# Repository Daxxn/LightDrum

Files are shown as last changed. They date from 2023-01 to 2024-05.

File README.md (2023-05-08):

# LightDrum

### Have you ever wanted the drum set to be the loudest thing on stage? Well... this won't do that, but it will be extremely visible!

---

This is my dads christmas present. (I dont even remember how long it's been...) The idea is to lay strings of LEDs on his drum set and control the strings with audio and MIDI signals. With the ability to control more lighting systems through the DMX interface. The other purpose of this project is to learn. To that end, all interface libraries are written by me and are not feature complete or fully tested.

> Current Revision: `REV12`
>
> All revisions before REV8 are early prototypes and are for archival. They are not fully functional or feature complete.

# Renders

## Main PCB

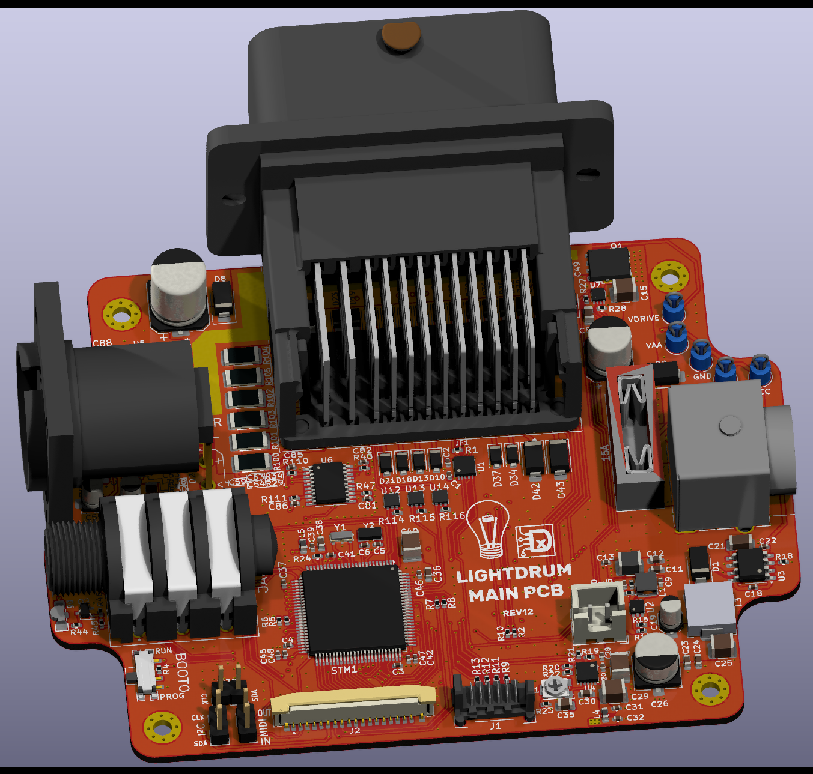
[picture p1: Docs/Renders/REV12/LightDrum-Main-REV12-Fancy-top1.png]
Render 1


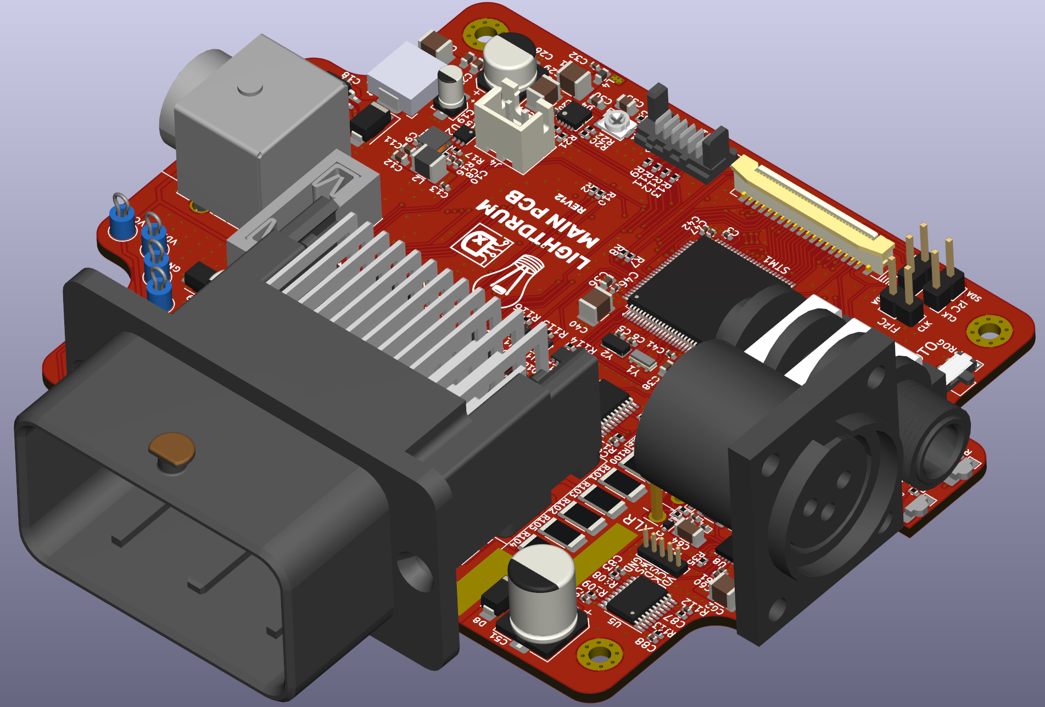
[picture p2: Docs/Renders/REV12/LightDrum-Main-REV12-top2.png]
Render 2


## Interface PCB

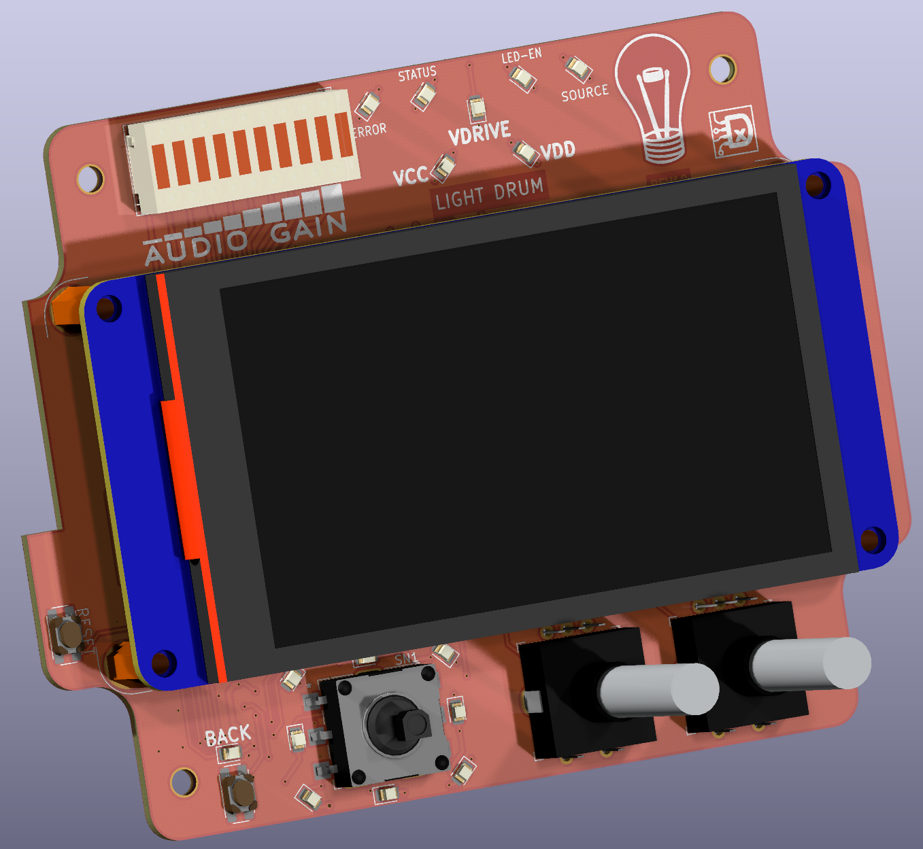
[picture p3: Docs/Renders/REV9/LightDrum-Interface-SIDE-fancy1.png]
Render 3


## Features

### Output
- 8 Individual LED String Channels
- 1 Amp Rating per Channel
- DMX (RS-485) Interface

## Input
- 1/8" jack Audio
- XLR Balanced Audio
- MIDI
- DMX (RS-485) Interface

## PWM channels

The 8 individual RGB channels are controlled with 3 [PCA9634.](https://www.nxp.com/docs/en/data-sheet/PCA9634.pdf) Providing 8-bit PWM steps per channel with overall brightness and multiplexing.

## Bulk Lighting

The new automitive ECU connector has allowed for more pins, hense, some extra features. This includes 3 linear LED drivers for white COB LEDs. These are very bright and can either be controlled through the user interface, MIDI, or audio.

## Power Management

Each channel includes current monitoring with a high-side power override. This is all to avoid shorts and over-current conditions on the high current 12V supply. Both barrel jacks will need to be used for the LEDs to be activated. Due the large amount of power required, one barrel jack would probably melt.

## Audio Processing

The PCM1821 dual channel 32bit audio ADC handles the audio conversion and is sent to the MCU via I2S. Theres some minor filtering and impedance matching in the analog front-end. However, most of the audio processing will be handled in software.

## User Interface

- 3.2" TFT LCD Display
- Navigation Hat Switch for menu navigation
- Bar Graphs for display of audio levels and current load (or anything else I can think of.)
- 2 Contextual Rotary Encoders
- AND; a reset switch. For when things go horribly wrong.
- MicroSD card slot for loading lighting profiles and other options by the user.

The display contains a full menu to select modes, configure options, and IO. I'm using a Nextion display and their GUI editor for all the menuing. Its not the most performant display but it does allow for easy integration of a reasonably high res, full color screen.

In the future, Im planning to upgrade to a faster STM32 MCU, something like an F7, H5, or H7. Taking advantage of the TouchGFX GUI design software and integrate the screen control into the main MCU. Even with the faster MCU, it will be cheaper and increase screen performance, due to the removal of the Nextion display.

---

## Documentation

- [Docs](./Docs/)

- [Interactive BOMs](./Docs/BOMs/REV10/)

- TODO: Link to a user manual and theory of operation doc.

---

## Firmware installation

### Hardware Requirements

The old firmware was built with the Arduino Framework. The new MCU will be using the ST IDE, toolchain, and HAL (Hardware Abstraction Layer) along with the other required libraries. Im using the STLink programmer due to the much better performance and debugging than the ATTiny USB programmer.

### OLD PIO Configuration

[env:megaUSB] : Uses the built-in programmer. This is only used for the older revisions. (REV1 & REV2)

[env:megaICSP] : Main programming method. Using the ATTiny USB programmer.

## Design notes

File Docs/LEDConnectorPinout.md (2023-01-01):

# LED Connector Pinout

Pinout for the main LED strip D-Sub connector.

> Pin Count : 37
> 
> Max Current: 1A

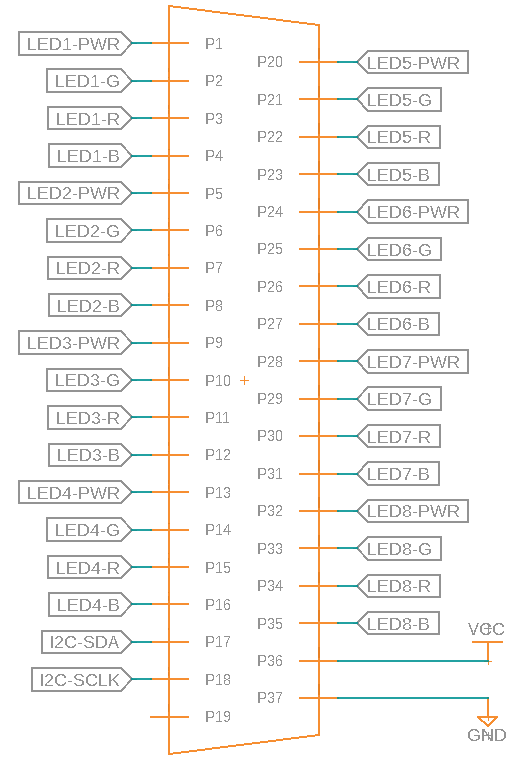
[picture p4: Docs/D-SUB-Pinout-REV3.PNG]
D-Sub Pinout Image


| # | Name | Description |
| --- | --- | --- |
| P1 | LED1-PWR | LED Strip Channel 1 +12V |
| P2 | LED1-G | Channel 1 Green |
| P3 | LED1-R | Channel 1 Red |
| P4 | LED1-B | Channel 1 Blue |
| P5 | LED2-PWR | LED Strip Channel 2 +12V |
| P6 | LED2-G | Channel 2 Green |
| P7 | LED2-R | Channel 2 Red |
| P8 | LED2-B | Channel 2 Blue |
| P9 | LED3-PWR | LED Strip Channel 3 +12V |
| P10 | LED3-G | Channel 3 Green |
| P11 | LED3-R | Channel 3 Red |
| P12 | LED3-B | Channel 3 Blue |
| P13 | LED4-PWR | LED Strip Channel 4 +12V |
| P14 | LED4-G | Channel 4 Green |
| P15 | LED4-R | Channel 4 Red |
| P16 | LED4-B | Channel 4 Blue |
| P17 | I2C-SDA | I2C Data |
| P18 | I2C-SCLK | I2C Clock |
| P19 | NC | Not Connected |
| P20 | LED5-PWR | LED Strip Channel 5 +12V |
| P21 | LED5-G | Channel 5 Green |
| P22 | LED5-R | Channel 5 Red |
| P23 | LED5-B | Channel 5 Blue |
| P24 | LED6-PWR | LED Strip Channel 6 +12V |
| P25 | LED6-G | Channel 6 Green |
| P26 | LED6-R | Channel 6 Red |
| P27 | LED6-B | Channel 6 Blue |
| P28 | LED7-PWR | LED Strip Channel 7 +12V |
| P29 | LED7-G | Channel 7 Green |
| P30 | LED7-R | Channel 7 Red |
| P31 | LED7-B | Channel 7 Blue |
| P32 | LED8-PWR | LED Strip Channel 8 +12V |
| P33 | LED8-G | Channel 8 Green |
| P34 | LED8-R | Channel 8 Red |
| P35 | LED8-B | Channel 8 Blue |
| P36 | VCC | VCC - +5V |
| P37 | GND | System Ground |

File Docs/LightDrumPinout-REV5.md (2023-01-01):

# LightDrumREV5

> > Micro: **MEGA 2560**
>
> > Digital Pins: **54**
> >
> > Analog Pins: **16**
>
> > Comms:
> > - SPI
> > - I2C
> > - UART0
> > - UART1
> > - UART2
> > - UART3

---

## Digital

### Menu
Pin Count: 6

| Pin | Name | Type
| --- | --- | --- |
| 1114 | BACK | IN |
| 8 | ACT | IN |
| 9 | UP | IN |
| 6 | LEFT | IN |
| 114 | RIGHT | IN |
| 7 | DOWN | IN |

### ROM
Pin Count: 1

| Pin | Name | Type
| --- | --- | --- |
| 1149 | WP | OUT |

### Power
Pin Count: 1

| Pin | Name | Type
| --- | --- | --- |
| 63 | STRIP_EN | OUT |

### ADC
Pin Count: 1

| Pin | Name | Type
| --- | --- | --- |
| 12 | STATUS | IN |

### Audio
Pin Count: 2

| Pin | Name | Type
| --- | --- | --- |
| 1148 | HP_SW | IN |
| 16 | AUDIO_SEL | OUT |

### Encoder
Pin Count: 6

| Pin | Name | Type
| --- | --- | --- |
| 2 | A1 | IN |
| 118 | B1 | IN |
| 10 | SW1 | IN |
| 3 | A2 | IN |
| 119 | B2 | IN |
| 11 | SW2 | IN |

### Screen
Pin Count: 11

| Pin | Name | Type
| --- | --- | --- |
| 37 | D0 | OUT |
| 36 | D1 | OUT |
| 35 | D2 | OUT |
| 34 | D3 | OUT |
| 33 | D4 | OUT |
| 32 | D5 | OUT |
| 31 | D6 | OUT |
| 30 | D7 | OUT |
| 39 | RS | OUT |
| 41 | RW | OUT |
| 40 | EN | OUT |

### Diag
Pin Count: 2

| Pin | Name | Type
| --- | --- | --- |
| 26 | STATUS | OUT |
| 27 | DEBUG | OUT |

### Graph
Pin Count: 4

| Pin | Name | Type
| --- | --- | --- |
| 17 | SDI | OUT |
| 1 | CLK | OUT |
| 4 | LE | OUT |
| 5 | OE | PWM |

### Midi
Pin Count: 1

| Pin | Name | Type
| --- | --- | --- |
| 0 | IN | IN |

### Strip
Pin Count: 1

| Pin | Name | Type
| --- | --- | --- |
| 46 | OE | OUT |

## Analog

### Audio
Pin Count: 1

| Pin | Name | Type
| --- | --- | --- |
| 10 | ARAW | IN |

### Current
Pin Count: 8

| Pin | Name | Type
| --- | --- | --- |
| 2 | ASTRIP_1 | IN |
| 5 | ASTRIP_2 | IN |
| 1 | ASTRIP_3 | IN |
| 6 | ASTRIP_4 | IN |
| 4 | ASTRIP_5 | IN |
| 3 | ASTRIP_6 | IN |
| 7 | ASTRIP_7 | IN |
| 0 | ASTRIP_8 | IN |

## Serial

### SPI

### Pins

| Name | Pin |
| --- | --- |
| SCLK | 52 |
| MISO | 50 |
| MOSI | 51 |
| SS | 53 |

### Addresses

| Name | Pin |
| --- | --- |
| ADC | 13 |

### I2C

### Pins

| Name | Pin |
| --- | --- |
| SCLK | 21 |
| SDA | 20 |

### Addresses

| Name | Pin |
| --- | --- |
| ROM | 160 |
| BackLight | 248 |
| StripA | 42 |
| StripB | 24 |
| StripC | 43 |

### UART0

### Pins

| Name | Pin |
| --- | --- |
| TX | 1 |
| RX | 0 |

### UART1

### Pins

| Name | Pin |
| --- | --- |
| TX | 18 |
| RX | 19 |

### UART2

### Pins

| Name | Pin |
| --- | --- |
| TX | 16 |
| RX | 17 |

### UART3

### Pins

| Name | Pin |
| --- | --- |
| TX | 14 |
| RX | 15 |

> Auto-generated by [PinGenerator app.](https://github.com/Daxxn/PinGenerator)
>
> Author: Daxxn

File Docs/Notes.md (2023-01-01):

# Notes and other things

* The Power Barrel Jacks need to be moved in from the edge. Theres only about 2mm from the edge of the board to the enclosure wall. OR try to find a higher current rated power connector.

* [Fixed] Add pullups to the barrel jack switches.

* [Fixed] The ICSP header needs to be moved away from the relays and any other obstructions.

* [Fixed] Still waiting on all the resistor/capacitor values for the filters.

* [Fixed] The rotary encoders need to be moved to the interface board.

* [Fixed] Look into a cable to connect the main and interface boards. The pinheader is realy hard to align and the flex during assembly is too high.

* Check the footprint and pin 1 indicator for the digital POT. Theres something wrong there.

* The brightness POT doesnt have an acceptable range. 10K is too high. The brightness goes from nothing to full only at the very end of travel.

* [Fixed] Move the XLR connector from the outside to the inside.

* [Fixed] add another MIDI connector for output communication.

* [Fixed] Move the RESET line resistor from the interface board to the main board.

* [Fixed] Move the electrolytic cap for the power supply to the top layer.

* [Fixed] Up the priority for the LED indicator power nets.

* [Fixed] Swap out the resonator for a crystal.

* [Good] TRIPLE check the symbol and footprint for the ATMEGA2560

* [Fixed] Waiting on the proper current sense resistors.

* [Fixed] Change the I2C address for Strip controller C. It was copied incorrectly from Fusion 360.

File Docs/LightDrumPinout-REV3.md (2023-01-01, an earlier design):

# LightDrum

> > Micro: **MEGA 2560**
>
> > Digital Pins: **54**
> >
> > Analog Pins: **16**
>
> > Comms:
> > - SPI
> > - I2C
> > - UART0
> > - UART1
> > - UART2
> > - UART3

---

## Digital

### LED
Pin Count: 4

| Pin | Name | Type
| --- | --- | --- |
| 36 | SDI | OUT |
| 37 | CLK | OUT |
| 40 | LE | OUT |
| 41 | OE | OUT |

### LCD
Pin Count: 11

| Pin | Name | Type
| --- | --- | --- |
| 42 | D0 | OUT |
| 43 | D1 | OUT |
| 44 | D2 | OUT |
| 45 | D3 | OUT |
| 46 | D4 | OUT |
| 49 | D5 | OUT |
| 48 | D6 | OUT |
| 47 | D7 | OUT |
| 38 | RS | OUT |
| 18 | RW | OUT |
| 19 | EN | OUT |

### POWER
Pin Count: 1

| Pin | Name | Type
| --- | --- | --- |
| 69 | RELAY | OUT |

### BUTTONS
Pin Count: 5

| Pin | Name | Type
| --- | --- | --- |
| 14 | ACT | IN |
| 27 | HOME | IN |
| 29 | M_UP | IN |
| 25 | M_DOWN | IN |
| 24 | MODE | IN |

### ENCODER
Pin Count: 6

| Pin | Name | Type
| --- | --- | --- |
| 4 | A1 | IN |
| 59 | B1 | IN |
| 0 | SW1 | IN |
| 61 | A2 | IN |
| 62 | B2 | IN |
| 60 | SW2 | IN |

### AUDIO
Pin Count: 3

| Pin | Name | Type
| --- | --- | --- |
| 34 | XLR_SW | IN |
| 31 | HP_SW | IN |
| 17 | MIDI | IN |

### INDICATOR
Pin Count: 5

| Pin | Name | Type
| --- | --- | --- |
| 22 | M_DOWN | IN |
| 28 | M_UP | IN |
| 26 | HOME | IN |
| 23 | MODE | IN |
| 39 | ACT | IN |

## Analog

### CURR_SENSE
Pin Count: 8

| Pin | Name | Type
| --- | --- | --- |
| 13 | AS0 | IN |
| 11 | AS1 | IN |
| 4 | AS2 | IN |
| 2 | AS3 | IN |
| 12 | AS4 | IN |
| 10 | AS5 | IN |
| 3 | AS6 | IN |
| 1 | AS7 | IN |

## Serial

### SPI

### Pins

| Name | Pin |
| --- | --- |
| SCLK | 52 |
| MISO | 50 |
| MOSI | 51 |
| SS | 53 |

### Select Pins

| Name | Pin |
| --- | --- |
| SPECT_CS | 68 |

### I2C

### Pins

| Name | Pin |
| --- | --- |
| SCLK | 21 |
| SDA | 20 |

### Select Pins

| Name | Pin |
| --- | --- |
| PWM_OE | 16 |

### Addresses

| Name | Pin |
| --- | --- |
| PWM0 | 1 |
| PWM1 | 2 |
| PWM2 | 3 |
| MEM | 0 |

### UART0

### Pins

| Name | Pin |
| --- | --- |
| TX | 1 |
| RX | 0 |

### UART1

### Pins

| Name | Pin |
| --- | --- |
| TX | 18 |
| RX | 19 |

### UART2

### Pins

| Name | Pin |
| --- | --- |
| TX | 16 |
| RX | 17 |

### UART3

### Pins

| Name | Pin |
| --- | --- |
| TX | 14 |
| RX | 15 |

> Auto-generated by [PinGenerator app.](https://github.com/Daxxn/PinGenerator)
>
> Author: Daxxn

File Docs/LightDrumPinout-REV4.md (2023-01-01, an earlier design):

# LightDrumREV4

> > Micro: **MEGA 2560**
>
> > Digital Pins: **54**
> >
> > Analog Pins: **16**
>
> > Comms:
> > - SPI
> > - I2C
> > - UART0
> > - UART1
> > - UART2
> > - UART3

---

## Digital

### LCD
Pin Count: 11

| Pin | Name | Type
| --- | --- | --- |
| 42 | D0 | IO |
| 43 | D1 | IO |
| 44 | D2 | IO |
| 45 | D3 | IO |
| 46 | D4 | IO |
| 49 | D5 | IO |
| 48 | D6 | IO |
| 47 | D7 | IO |
| 38 | RS | OUT |
| 18 | RW | OUT |
| 19 | EN | OUT |

### IND
Pin Count: 5

| Pin | Name | Type
| --- | --- | --- |
| 26 | HOME | OUT |
| 28 | M_UP | OUT |
| 22 | M_DN | OUT |
| 39 | ACT | OUT |
| 23 | MODE | OUT |

### ENC
Pin Count: 4

| Pin | Name | Type
| --- | --- | --- |
| 4 | ENC1_A | IN |
| 59 | ENC1_B | IN |
| 61 | ENC2_A | IN |
| 62 | ENC2_B | IN |

### SWITCH
Pin Count: 7

| Pin | Name | Type
| --- | --- | --- |
| 27 | HOME | IN |
| 14 | ACT | IN |
| 29 | M_UP | IN |
| 25 | M_DN | IN |
| 24 | MODE | IN |
| 0 | ENC1 | IN |
| 60 | ENC2 | IN |

### PWR
Pin Count: 3

| Pin | Name | Type
| --- | --- | --- |
| 111 | INV_EN | OUT |
| 69 | PWR_EN | OUT |

### AUDIO
Pin Count: 2

| Pin | Name | Type
| --- | --- | --- |
| 31 | HP_SW | IN |
| 34 | HP_XLR | OUT |

### LED
Pin Count: 5

| Pin | Name | Type
| --- | --- | --- |
| 36 | SDI | OUT |
| 37 | CLK | OUT |
| 40 | LE | OUT |
| 41 | OE | OUT |
| 16 | PWM_OE | OUT |

## Analog

### CURR
Pin Count: 8

| Pin | Name | Type
| --- | --- | --- |
| 13 | ASNS_1 | IN |
| 11 | ASNS_2 | IN |
| 4 | ASNS_3 | IN |
| 2 | ASNS_4 | IN |
| 12 | ASNS_5 | IN |
| 10 | ASNS_6 | IN |
| 3 | ASNS_7 | IN |
| 1 | ASNS_8 | IN |

## Serial

### SPI

### Pins

| Name | Pin |
| --- | --- |
| SCLK | 52 |
| MISO | 50 |
| MOSI | 51 |
| SS | 53 |

### Select Pins

| Name | Pin |
| --- | --- |
| SPECT_CS | 5 |

### I2C

### Pins

| Name | Pin |
| --- | --- |
| SCLK | 21 |
| SDA | 20 |

### Addresses

| Name | Pin |
| --- | --- |
| LED1 | 42 |
| LED2 | 24 |
| LED3 | 30 |
| ROM | 160 |

### UART0

### Pins

| Name | Pin |
| --- | --- |
| TX | 1 |
| RX | 0 |

### UART1

### Pins

| Name | Pin |
| --- | --- |
| TX | 18 |
| RX | 19 |

### UART2

### Pins

| Name | Pin |
| --- | --- |
| TX | 16 |
| RX | 17 |

### UART3

### Pins

| Name | Pin |
| --- | --- |
| TX | 14 |
| RX | 15 |

> Auto-generated by [PinGenerator app.](https://github.com/Daxxn/PinGenerator)
>
> Author: Daxxn

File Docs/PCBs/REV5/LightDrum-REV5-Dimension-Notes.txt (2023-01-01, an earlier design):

height from top: 33.16
len from side: 15.65

possible cosin error: 0.4

lip height: 1.48

inner wall height: 39.26

main PCB level: 30.18

dsub center to edge: 49
dsub outer shield width: 56.3 | 28.15
dsub outer shield height: 9.4 | 4.7

top-jack y len: 34.96
bot-jack y len: 49.96
jack spacing: 15

jack width: 8.95
jack: height: 10.85

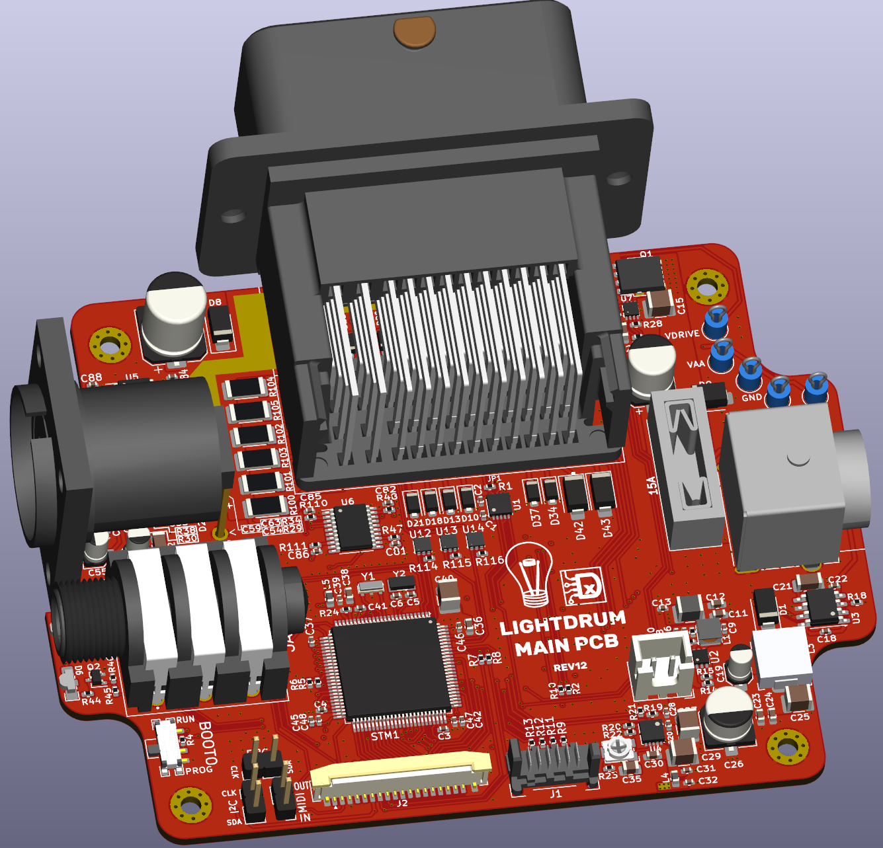
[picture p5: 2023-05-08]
Docs/Renders/REV12/LightDrum-Main-REV12-top1.png

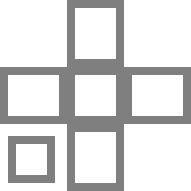
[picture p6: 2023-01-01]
Docs/D-Pad.png

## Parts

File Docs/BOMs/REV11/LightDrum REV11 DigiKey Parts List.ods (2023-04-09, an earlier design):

I | Digi-Key Part # | Manufacturer Part # | Description | Req QTY | Pack QTY | Pack Type | Unit Price | Extended Price | Min QTY | Availability | Stock Status | Customer Reference | Manufacturer Name | Datasheet
1 | 296-PCM1821IRTERCT-ND | PCM1821IRTER | STEREO-CHANNEL, 32-BIT, 192-KHZ, | 1 | 1 | Cut Tape (CT) | 4.05000 | $4.05 | 1 | 5,576 | In Stock |  | Texas Instruments | https://www.ti.com/general/docs/suppproductinfo.tsp?distId=10&gotoUrl=https://www.ti.com/lit/gpn/pcm1821
2 | 497-18547-ND | STM32F412VET3 | IC MCU 32BIT 512KB FLASH 100LQFP | 1 | 1 | Tray | 12.40000 | $12.40 | 1 | 472 | In Stock |  | STMicroelectronics | https://www.st.com/content/ccc/resource/technical/document/datasheet/15/90/07/b3/8c/10/4e/95/DM00213872.pdf/files/DM00213872.pdf/jcr:content/translations/en.D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
3 | 401-2016-1-ND | PCM12SMTR | SWITCH SLIDE SPDT 300MA 6V | 1 | 1 | Cut Tape (CT) | 0.93000 | $0.93 | 1 | 28,298 | In Stock |  | C&K | https://www.ckswitches.com/media/1424/pcm.pdf
4 | 568-4066-1-ND | PCA9634PW,118 | IC LED DRVR PS I2C 25MA 20TSSOP | 3 | 3 | Cut Tape (CT) | 2.15000 | $6.45 | 1 | 1,482 | In Stock |  | NXP USA Inc. | https://www.nxp.com/docs/en/data-sheet/PCA9634.pdf
5 | 1827-1047-1-ND | SLG55021-200010V | IC GATE DRVR HIGH-SIDE 8TDFN | 1 | 1 | Cut Tape (CT) | 0.63000 | $0.63 | 1 | 337,781 | In Stock |  | Renesas Design Germany GmbH | https://www.renesas.com/us/en/document/dst/slg55021-200010v-datasheet?language=en
6 | 497-18335-1-ND | STR485LVQT | IC TRANSCEIVER HALF 1/1 10DFN | 1 | 1 | Cut Tape (CT) | 4.50000 | $4.50 | 1 | 18,992 | In Stock |  | STMicroelectronics | https://www.st.com/resource/en/datasheet/str485.pdf
7 | 296-49082-1-ND | INA4181A2IPWR | IC CURR SENSE 4 CIRCUIT 20TSSOP | 2 | 2 | Cut Tape (CT) | 1.25000 | $2.50 | 1 | 5,568 | In Stock |  | Texas Instruments | https://www.ti.com/general/docs/suppproductinfo.tsp?distId=10
8 | AP3401DNTR-G1DICT-ND | AP3401DNTR-G1 | IC REG BUCK ADJ 1A UDFN2020-6 | 1 | 1 | Cut Tape (CT) | 0.45000 | $0.45 | 1 | 261,637 | In Stock |  | Diodes Incorporated | https://www.diodes.com/assets/Datasheets/AP3401.pdf
9 | LM22673MRE-5.0/NOPBCT-ND | LM22673MRE-5.0/NOPB | IC REG BUCK 5V 3A 8SOPWR | 1 | 1 | Cut Tape (CT) | 6.04000 | $6.04 | 1 | 3,893 | In Stock |  | Texas Instruments | https://www.ti.com/general/docs/suppproductinfo.tsp?distId=10
10 | 296-TPS7A9401DSCRCT-ND | TPS7A9401DSCR | 1-A, ULTRA-LOW NOISE, ULTRA-HIGH | 1 | 1 | Cut Tape (CT) | 7.32000 | $7.32 | 1 | 5,948 | In Stock |  | Texas Instruments | https://www.ti.com/lit/ds/symlink/tps7a94.pdf
11 | XC1617CT-ND | ECS-.327-12.5-34B-TR | CRYSTAL 32.7680KHZ 12.5PF SMD | 1 | 1 | Cut Tape (CT) | 0.68000 | $0.68 | 1 | 618,648 | In Stock |  | ECS Inc. | https://ecsxtal.com/store/pdf/ecx-31b.pdf
12 | 490-17948-1-ND | CSTNE16M0V530000R0 | CERAMIC RES 16.0000MHZ 15PF SMD | 1 | 1 | Cut Tape (CT) | 0.25000 | $0.25 | 1 | 150,216 | In Stock |  | Murata Electronics | https://www.murata.com/en/products/productdata/8801162231838/SPEC-CSTNE16M0V530000R0.pdf
13 | 118-TC33X-1-472ECT-ND | TC33X-1-472E | TRIMMER 4.7K OHM 0.1W J LEAD TOP | 1 | 1 | Cut Tape (CT) | 0.28000 | $0.28 | 1 | 4,990 | In Stock |  | Bourns Inc. | https://www.bourns.com/docs/Product-Datasheets/TC33.pdf
14 | 264-CEZ5V6L3FCT-ND | CEZ5V6,L3F | TVS DIODE 5.6VWM 9VC ESC | 4 | 4 | Cut Tape (CT) | 0.31000 | $1.24 | 1 | 7,011 | In Stock |  | Toshiba Semiconductor and Storage | https://toshiba.semicon-storage.com/info/CEZ5V6_datasheet_en_20201026.pdf?did=69323&prodName=CEZ5V6
15 | SMAJ14CA-FDICT-ND | SMAJ14CA-13-F | TVS DIODE 14VWM 23.2VC SMA | 36 | 36 | Cut Tape (CT) | 0.33000 | $11.88 | 1 | 170,451 | In Stock |  | Diodes Incorporated | https://www.diodes.com/assets/Datasheets/SMAJ5.0CA-SMAJ200CA.pdf
16 | 160-2217-1-ND | LTST-S321TBKT | LED BLUE CLEAR 1208 SMD R/A | 2 | 2 | Cut Tape (CT) | 0.36000 | $0.72 | 1 | 36,099 | In Stock |  | Lite-On Inc. | https://optoelectronics.liteon.com/upload/download/DS22-2010-0048/LTST-S321TBKT.pdf
17 | 353-SK36AHE3-LTPCT-ND | SK36AHE3-LTP | DIODE SCHOTTKY 60V 3A DO214AC | 1 | 1 | Cut Tape (CT) | 0.36000 | $0.36 | 1 | 4,900 | In Stock |  | Micro Commercial Co | https://www.mccsemi.com/pdf/Products/SK34AHE3-L-SK310AHE3-L(DO-214AC).pdf
18 | 36-3557-10-ND | 3557-10 | FUSE HOLDER BLADE 30A PCB | 1 | 1 | Bulk | 1.33000 | $1.33 | 1 | 3,903 | In Stock |  | Keystone Electronics | https://www.keyelco.com/userAssets/file/M65p41.pdf
19 | 952-3602-ND | M50-3530642 | CONN HEADER VERT 6POS 1.27MM | 1 | 1 | Box | 0.29000 | $0.29 | 1 | 27,033 | In Stock |  | Harwin Inc. | https://cdn.harwin.com/pdfs/C029XX_M50_and_M52_Series_Connectors.pdf
20 | 2223-SJ-63073E-ND | SJ-63073E | AUDIO JACK, 6.35 MM, HORIZONTAL, | 1 | 1 | Bag | 1.87000 | $1.87 | 1 | 643 | In Stock |  | CUI Devices | https://www.cuidevices.com/product/resource/sj-6307.pdf
21 | 4654-CP30082-ND | CP30082 | FEMALE AIRTIGHT XLR CONNECTOR 90 | 1 | 1 | Box | 8.32000 | $8.32 | 1 | 17 | In Stock |  | CLIFF Electronic Components Ltd | https://www.cliffusa.com/products/xlr/AirtightXLR.pdf
22 | 182-37ME-ND | 182-037-113R531 | CONN D-SUB PLUG 37POS R/A SLDR | 1 | 1 | Tray | 4.22000 | $4.22 | 1 | 6,577 | In Stock |  | NorComp Inc. | https://content.norcomp.net/rohspdfs/Connectors/18Y/182/182-yyy-113Ryy1.pdf
23 | 2092-KPJXHT-4S-S-ND | KPJXHT-4S-S | CONN JACK FMALE 4POS TIN SOLDER | 1 | 1 | Tray | 2.89000 | $2.89 | 1 | 4,408 | In Stock |  | Kycon, Inc. | https://www.kycon.com/Pub_Eng_Draw/KPJXHT-4S-S.pdf
24 | WM7988CT-ND | 0525593652 | CONN FFC VERT 36POS 0.5MM SMD | 1 | 1 | Cut Tape (CT) | 4.91000 | $4.91 | 1 | 13,038 | In Stock |  | Molex | https://www.molex.com/pdm_docs/sd/525593652_sd.pdf
25 | WM6784CT-ND | 0541323662 | CONN FFC BOTTOM 36POS 0.5MM R/A | 1 | 1 | Cut Tape (CT) | 2.30000 | $2.30 | 1 | 3,837 | In Stock |  | Molex | https://www.molex.com/pdm_docs/sd/541323662_sd.pdf
26 | 455-2247-ND | B2B-XH-A(LF)(SN) | CONN HEADER VERT 2POS 2.5MM | 2 | 2 | Bulk | 0.15000 | $0.30 | 1 | 1,157,609 | In Stock |  | JST Sales America Inc. | https://www.jst-mfg.com/product/pdf/eng/eXH.pdf
27 | 732-6275-1-ND | 744786210A | FIXED IND 100NH 300MA 1.2OHM SMD | 3 | 3 | Cut Tape (CT) | 0.21000 | $0.63 | 1 | 14,176 | In Stock |  | Würth Elektronik | https://www.we-online.com/katalog/datasheet/744786210A.pdf
28 | 490-15950-1-ND | LQH3NPN2R2MMEL | FIXED IND 2.2UH 1.22A 78MOHM SMD | 1 | 1 | Cut Tape (CT) | 0.42000 | $0.42 | 1 | 55,677 | In Stock |  | Murata Electronics | https://search.murata.co.jp/Ceramy/image/img/P02/JELF243A-0153.pdf
29 | 553-4011-1-ND | PA4341.223ANLT | FIXED IND 22UH 2.5A 190 MOHM SMD | 1 | 1 | Cut Tape (CT) | 1.11000 | $1.11 | 1 | 4,826 | In Stock |  | Pulse Electronics | https://productfinder.pulseelectronics.com/api/open/part-attachments/datasheet/PA4341.223ANLT
30 | NTMFS5C430NLT1GOSCT-ND | NTMFS5C430NLT1G | MOSFET N-CH 40V 200A 5DFN | 1 | 1 | Cut Tape (CT) | 2.24000 | $2.24 | 1 | 41,366 | In Stock |  | onsemi | https://www.onsemi.com/pdf/datasheet/ntmfs5c430nl-d.pdf
31 | 1727-NX6008NBKWXCT-ND | NX6008NBKWX | NX6008NBKW/SOT323/SC-70 | 6 | 6 | Cut Tape (CT) | 0.23000 | $1.38 | 1 | 63,146 | In Stock |  | Nexperia USA Inc. | https://assets.nexperia.com/documents/data-sheet/NX6008NBKW.pdf
32 | 1727-PMXB43UNEZCT-ND | PMXB43UNEZ | MOSFET N-CH 20V 3.2A DFN1010D-3 | 24 | 24 | Cut Tape (CT) | 0.37000 | $8.88 | 1 | 94,617 | In Stock |  | Nexperia USA Inc. | https://assets.nexperia.com/documents/data-sheet/PMXB43UNE.pdf
33 | 311-10KJRCT-ND | RC0402JR-0710KL | RES 10K OHM 5% 1/16W 0402 | 44 | 100 | Cut Tape (CT) | 0.00820 | $0.82 | 1 | 39,784,616 | In Stock |  | YAGEO | https://www.yageo.com/upload/media/product/productsearch/datasheet/rchip/PYu-RC_Group_51_RoHS_L_12.pdf
34 | 1276-6849-1-ND | CL05C220JB51PNC | CAP CER 22PF 50V C0G/NP0 0402 | 1 | 1 | Cut Tape (CT) | 0.10000 | $0.10 | 1 | 1,749,789 | In Stock |  | Samsung Electro-Mechanics | https://media.digikey.com/pdf/Data%20Sheets/Samsung%20PDFs/CL05C220JB51PNC_Spec.pdf
35 | 1276-6610-1-ND | CL05C470JB51PNC | CAP CER 47PF 50V C0G/NP0 0402 | 2 | 2 | Cut Tape (CT) | 0.10000 | $0.20 | 1 | 659,743 | In Stock |  | Samsung Electro-Mechanics | https://media.digikey.com/pdf/Data%20Sheets/Samsung%20PDFs/CL05C470JB51PNC_Spec.pdf
36 | 1276-1117-1-ND | CL05C471JB5NNNC | CAP CER 470PF 50V C0G/NP0 0402 | 10 | 10 | Cut Tape (CT) | 0.03100 | $0.31 | 1 | 755,442 | In Stock |  | Samsung Electro-Mechanics | https://media.digikey.com/pdf/Data%20Sheets/Samsung%20PDFs/CL05C471JB5NNNC_Spec.pdf
37 | 1276-1028-1-ND | CL05B103KB5NNNC | CAP CER 10000PF 50V X7R 0402 | 1 | 1 | Cut Tape (CT) | 0.10000 | $0.10 | 1 | 11,684,930 | In Stock |  | Samsung Electro-Mechanics | https://media.digikey.com/pdf/Data%20Sheets/Samsung%20PDFs/CL05B103KB5NNN_Spec.pdf
38 | 1276-1043-1-ND | CL05A104KA5NNNC | CAP CER 0.1UF 25V X5R 0402 | 36 | 50 | Cut Tape (CT) | 0.00540 | $0.27 | 1 | 25,861,495 | In Stock |  | Samsung Electro-Mechanics | https://media.digikey.com/pdf/Data%20Sheets/Samsung%20PDFs/CL05A104KA5NNNC.pdf
39 | 1276-1102-1-ND | CL10A105KA8NNNC | CAP CER 1UF 25V X5R 0603 | 11 | 11 | Cut Tape (CT) | 0.03100 | $0.34 | 1 | 1,051,944 | In Stock |  | Samsung Electro-Mechanics | https://media.digikey.com/pdf/Data%20Sheets/Samsung%20PDFs/CL10A105KA8NNNC_Spec.pdf
40 | 399-C0402C150G5HACAUTOCT-ND | C0402C150G5HACAUTO | CAP CER 0402 15PF 50V ULTRA STAB | 2 | 2 | Cut Tape (CT) | 0.13000 | $0.26 | 1 | 42,525 | In Stock |  | KEMET | https://connect.kemet.com:7667/gateway/IntelliData-ComponentDocumentation/1.0/download/datasheet/C0402C150G5HACAUTO
41 | 478-11437-1-ND | 0402ZD225MAT2A | CAP CER 2.2UF 10V X5R 0402 | 2 | 2 | Cut Tape (CT) | 0.10000 | $0.20 | 1 | 70,224 | In Stock |  | KYOCERA AVX | https://datasheets.kyocera-avx.com/cx5r.pdf
42 | 1276-6722-1-ND | CL21A475KLCLQNC | CAP CER 4.7UF 35V X5R 0805 | 3 | 3 | Cut Tape (CT) | 0.18000 | $0.54 | 1 | 850,283 | In Stock |  | Samsung Electro-Mechanics | https://media.digikey.com/pdf/Data%20Sheets/Samsung%20PDFs/CL21A475KLCLQNC_Spec.pdf
43 | 1276-1854-1-ND | CL32A106KAULNNE | CAP CER 10UF 25V X5R 1210 | 6 | 6 | Cut Tape (CT) | 0.33000 | $1.98 | 1 | 5,774,137 | In Stock |  | Samsung Electro-Mechanics | https://media.digikey.com/pdf/Data%20Sheets/Samsung%20PDFs/CL32A106KAULNNE_Spec.pdf
44 | 732-13322-1-ND | 865090368008 | CAP ALUM 10UF 20% 16V SMD | 5 | 5 | Cut Tape (CT) | 0.31000 | $1.55 | 1 | 44,647 | In Stock |  | Würth Elektronik | https://www.we-online.com/katalog/datasheet/865090368008.pdf
45 | 490-10531-1-ND | GRM32EC81C476KE15L | CAP CER 47UF 16V X6S 1210 | 1 | 1 | Cut Tape (CT) | 0.51000 | $0.51 | 1 | 290,906 | In Stock |  | Murata Electronics | https://search.murata.co.jp/Ceramy/image/img/A01X/G101/ENG/GRM32EC81C476KE15-01.pdf
46 | 1276-3376-1-ND | CL32A476KOJNNNE | CAP CER 47UF 16V X5R 1210 | 1 | 1 | Cut Tape (CT) | 0.72000 | $0.72 | 1 | 1,349,322 | In Stock |  | Samsung Electro-Mechanics | http://weblib.samsungsem.com/mlcc/mlcc-ec-data-sheet.do?partNumber=CL32A476KOJNNN
47 | 565-EMVY500ARA470MF80GCT-ND | EMVY500ARA470MF80G | CAP ALUM 47UF 20% 50V SMD | 2 | 2 | Cut Tape (CT) | 0.48000 | $0.96 | 1 | 107,792 | In Stock |  | United Chemi-Con | https://www.chemi-con.co.jp/products/relatedfiles/capacitor/catalog/MVYRA-e.PDF
48 | 565-EMVE160ARA101MF55GCT-ND | EMVE160ARA101MF55G | CAP ALUM 100UF 20% 16V SMD | 1 | 1 | Cut Tape (CT) | 0.36000 | $0.36 | 1 | 108,518 | In Stock |  | United Chemi-Con | https://media.digikey.com/pdf/Data%20Sheets/United%20Chemi-Con%20PDFs/MVE%20Series.pdf
49 | 493-2205-1-ND | UWT1V221MNL1GS | CAP ALUM 220UF 20% 35V SMD | 1 | 1 | Cut Tape (CT) | 0.61000 | $0.61 | 1 | 3,942 | In Stock |  | Nichicon | https://products.nichicon.co.jp/en/pdf/XJA043/e-uwt.pdf
50 | 0150200387-ND | 0150200387 | CABLE FFC 36POS 0.50MM 4" | 1 | 1 | Bag | 3.80000 | $3.80 | 1 | 931 | In Stock |  | Molex | https://www.molex.com/webdocs/datasheets/pdf/en-us/0150200387_CABLE.pdf
51 | 541-10110-1-ND | WSLT2010R0500FEA18 | RES 0.05 OHM 1% 1W 2010 | 10 | 10 | Cut Tape (CT) | 0.86400 | $8.64 | 1 | 4,213 | In Stock |  | Vishay Dale | https://www.vishay.com/docs/30138/wslt2010.pdf
52 | RMCF0402FT100RCT-ND | RMCF0402FT100R | RES 100 OHM 1% 1/16W 0402 | 28 | 28 | Cut Tape (CT) | 0.01400 | $0.39 | 1 | 2,476,586 | In Stock |  | Stackpole Electronics Inc | https://www.seielect.com/Catalog/SEI-RMCF_RMCP.pdf
53 | 2037-PFR05S-220-FNHCT-ND | PFR05S-220-FNH | RES SMD 22 OHM 1% 1/16W 0402 | 10 | 10 | Cut Tape (CT) | 0.01400 | $0.14 | 1 | 754,489 | In Stock |  | Delta Electronics/Cyntec | https://download.datasheets.com/pdfs/2018/12/14/19/32/22/975901/cyn_/manual/cynts00024-1.pdf
54 | 311-47JRCT-ND | RC0402JR-0747RL | RES 47 OHM 5% 1/16W 0402 | 1 | 1 | Cut Tape (CT) | 0.10000 | $0.10 | 1 | 1,536,756 | In Stock |  | YAGEO | https://www.yageo.com/upload/media/product/productsearch/datasheet/rchip/PYu-RC_Group_51_RoHS_L_12.pdf
55 | 311-120LRCT-ND | RC0402FR-07120RL | RES 120 OHM 1% 1/16W 0402 | 1 | 1 | Cut Tape (CT) | 0.10000 | $0.10 | 1 | 856,179 | In Stock |  | YAGEO | https://www.yageo.com/upload/media/product/productsearch/datasheet/rchip/PYu-RC_Group_51_RoHS_L_12.pdf
56 | 311-1.0KJRCT-ND | RC0402JR-071KL | RES 1K OHM 5% 1/16W 0402 | 10 | 10 | Cut Tape (CT) | 0.01800 | $0.18 | 1 | 17,485,509 | In Stock |  | YAGEO | https://www.yageo.com/upload/media/product/productsearch/datasheet/rchip/PYu-RC_Group_51_RoHS_L_12.pdf
57 | 311-2.2KJRCT-ND | RC0402JR-072K2L | RES 2.2K OHM 5% 1/16W 0402 | 10 | 10 | Cut Tape (CT) | 0.01800 | $0.18 | 1 | 918,985 | In Stock |  | YAGEO | https://www.yageo.com/upload/media/product/productsearch/datasheet/rchip/PYu-RC_Group_51_RoHS_L_12.pdf
58 | 2037-PFR05S-153-FNHCT-ND | PFR05S-153-FNH | RES SMD 15 KOHM 1% 1/16W 0402 | 1 | 1 | Cut Tape (CT) | 0.10000 | $0.10 | 1 | 1,024,415 | In Stock |  | Delta Electronics/Cyntec | https://download.datasheets.com/pdfs/2018/12/14/19/32/22/975901/cyn_/manual/cynts00024-1.pdf
59 | 311-20.0KLRCT-ND | RC0402FR-0720KL | RES 20K OHM 1% 1/16W 0402 | 1 | 1 | Cut Tape (CT) | 0.10000 | $0.10 | 1 | 5,108,955 | In Stock |  | YAGEO | https://www.yageo.com/upload/media/product/productsearch/datasheet/rchip/PYu-RC_Group_51_RoHS_L_12.pdf
60 | 311-33.0KLRCT-ND | RC0402FR-0733KL | RES 33K OHM 1% 1/16W 0402 | 1 | 1 | Cut Tape (CT) | 0.10000 | $0.10 | 1 | 2,166,297 | In Stock |  | YAGEO | https://www.yageo.com/upload/media/product/productsearch/datasheet/rchip/PYu-RC_Group_51_RoHS_L_12.pdf
61 | RMCF0402FT100KCT-ND | RMCF0402FT100K | RES 100K OHM 1% 1/16W 0402 | 10 | 10 | Cut Tape (CT) | 0.01400 | $0.14 | 1 | 8,471,317 | In Stock |  | Stackpole Electronics Inc | https://www.seielect.com/Catalog/SEI-RMCF_RMCP.pdf
62 | RMCF0402FT1M54CT-ND | RMCF0402FT1M54 | RES 1.54M OHM 1% 1/16W 0402 | 1 | 1 | Cut Tape (CT) | 0.10000 | $0.10 | 1 | 12,277 | In Stock |  | Stackpole Electronics Inc | https://www.seielect.com/Catalog/SEI-RMCF_RMCP.pdf
63 | YAG3151CT-ND | RC0402FR-07402KL | RES 402K OHM 1% 1/16W 0402 | 1 | 1 | Cut Tape (CT) | 0.10000 | $0.10 | 1 | 1,108,526 | In Stock |  | YAGEO | https://www.yageo.com/upload/media/product/productsearch/datasheet/rchip/PYu-RC_Group_51_RoHS_L_12.pdf
64 | RMCF0402FT430KCT-ND | RMCF0402FT430K | RES 430K OHM 1% 1/16W 0402 | 1 | 1 | Cut Tape (CT) | 0.10000 | $0.10 | 1 | 73,300 | In Stock |  | Stackpole Electronics Inc | https://www.seielect.com/Catalog/SEI-RMCF_RMCP.pdf
65 | 445-7694-1-ND | C3216C0G1H104J160AA | CAP CER 0.1UF 50V C0G 1206 | 3 | 3 | Cut Tape (CT) | 0.59000 | $1.77 | 1 | 169,883 | In Stock |  | TDK Corporation | https://product.tdk.com/system/files/dam/doc/product/capacitor/ceramic/mlcc/catalog/mlcc_commercial_general_en.pdf
66 | YAG2306CT-ND | RT0402BRE071KL | RES SMD 1K OHM 0.1% 1/16W 0402 | 2 | 2 | Cut Tape (CT) | 0.40000 | $0.80 | 1 | 125,414 | In Stock |  | YAGEO | https://www.yageo.com/upload/media/product/productsearch/datasheet/rchip/PYu-RT_1-to-0.01_RoHS_L_13.pdf
67 | 1276-1935-1-ND | CL10B104KB8NNWC | CAP CER 0.1UF 50V X7R 0603 | 10 | 10 | Cut Tape (CT) | 0.01900 | $0.19 | 1 | 5,073,587 | In Stock |  | Samsung Electro-Mechanics | https://media.digikey.com/pdf/Data%20Sheets/Samsung%20PDFs/CL10B104KB8NNWC_Spec.pdf
68 | 1276-1102-1-ND | CL10A105KA8NNNC | CAP CER 1UF 25V X5R 0603 | 1 | 1 | Cut Tape (CT) | 0.10000 | $0.10 | 1 | 1,051,944 | In Stock |  | Samsung Electro-Mechanics | https://media.digikey.com/pdf/Data%20Sheets/Samsung%20PDFs/CL10A105KA8NNNC_Spec.pdf
69 | 160-1423-1-ND | LTST-C171GKT | LED GREEN CLEAR CHIP SMD | 2 | 2 | Cut Tape (CT) | 0.26000 | $0.52 | 1 | 164,622 | In Stock |  | Lite-On Inc. | https://media.digikey.com/pdf/Data%20Sheets/Lite-On%20PDFs/LTST-C171GKT.pdf
70 | 1830-1081-1-ND | IN-S85ATA | LED AMBER CLEAR 0805 SMD | 1 | 1 | Cut Tape (CT) | 0.33000 | $0.33 | 1 | 6,757 | In Stock |  | Inolux | https://www.inolux-corp.com/datasheet/SMDLED/Mono%20Color%20Top%20View/IN-S85AT%20Series_V1.1.pdf
71 | 1497-1208-1-ND | XZUR54W-1 | LED RED CLEAR CHIP SMD | 10 | 10 | Cut Tape (CT) | 0.24200 | $2.42 | 1 | 9,247 | In Stock |  | SunLED | https://www.sunledusa.com/products/spec/XZUR54W-1.pdf
72 | 1497-1118-1-ND | XZCBD54W-1 | LED BLUE CLEAR CHIP SMD | 3 | 3 | Cut Tape (CT) | 0.44000 | $1.32 | 1 | 46,781 | In Stock |  | SunLED | https://www.sunledusa.com/products/spec/XZCBD54W-1.pdf
73 | 1N4148WS-FDICT-ND | 1N4148WS-7-F | DIODE GEN PURP 75V 150MA SOD323 | 1 | 1 | Cut Tape (CT) | 0.18000 | $0.18 | 1 | 243,643 | In Stock |  | Diodes Incorporated | https://www.diodes.com/assets/Datasheets/1N4148WS_BAV16WS.pdf
74 | 160-1066-ND | LTA-1000HR | LED BAR GRAPH 10-SEGMENT RED | 1 | 1 | Tube | 1.38000 | $1.38 | 1 | 8,808 | In Stock |  | Lite-On Inc. | https://optoelectronics.liteon.com/upload/download/DS-30-92-0810/LTA-1000HR.pdf
75 | PEC11R-4215F-S0024-ND | PEC11R-4215F-S0024 | ROTARY ENCODER MECHANICAL 24PPR | 2 | 2 | Tray | 2.08000 | $4.16 | 1 | 22,472 | In Stock |  | Bourns Inc. | https://www.bourns.com/docs/Product-Datasheets/PEC11R.pdf
76 | EG5384CT-ND | TL3365AF180QG | SWITCH TACTILE SPST-NO 0.05A 12V | 2 | 2 | Cut Tape (CT) | 0.34000 | $0.68 | 1 | 56,255 | In Stock |  | E-Switch | https://sten-eswitch-13110800-production.s3.amazonaws.com/system/asset/product_line/data_sheet/218/TL3365.pdf
77 | EG4561-ND | JS5208 | SWITCH NAVIGATION 20MA 15V | 1 | 1 | Bulk | 3.27000 | $3.27 | 1 | 6,424 | In Stock |  | E-Switch | https://media.digikey.com/PDF/Data%20Sheets/E-Switch%20PDFs/JS5208%20Series.pdf
78 | 497-5743-1-ND | STP16CP05MTR | IC LED DRIVER LINEAR 100MA 24SO | 1 | 1 | Cut Tape (CT) | 2.24000 | $2.24 | 1 | 13,279 | In Stock |  | STMicroelectronics | https://www.st.com/content/ccc/resource/technical/document/datasheet/f2/92/00/f9/dd/4a/43/22/CD00126634.pdf/files/CD00126634.pdf/jcr:content/translations/en.C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
79 | 296-29677-1-ND | TPL0401B-10DCKR | IC DGTL POT 10KOHM 128TAP SC70-6 | 1 | 1 | Cut Tape (CT) | 1.28000 | $1.28 | 1 | 5,555 | In Stock |  | Texas Instruments | https://www.ti.com/general/docs/suppproductinfo.tsp?distId=10
80 | 296-27353-1-ND | SN74AUP2G04DCKR | IC INVERTER 2CH 2-INP SC70-6 | 1 | 1 | Cut Tape (CT) | 0.61000 | $0.61 | 1 | 70,210 | In Stock |  | Texas Instruments | https://www.ti.com/general/docs/suppproductinfo.tsp?distId=10
81 | 2073-MEM2061-01-188-00-ACT-ND | MEM2061-01-188-00-A | MICRO SD PUSH PUSH, CLOSED, SMT, | 1 | 1 | Cut Tape (CT) | 1.20000 | $1.20 | 1 | 10,727 | In Stock |  | GCT | https://gct.co/files/specs/mem2061-spec.pdf
82 | 2007-APC-817A1-SLCT-ND | APC-817A1-SL | OPTOISOLATOR 5KV 1CH TRANS 4SMD | 1 | 1 | Cut Tape (CT) | 0.42000 | $0.42 | 1 | 47,399 | In Stock |  | American Bright Optoelectronics Corporation | https://www.americanbrightled.com/pdffiles/ir-uv/ir/APC-817.pdf
83 | 311-300LRCT-ND | RC0402FR-07300RL | RES 300 OHM 1% 1/16W 0402 | 4 | 10 | Cut Tape (CT) | 0.01500 | $0.15 | 1 | 2,210,508 | In Stock |  | YAGEO | https://www.yageo.com/upload/media/product/productsearch/datasheet/rchip/PYu-RC_Group_51_RoHS_L_12.pdf
84 | RMCF0402FT4K70CT-ND | RMCF0402FT4K70 | RES 4.7K OHM 1% 1/16W 0402 | 1 | 1 | Cut Tape (CT) | 0.10000 | $0.10 | 1 | 7,929,713 | In Stock |  | Stackpole Electronics Inc | https://www.seielect.com/Catalog/SEI-RMCF_RMCP.pdf
85 | 1292-WR04X221JTLCT-ND | WR04X221 JTL | RES 220 OHM 5% 1/16W 0402 | 3 | 10 | Cut Tape (CT) | 0.01000 | $0.10 | 1 | 40,346 | In Stock |  | Walsin Technology Corporation | http://www.passivecomponent.com/wp-content/uploads/chipR/ASC_WR.pdf
86 | 13-RC0402FR-13560RLCT-ND | RC0402FR-13560RL | RES 560 OHM 1% 1/16W 0402 | 3 | 10 | Cut Tape (CT) | 0.01500 | $0.15 | 1 | 165,972 | In Stock |  | YAGEO | https://www.yageo.com/upload/media/product/productsearch/datasheet/rchip/PYu-RC_Group_51_RoHS_L_12.pdf
87 | 311-620LRCT-ND | RC0402FR-07620RL | RES 620 OHM 1% 1/16W 0402 | 1 | 1 | Cut Tape (CT) | 0.10000 | $0.10 | 1 | 319,185 | In Stock |  | YAGEO | https://www.yageo.com/upload/media/product/productsearch/datasheet/rchip/PYu-RC_Group_51_RoHS_L_12.pdf
88 | YAG3036CT-ND | RC0402FR-071K3L | RES 1.3K OHM 1% 1/16W 0402 | 1 | 1 | Cut Tape (CT) | 0.10000 | $0.10 | 1 | 531,639 | In Stock |  | YAGEO | https://www.yageo.com/upload/media/product/productsearch/datasheet/rchip/PYu-RC_Group_51_RoHS_L_12.pdf
89 | 311-47.0KLRCT-ND | RC0402FR-0747KL | RES 47K OHM 1% 1/16W 0402 | 5 | 10 | Cut Tape (CT) | 0.01500 | $0.15 | 1 | 3,936,361 | In Stock |  | YAGEO | https://www.yageo.com/upload/media/product/productsearch/datasheet/rchip/PYu-RC_Group_51_RoHS_L_12.pdf
90 | 490-GRM31C5C1E224JE02LCT-ND | GRM31C5C1E224JE02L | CAP CER 0.22UF 25V C0G/NP0 1206 | 2 | 2 | Cut Tape (CT) | 0.45000 | $0.90 | 1 | 3,955 | In Stock |  | Murata Electronics | https://search.murata.co.jp/Ceramy/image/img/A01X/G101/ENG/GRM31C5C1E224JE02-01A.pdf
91 | 13-RE1206FRE0710KLCT-ND | RE1206FRE0710KL | RES SMD 10K OHM 1% 1/4W 1206 | 1 | 1 | Cut Tape (CT) | 0.10000 | $0.10 | 1 | 103,766 | In Stock |  | YAGEO | https://www.yageo.com/upload/media/product/productsearch/datasheet/rchip/PYu-RE_105_RoHS_L_6.pdf
92 | 36-5000-ND | 5000 | PC TEST POINT MINIATURE RED | 4 | 4 | Bulk | 0.42000 | $1.68 | 1 | 764,542 | In Stock |  | Keystone Electronics | https://www.keyelco.com/userAssets/file/M65p56.pdf
93 | 36-5001-ND | 5001 | PC TEST POINT MINIATURE BLACK | 1 | 1 | Bulk | 0.42000 | $0.42 | 1 | 757,999 | In Stock |  | Keystone Electronics | https://www.keyelco.com/userAssets/file/M65p56.pdf
94 | 36-5002-ND | 5002 | PC TEST POINT MINIATURE WHITE | 4 | 4 | Bulk | 0.42000 | $1.68 | 1 | 1,539,861 | In Stock |  | Keystone Electronics | https://www.keyelco.com/userAssets/file/M65p56.pdf

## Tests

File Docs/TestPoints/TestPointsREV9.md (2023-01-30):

# REV4 Test Points

## Power Rails
| Name | Description |
|---|---|
| 12V | Main 12V Input |
| VDrive | LED 12V Rail |
| VCC | 5V Rail |
| VDD | 3.3V Rail |
| VDDA | 3.3V Rail |
| GND | Ground |

## Signals
| Name | Description |
|---|---|
| XLR REF | Reference Voltage for XLR Input |
| HP REF | Reference Voltage for HP Input |
| MIDI | MIDI TX / RX Communications |
| I2C | I2C Bus Communications |

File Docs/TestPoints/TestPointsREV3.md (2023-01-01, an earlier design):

# REV3 Test Points

- TP1 - SDA - I2C Data Line
- TP2 - SCLK - I2C Clock Line
- TP3 - VCC - Switching Power Supply Output
- TP4 - 12V - Switching Power Supply Input
- TP5 - 3V3 - Mega 3.3V Rail
- TP6 - HOME-SW - Home Switch
- TP7 - M-DOWN-SW - Menu Down Switch
- TP8 - M-UP-SW - Menu Up Switch
- TP9 - ACT-SW - Activate Switch
- TP10 - MODE-SW - Mode Switch
- TP11 - LED1-G - LED Ch 1 Green PWM
- TP12 - LED1-R - LED Ch 1 Red PWM
- TP13 - LED1-B - LED Ch 1 Blue PWM
- TP14 - LED2-G - LED Ch 2 Green PWM
- TP15 - LED2-R - LED Ch 2 Red PWM
- TP16 - LED2-B - LED Ch 2 Blue PWM
- TP17 - LED3-G - LED Ch 3 Green PWM
- TP18 - LED3-R - LED Ch 3 Red PWM
- TP19 - LED3-B - LED Ch 3 Blue PWM
- TP20 - LED4-G - LED Ch 4 Green PWM
- TP21 - LED4-R - LED Ch 4 Red PWM
- TP22 - LED4-B - LED Ch 4 Blue PWM
- TP23 - LED5-G - LED Ch 5 Green PWM
- TP24 - LED5-R - LED Ch 5 Red PWM
- TP25 - LED5-B - LED Ch 5 Blue PWM
- TP26 - LED6-G - LED Ch 6 Green PWM
- TP27 - LED6-R - LED Ch 6 Red PWM
- TP28 - LED6-B - LED Ch 6 Blue PWM
- TP29 - LED7-G - LED Ch 7 Green PWM
- TP30 - LED7-R - LED Ch 7 Red PWM
- TP31 - LED7-B - LED Ch 7 Blue PWM
- TP32 - LED8-G - LED Ch 8 Green PWM
- TP33 - LED8-R - LED Ch 8 Red PWM
- TP34 - LED8-B - LED Ch 8 Blue PWM
- TP35 - LED1-G-SIG - LED Ch 1 Green Signal
- TP36 - LED1-R-SIG - LED Ch 1 Red Signal
- TP37 - LED1-B-SIG - LED Ch 1 Blue Signal
- TP38 - LED2-G-SIG - LED Ch 2 Green Signal
- TP39 - LED2-R-SIG - LED Ch 2 Red Signal
- TP40 - LED2-B-SIG - LED Ch 2 Blue Signal
- TP41 - LED3-G-SIG - LED Ch 3 Green Signal
- TP42 - LED3-R-SIG - LED Ch 3 Red Signal
- TP43 - LED3-B-SIG - LED Ch 3 Blue Signal
- TP44 - LED4-G-SIG - LED Ch 4 Green Signal
- TP45 - LED4-R-SIG - LED Ch 4 Red Signal
- TP46 - LED4-B-SIG - LED Ch 4 Blue Signal
- TP47 - LED5-G-SIG - LED Ch 5 Green Signal
- TP48 - LED5-R-SIG - LED Ch 5 Red Signal
- TP49 - LED5-B-SIG - LED Ch 5 Blue Signal
- TP50 - LED6-G-SIG - LED Ch 6 Green Signal
- TP51 - LED6-R-SIG - LED Ch 6 Red Signal
- TP52 - LED6-B-SIG - LED Ch 6 Blue Signal
- TP53 - LED7-G-SIG - LED Ch 7 Green Signal
- TP54 - LED7-R-SIG - LED Ch 7 Red Signal
- TP55 - LED7-B-SIG - LED Ch 7 Blue Signal
- TP56 - LED8-G-SIG - LED Ch 8 Green Signal
- TP57 - LED8-R-SIG - LED Ch 8 Red Signal
- TP58 - LED8-B-SIG - LED Ch 8 Blue Signal
- TP59 - LED1-CURR-NEG - LED Ch 1 CS Resistor Output
- TP60 - LED2-CURR-NEG - LED Ch 2 CS Resistor Output
- TP61 - LED3-CURR-NEG - LED Ch 3 CS Resistor Output
- TP62 - LED4-CURR-NEG - LED Ch 4 CS Resistor Output
- TP63 - LED5-CURR-NEG - LED Ch 5 CS Resistor Output
- TP64 - LED6-CURR-NEG - LED Ch 6 CS Resistor Output
- TP65 - LED7-CURR-NEG - LED Ch 7 CS Resistor Output
- TP66 - LED8-CURR-NEG - LED Ch 8 CS Resistor Output
- TP67 - LED1-CURR_OUT - LED Ch 1 Current
- TP68 - LED2-CURR_OUT - LED Ch 2 Current
- TP69 - LED3-CURR_OUT - LED Ch 3 Current
- TP70 - LED4-CURR_OUT - LED Ch 4 Current
- TP71 - LED5-CURR_OUT - LED Ch 5 Current
- TP72 - LED6-CURR_OUT - LED Ch 6 Current
- TP73 - LED7-CURR_OUT - LED Ch 7 Current
- TP74 - LED8-CURR_OUT - LED Ch 8 Current
- TP75 - N$9 - MIDI Pre-OptoIsolator
- TP76 - MIDI - MIDI Input
- TP77 - XLR-IN - XLR Demodulated Input
- TP78 - N$10 - XLR Negative Input
- TP79 - N$14 - XLR Positive Input
- TP80 - GND - XLR Ground
- TP81 - RAW-L - Raw Audio Left Input
- TP82 - RAW-R - Raw Audio Right Input
- TP83 - HP-SW - Headphone Jack Switch
- TP84 - N$22 - Raw Audio Pan Summer
- TP85 - RAW-FILTER - Raw Audio Filter Output
- TP86 - RAW-OUT - Raw Audio PreAmp Output
- TP87 - N$54 - Raw Audio PreAmp Input
- TP88 - LED-OE - STP16 Output Enable Line
- TP89 - LED-LE - STP16 Latch Enable Line
- TP90 - LED-CLK - STP16 Clock Line
- TP91 - LED-SDI - STP16 Data Line
- TP92 - N$50 - STP16 Current Limit Resistors
- TP93 - LCD-RS - LCD Screen Register Select
- TP94 - LCD-RW - LCD Screen Read/Write
- TP95 - LCD-EN - LCD Screen Enable
- TP96 - LCD-D0 - LCD Parallel Data 0
- TP97 - LCD-D1 - LCD Parallel Data 1
- TP98 - LCD-D2 - LCD Parallel Data 2
- TP99 - LCD-D3 - LCD Parallel Data 3
- TP100 - LCD-D4 - LCD Parallel Data 4
- TP101 - LCD-D5 - LCD Parallel Data 5
- TP102 - LCD-D6 - LCD Parallel Data 6
- TP103 - LCD-D7 - LCD Parallel Data 7
- TP104 - LCD-CONT - LCD Contrast POT
- TP105 - BK-K - LCD Backlight POT
- TP106 - ARD-VCC - BackPower Mega Side
- TP107 - VCC - BackPower VCC Side
- TP108 - N$56 - BackPower MOSFET Gate
- TP109 - VDD - LED Strings Post-Relay Power Rail
- TP110 - MAIN-RELAY - Relay MOSFET Control Signal
- TP111 - N$19 - Relay Coil
- TP112 - ENC1-B - Rotary Encoder 1 B Signal
- TP113 - ENC1-B - Rotary Encoder 1 A Signal
- TP114 - ENC1-SW - Rotary Encoder 1 Switch
- TP115 - ENC2-B - Rotary Encoder 2 B Signal
- TP116 - ENC2-B - Rotary Encoder 2 A Signal
- TP117 - ENC2-SW - Rotary Encoder 2 Switch
- TP118 - GND - Encoder Ground
- TP119 - RESET - Reset Line
- TP120 - MIDI-GND - MIDI Ground plane

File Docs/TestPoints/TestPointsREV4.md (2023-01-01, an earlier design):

# REV4 Test Points

## Power Rails
|# | Name | Description |
|---|---|---|
| 1 | VDD | LED 12V Rail |
| 2 | 12V | Main 12V Input |
| 3 | VCC | 5V Rail |
| 4 | -V | -5V Rail |
| 5 | GND | System Ground |

## Power Control
|# | Name | Description |
|---|---|---|
| 107 | PWR2_SW | Power Jack 2 Switch |
| 108 | PWR1_SW | Power Jack 1 Switch |
| 109 | MAIN_PWR | LED Power Enable Signal |
| 110 | MAIN_RLY | LED Power Relay Enable |

## -5V Inverter
|# | Name | Description |
|---|---|---|
| 6 | -5V_PRE | -5V Pre-Filter Output |
| 7 | -5V_SW | -5V Switch Output |
| 8 | -5V_SN | -5V Sense Input |
| 111 | INV_EN | -5V Enable Signal |

## I2C Bus
|# | Name | Description |
|---|---|---|
| 9 | SDA | I2C Data Line |
| 10 | SCLK | I2C Clock Line |

## Rotary Encoders
|# | Name | Description |
|---|---|---|
| 11 | ENC1_B | Encoder 1 Data B |
| 12 | ENC1_A | Encoder 1 Data A |
| 13 | ENC1_SW | Encoder 1 Switch |
| 14 | ENC2_B | Encoder 2 Data B |
| 15 | ENC2_A | Encoder 2 Data A |
| 16 | ENC2_SW | Encoder 2 Switch |

## Switches
|# | Name | Description |
|---|---|---|
| 17 | MODE_SW | Mode Switch |
| 18 | ACT_SW | Act Switch |
| 19 | M_UP_SW | Menu Up Switch |
| 20 | M_DN_SW | Menu Down Switch |
| 21 | M_HM_SW | Menu Home Switch |
| 22 | RESET | System Reset Bus |

## LED Current Monitors
|# | Name | Description |
|---|---|---|
| 24 | LED1_CURR | LED 1 Current Output |
| 25 | LED3_CURR | LED 3 Current Output |
| 26 | LED5_CURR | LED 5 Current Output |
| 27 | LED2_CURR | LED 2 Current Output |
| 28 | LED8_CURR | LED 8 Current Output |
| 29 | LED6_CURR | LED 6 Current Output |
| 30 | LED7_CURR | LED 7 Current Output |
| 31 | LED4_CURR | LED 4 Current Output |

## LED RGB Channels
|# | Name | Description |
|---|---|---|
| 23 | PWM_OE | PWM Output Enable Line (Active LOW) |
| 48 | LED1_G | LED Channel 1 Green |
| 49 | LED1_R | LED Channel 1 Red |
| 50 | LED1_B | LED Channel 1 Blue |
| 51 | LED2_G | LED Channel 2 Green |
| 52 | LED2_R | LED Channel 2 Red |
| 53 | LED2_B | LED Channel 2 Blue |
| 54 | LED3_G | LED Channel 3 Green |
| 55 | LED3_R | LED Channel 3 Red |
| 56 | LED3_B | LED Channel 3 Blue |
| 57 | LED4_G | LED Channel 4 Green |
| 58 | LED4_R | LED Channel 4 Red |
| 59 | LED4_B | LED Channel 4 Blue |
| 60 | LED5_G | LED Channel 5 Green |
| 61 | LED5_R | LED Channel 5 Red |
| 62 | LED5_B | LED Channel 5 Blue |
| 63 | LED6_G | LED Channel 6 Green |
| 64 | LED6_R | LED Channel 6 Red |
| 65 | LED6_B | LED Channel 6 Blue |
| 66 | LED7_G | LED Channel 7 Green |
| 67 | LED7_R | LED Channel 7 Red |
| 68 | LED7_B | LED Channel 7 Blue |
| 69 | LED8_G | LED Channel 8 Green |
| 70 | LED8_R | LED Channel 8 Red |
| 71 | LED8_B | LED Channel 8 Blue |

## Audio
|# | Name | Description |
|---|---|---|
| 80 | AUDIO_HP | Audio Headphones Input |
| 81 | HP_SW | Headphones Switch |
| 82 | MIDI_PRE | MIDI Pre-Input |
| 83 | MIDI | MIDI Input |
| 84 | +XLR | XLR Input High |
| 85 | -XLR | XLR Input Low |
| 86 | XLR | XLR Input |
| 87 | AUDIO_SEL | Audio Relay Select Line |
| 88 | AUDIO_PRE | Audio Raw |
| 89 | AUDIO_AMP | Audio Amplified |

## LED Indicators
|# | Name | Description |
|---|---|---|
| 90 | LED_SDI | LED Driver Data |
| 91 | LED_CLK | LED Driver Clock |
| 92 | LED_LE | LED Driver Latch |
| 93 | LED_OE | LED Driver Output Enable |

## LCD Screen
|# | Name | Description |
|---|---|---|
| 94 | LCD_RS | Screen Register Select |
| 95 | LCD_RW | Screen Read/Write |
| 96 | LCD_EN | Screen Enable |
| 97 | LCD_D0 | Screen Data 0 |
| 98 | LCD_D1 | Screen Data 1 |
| 99 | LCD_D2 | Screen Data 2 |
| 100 | LCD_D3 | Screen Data 3 |
| 101 | LCD_D4 | Screen Data 4 |
| 102 | LCD_D5 | Screen Data 5 |
| 103 | LCD_D6 | Screen Data 6 |
| 104 | LCD_D7 | Screen Data 7 |
| 105 | LCD_CONT | Screen Contrast |
| 106 | LCD_BRGT | Screen Backlight Brightness |

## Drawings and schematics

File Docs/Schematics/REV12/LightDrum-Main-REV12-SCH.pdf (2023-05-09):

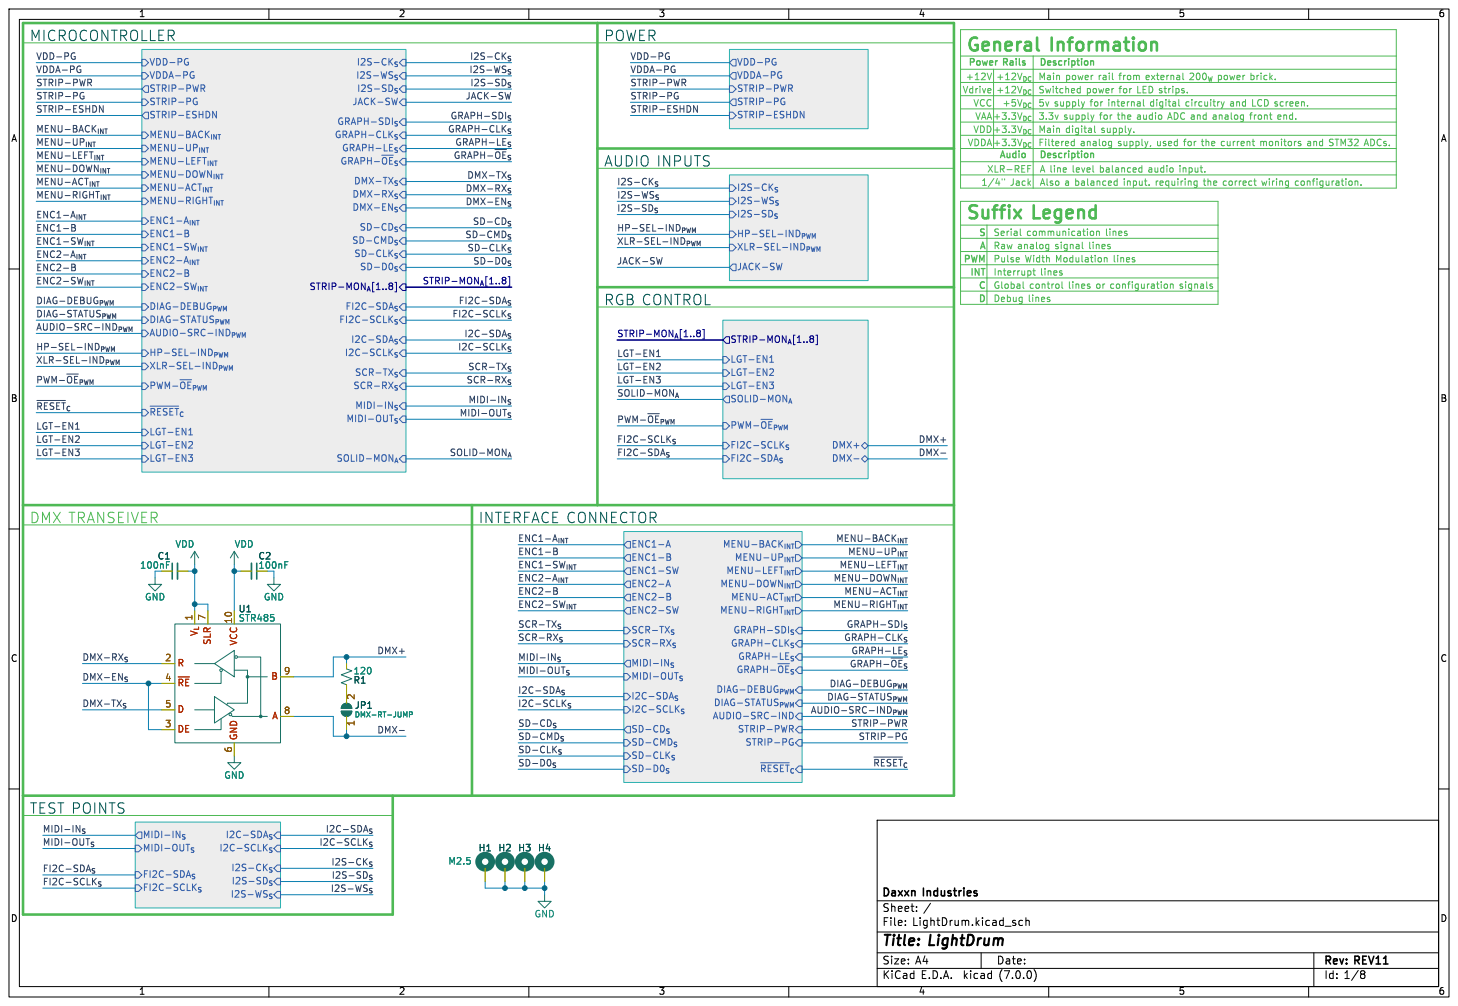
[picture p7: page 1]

LGT-EN1 MICROCONTROLLER
MENU-UP_{INT} VDD-PG MIDI-OUT_{S}
VDDA-PG
LGT-EN2 STRIP-PWR
STRIP-ESHDN

+3.3V_{DC} Vdrive VDDA DMX TRANSEIVER
STRIP-PG

VDD-PG
MENU-LEFT_{INT} STRIP-PWR
MENU-BACK_{INT}
MENU-UP_{INT}

+12V +12V_{DC}Main power rail from external 200_{W}power brick. Main digital supply. VAA

VDD+3.3V_{DC} XLR-REF
S Description Also a balanced input. requiring the correct wiring configuration. A line level balanced audio input. C

I2S-WS_{S} JACK-SW AUDIO INPUTS

HP-SEL-IND_{PWM}
XLR-SEL-IND_{PWM} JACK-SW

STRIP-MON_{A}[1..8] DMX- DMX+ RGB CONTROL

LGT-EN1 SOLID-MON_{A} LGT-EN2 PWM-~{OE}_{PWM}

AUDIO-SRC-IND MENU-UP_{INT}
MENU-LEFT_{INT}
MENU-DOWN_{INT}
MENU-ACT_{INT}
MENU-RIGHT_{INT}
GRAPH-SDI_{S}
GRAPH-CLK_{S}
GRAPH-LE_{S}
GRAPH-~{OE}_{S}
DIAG-DEBUG_{PWM}
DIAG-STATUS_{PWM} STRIP-PWR

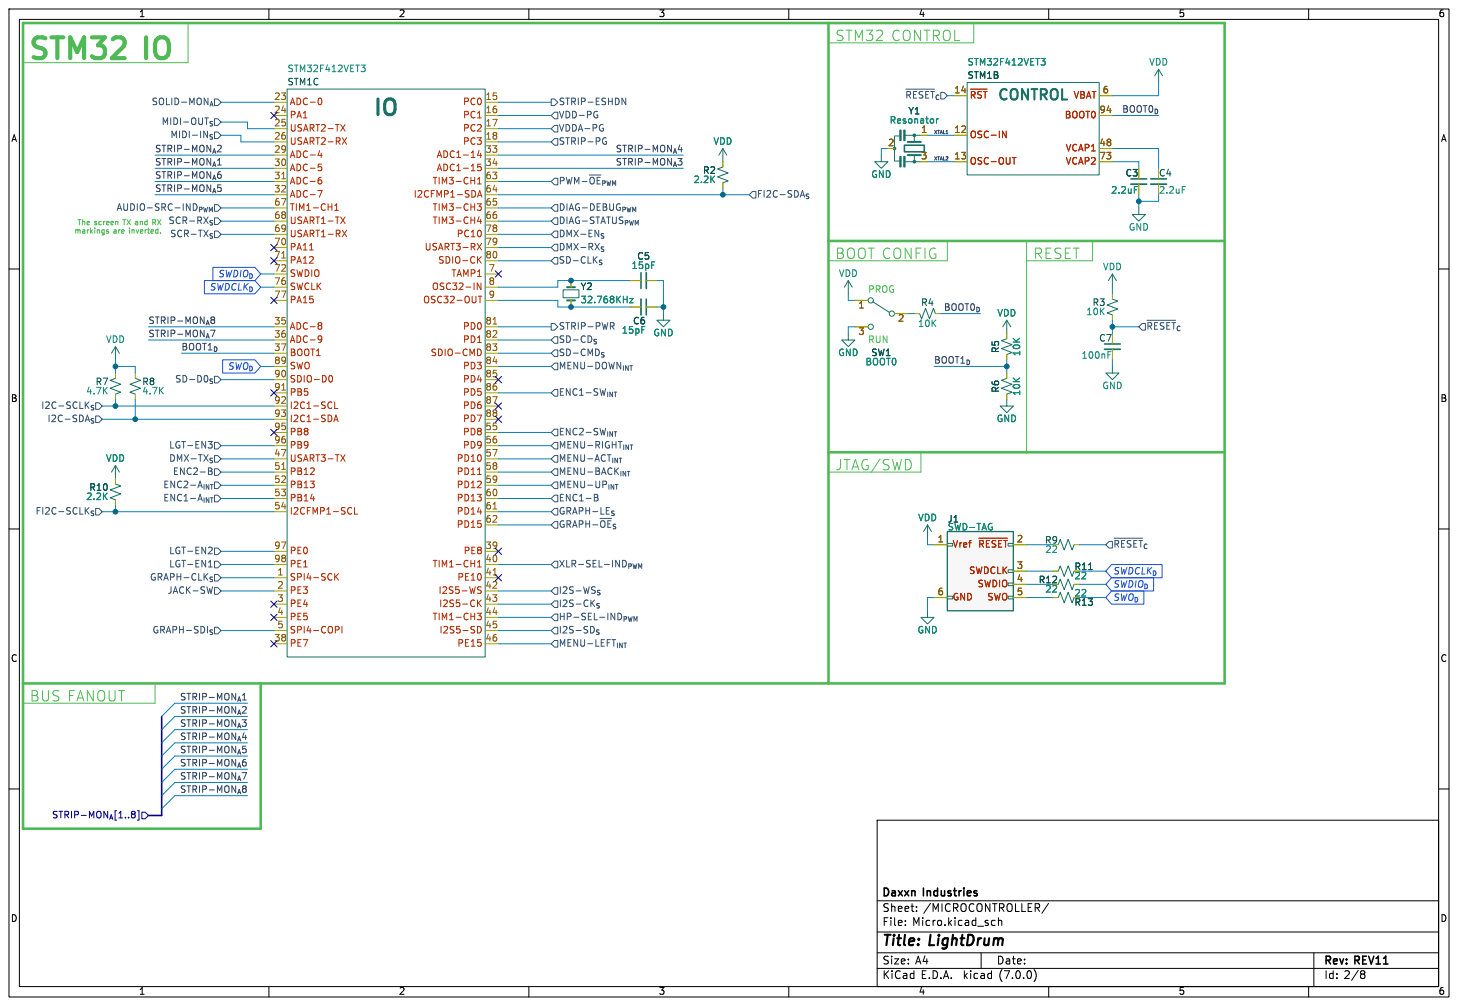
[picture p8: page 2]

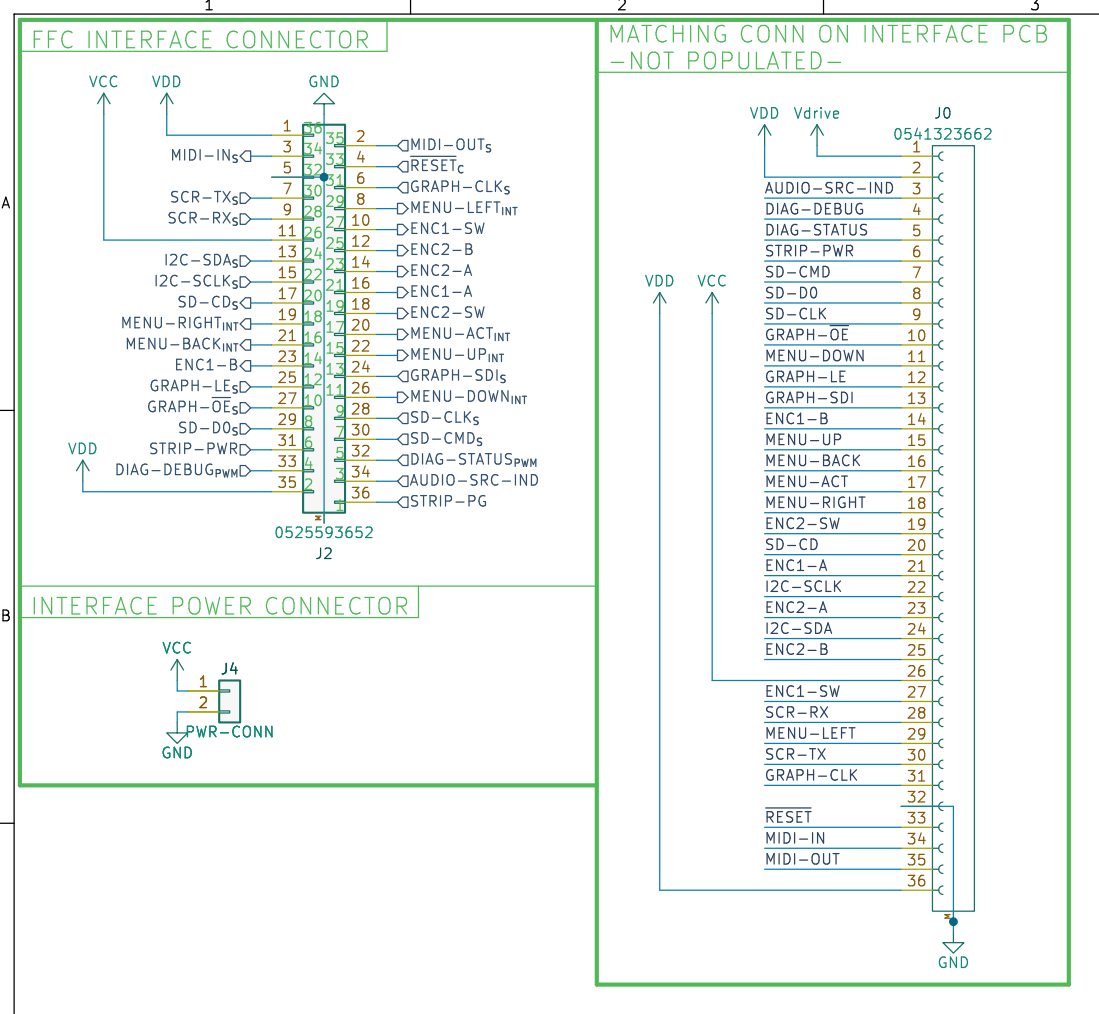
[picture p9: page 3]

DIAG-STATUS DIAG-DEBUG MENU-DOWN MENU-ACT MENU-RIGHT MENU-BACK
SD-D0 MIDI-OUT MIDI-IN
SCR-RX MENU-LEFT GRAPH-SDI GRAPH-~{OE} SD-CLK

MENU-DOWN_{INT} AUDIO-SRC-IND
SD-CLK_{S}
SD-CMD_{S} STRIP-PG
DIAG-STATUS_{PWM}

ENC1-B MENU-UP GRAPH-LE

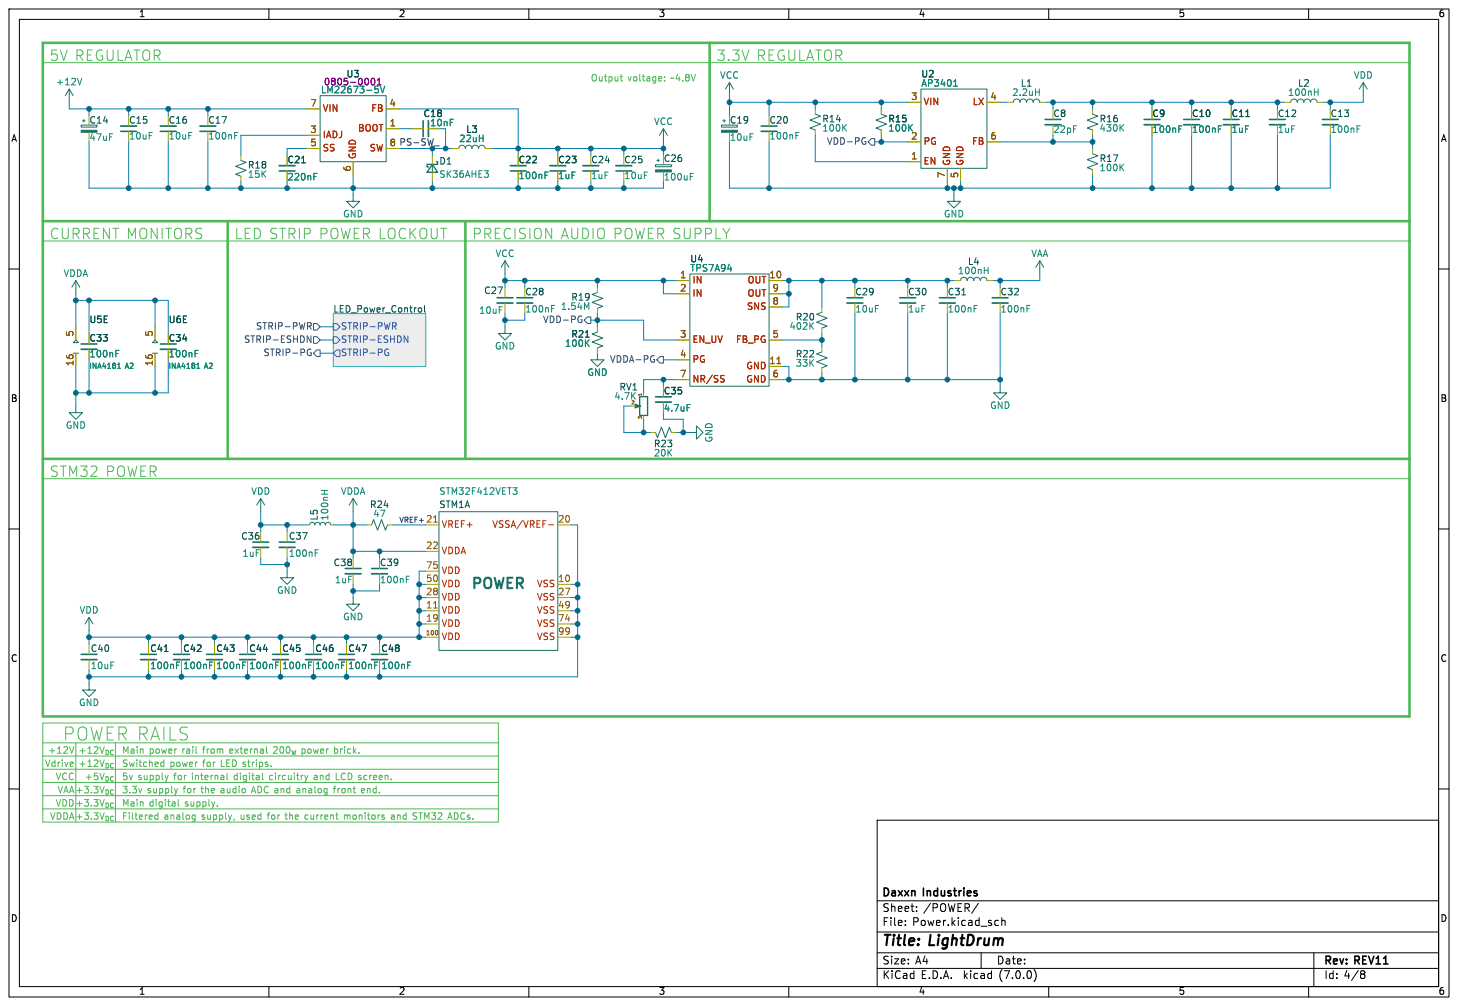
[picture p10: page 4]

LED STRIP POWER LOCKOUT

PRECISION AUDIO POWER SUPPLY

Main power rail from external 200_{W}power brick. Switched power for LED strips. Main digital supply.

3.3v supply for the audio ADC and analog front end.

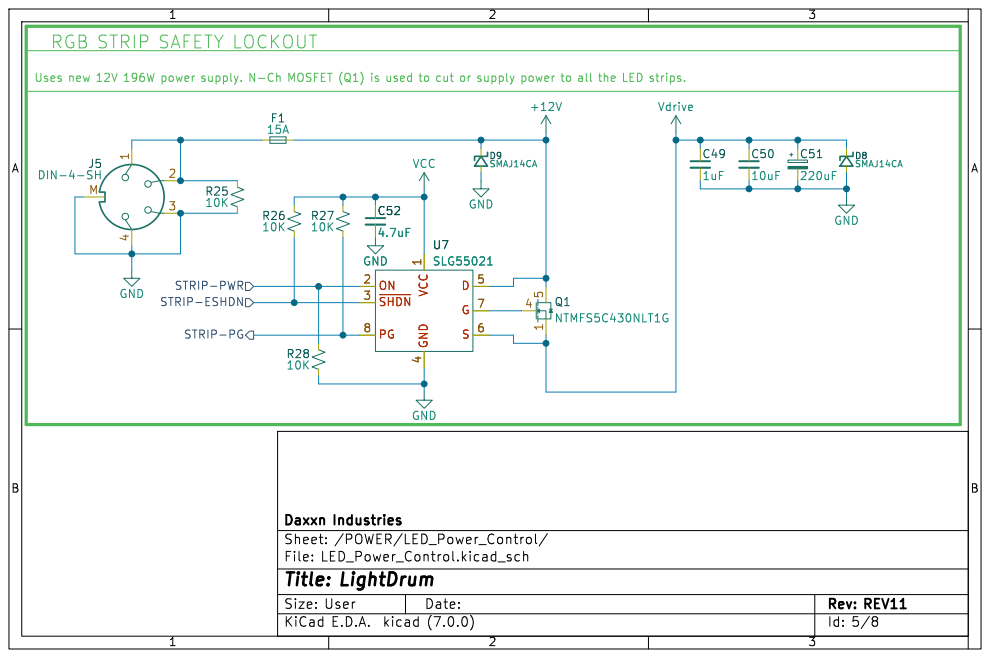
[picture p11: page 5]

STRIP-PG RGB STRIP SAFETY LOCKOUT

Uses new 12V 196W power supply. N-Ch MOSFET (Q1) is used to cut or supply power to all the LED strips. C52

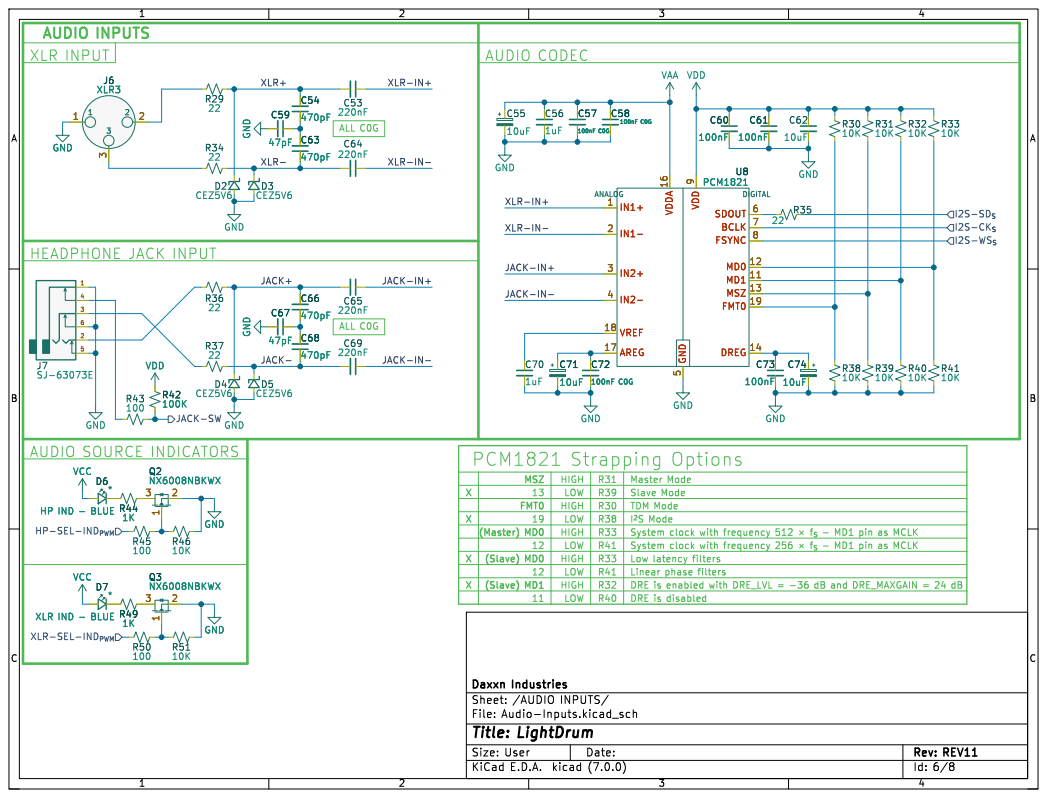
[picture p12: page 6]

System clock with frequency 512 þÿ×f_{S}- MD1 pin as MCLK R40 R32 AUDIO INPUTS
XLR INPUT
47pF GND

5 SDOUT 6 BCLK 7 FSYNC 8 VDD

Low latency filters System clock with frequency 256 þÿ×f_{S}- MD1 pin as MCLK

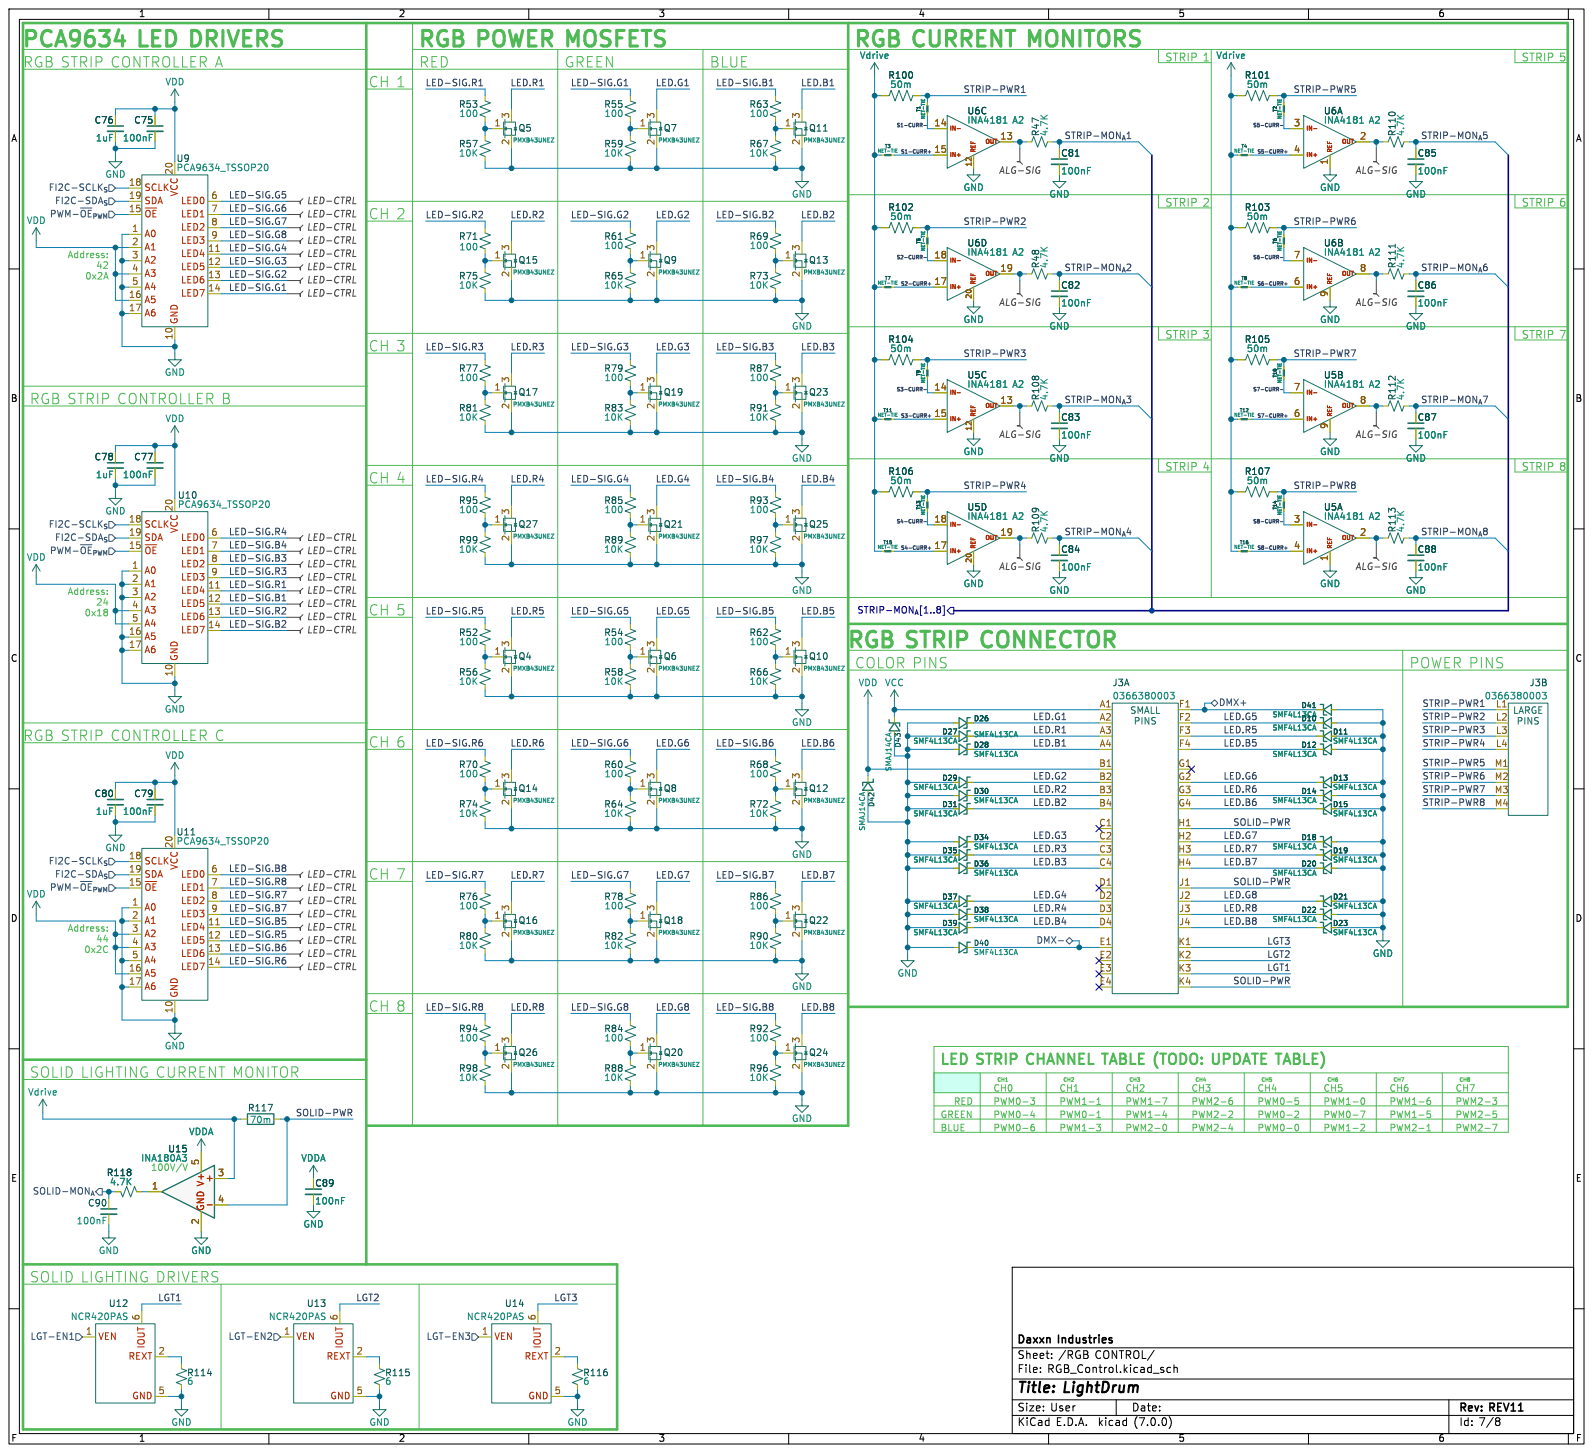
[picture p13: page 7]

STRIP 4 RGB POWER MOSFETS
RED

STRIP 7 RGB CURRENT MONITORS
Vdrive R102
50m T1 NET-TIE T5 NET-TIE R100

OUT 8 REF 9 GND T10 NET-TIE T6 NET-TIE R103

100nF GND
OUT 8 REF 9 GND GND GND

S7-CURR+ S8-CURR- S7-CURR- STRIP-MON_{A}4

Address: 24
LED-SIG.R6 SOLID-PWR

SOLID LIGHTING CURRENT MONITOR

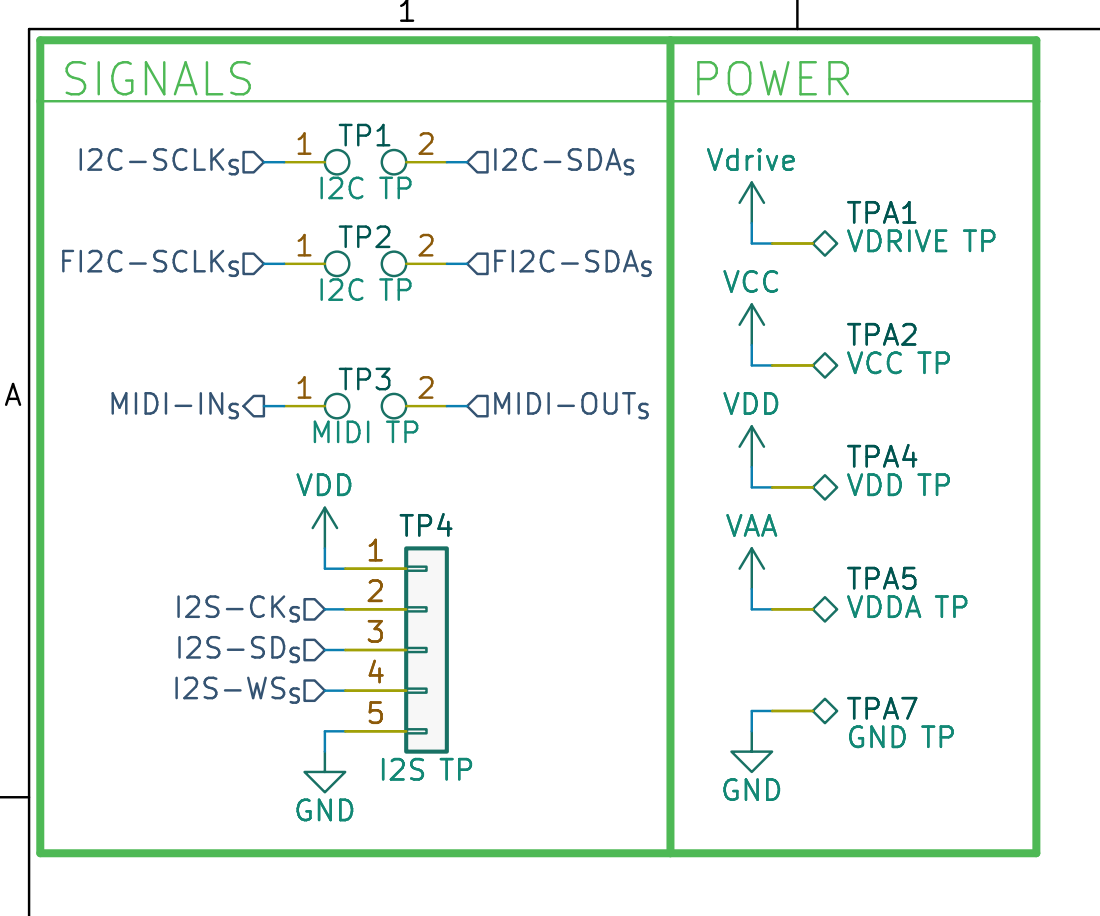
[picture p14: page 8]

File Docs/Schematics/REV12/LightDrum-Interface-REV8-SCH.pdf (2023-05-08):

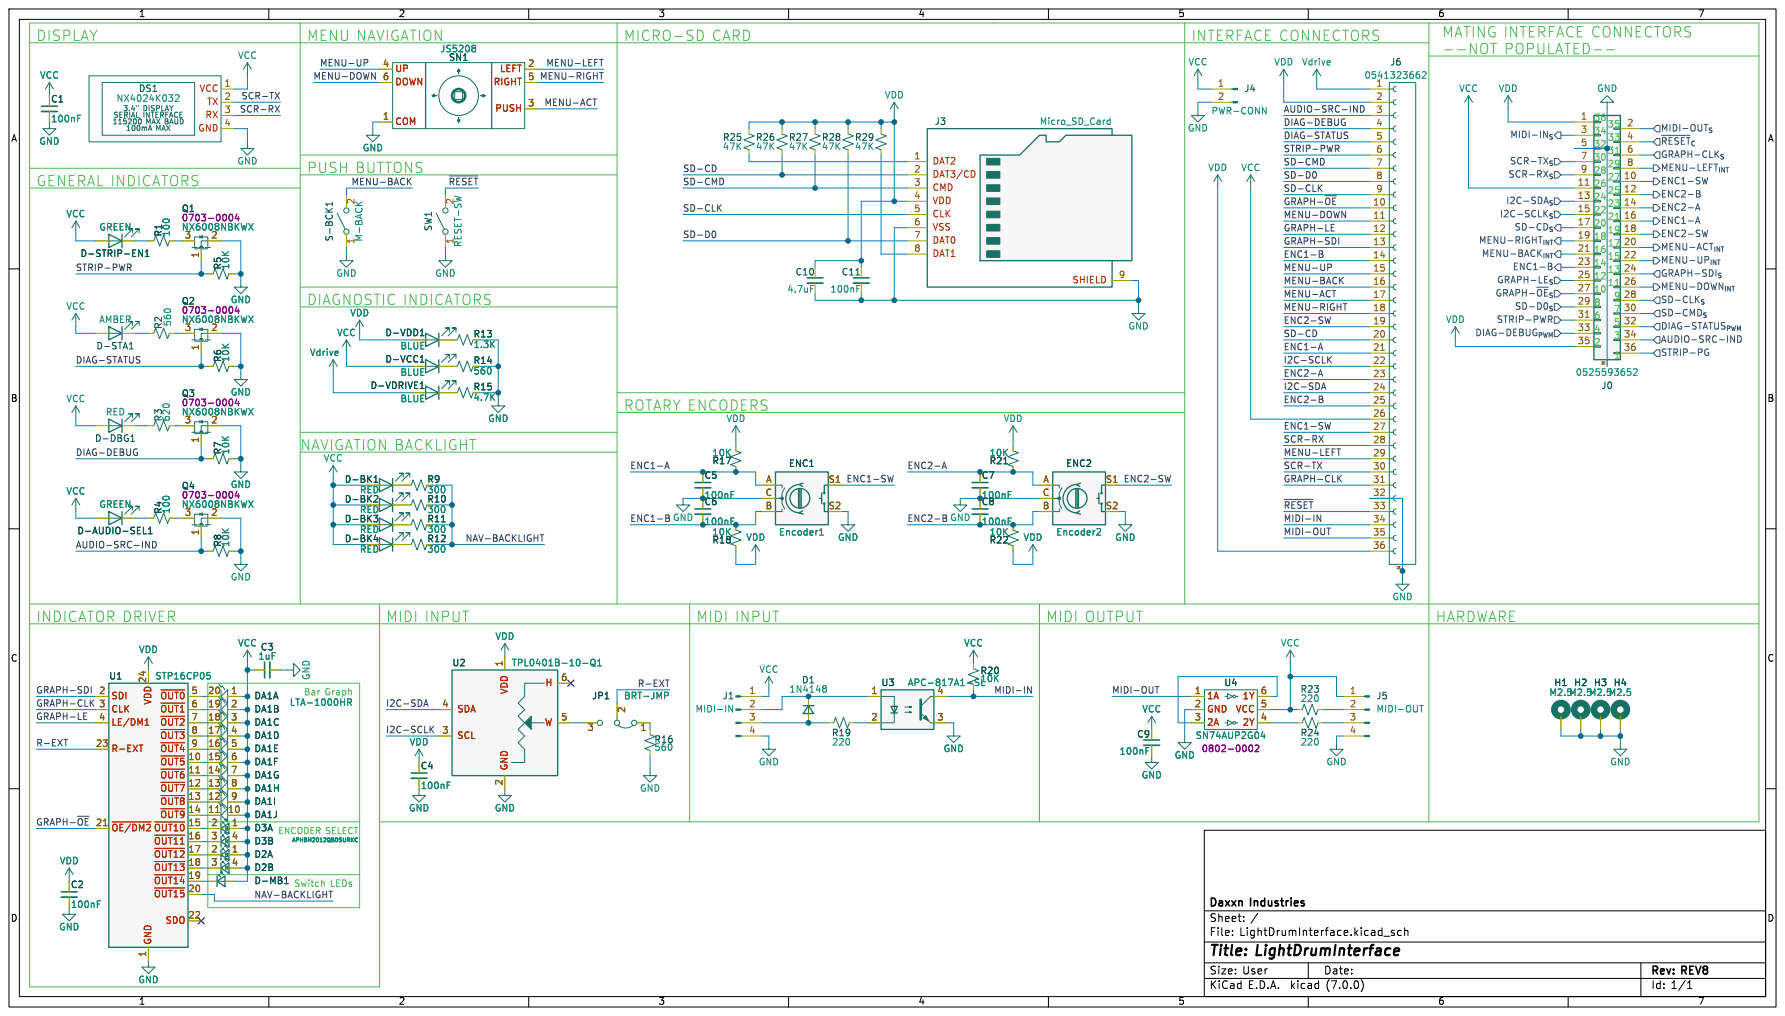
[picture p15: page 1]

~{RESET} MENU-LEFT STRIP-PWR

I2C-SCLK MENU-ACT MENU-RIGHT MIDI-IN

1 ~{OUT5} 10 ~{OUT6} 11 ~{OUT7} 12 ~{OUT8} 13 ~{OUT9} 14 ~{OUT10}15 ~{OUT11}16 ~{OUT12}17 ~{OUT13}18 ~{OUT14}19 SDI 2 ~{OUT15}20 ~{OE/DM2} 21 SDO 22 R-EXT 23 VDD 24 CLK 3

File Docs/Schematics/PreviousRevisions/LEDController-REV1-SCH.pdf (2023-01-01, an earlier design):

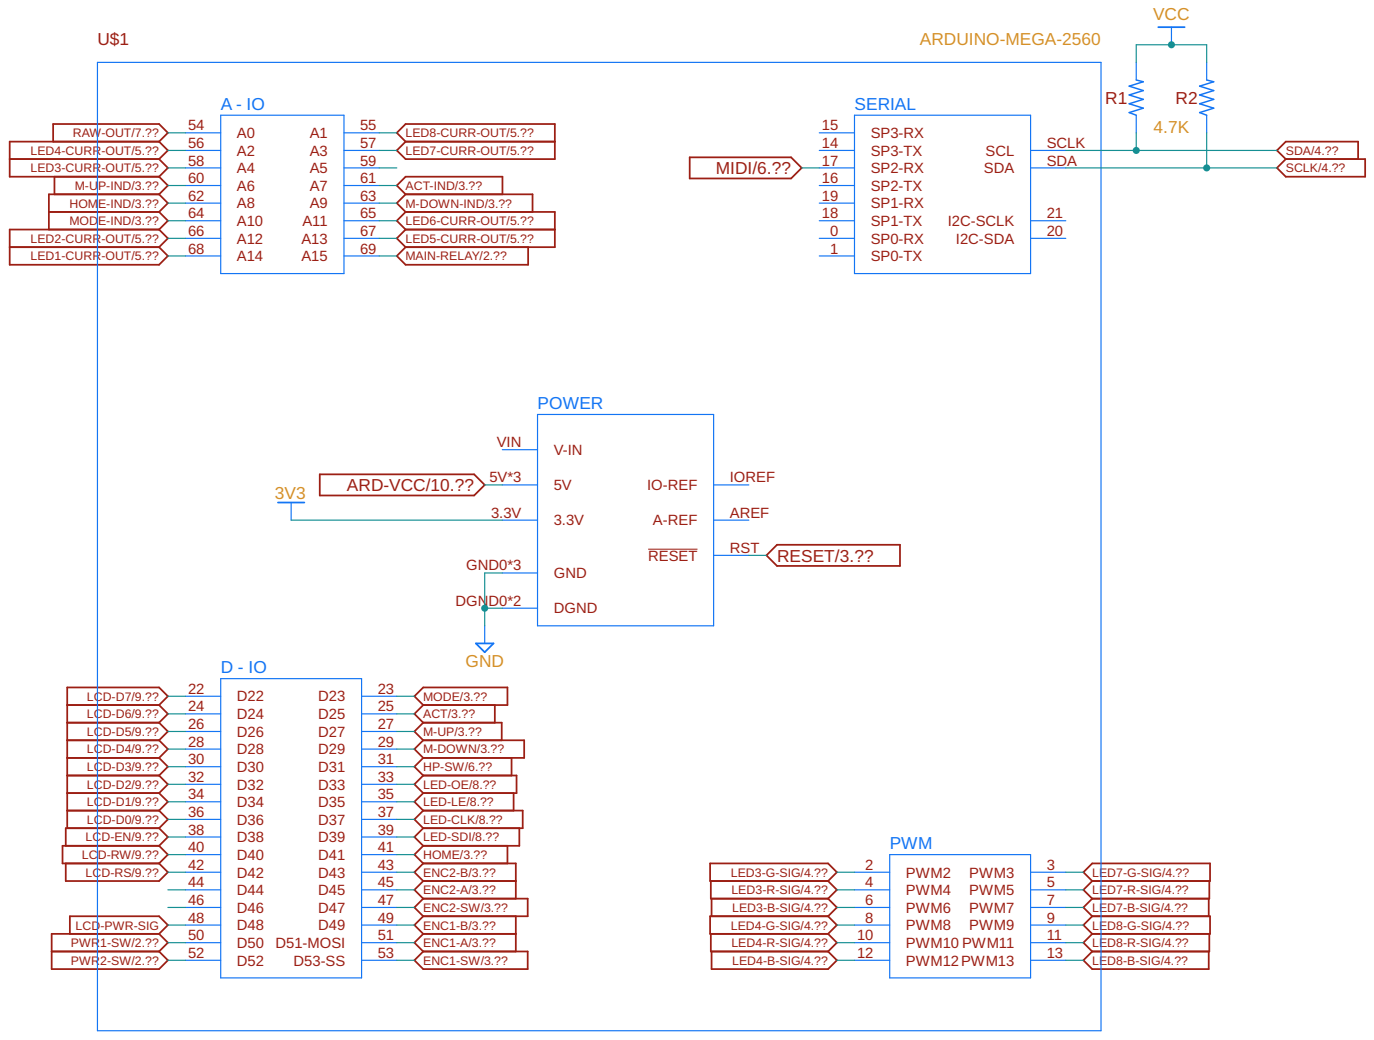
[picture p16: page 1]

LED8-CURR-OUT/5.??
LED7-CURR-OUT/5.?? ACT-IND/3.??

LED4-CURR-OUT/5.??
LED3-CURR-OUT/5.?? M-UP-IND/3.?? HOME-IND/3.??

HP-SW/6.?? M-DOWN/3.?? M-UP/3.?? ACT/3.?? MODE/3.??

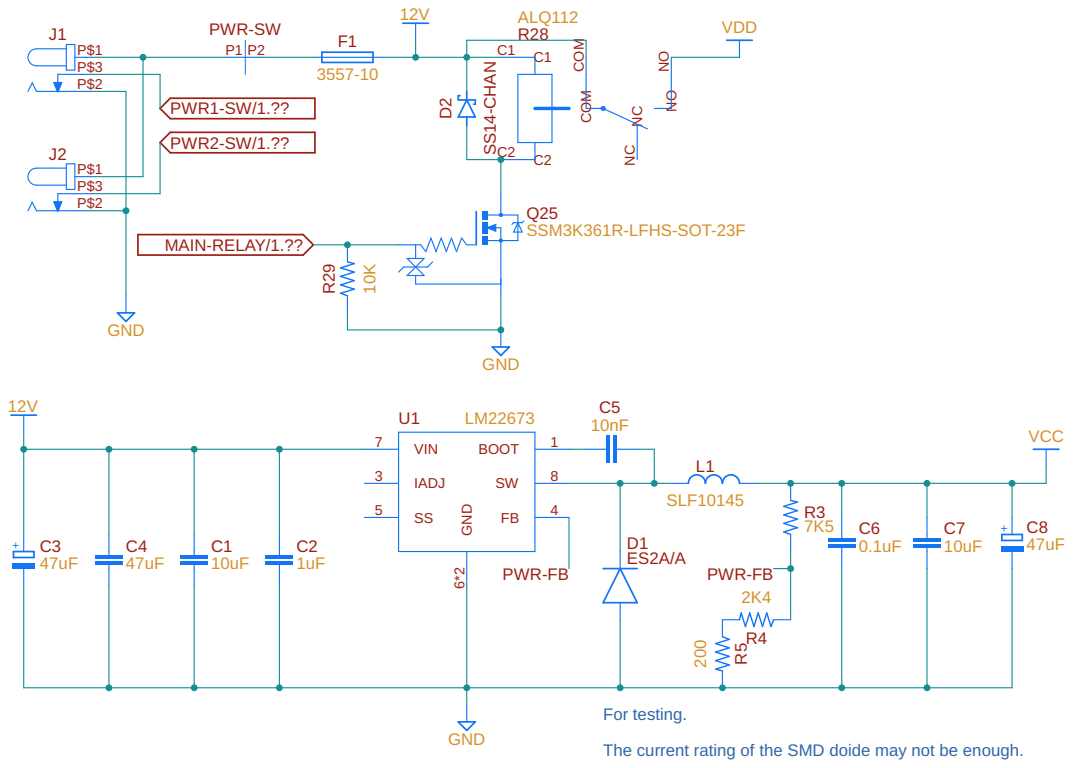
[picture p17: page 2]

For testing. The current rating of the SMD doide may not be enough.

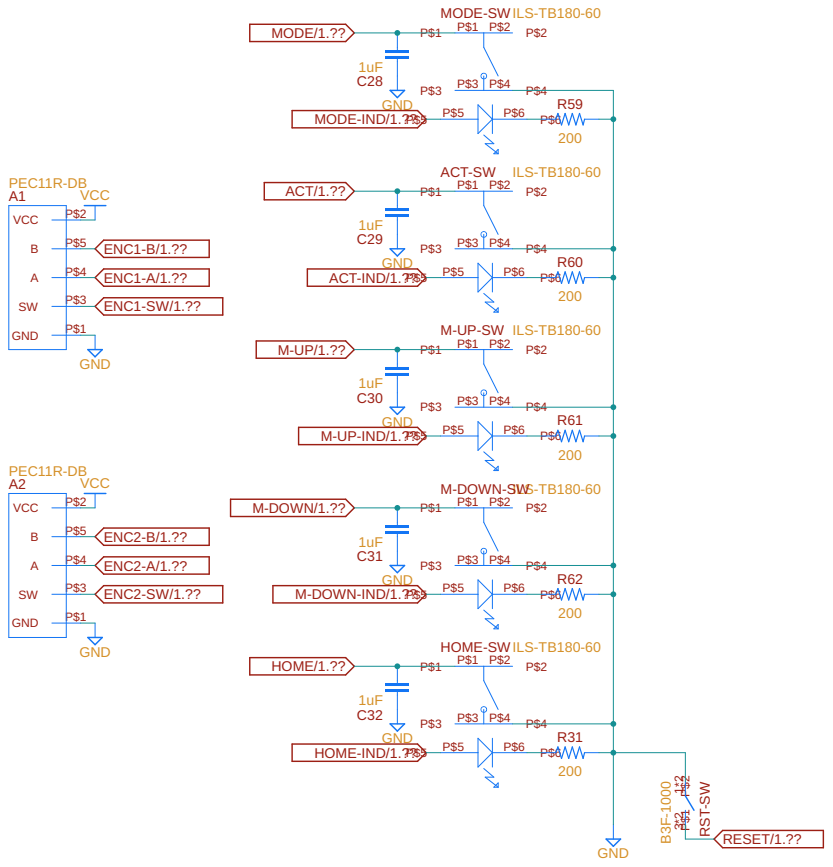
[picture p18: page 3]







NEED TO FIX OPAMP FOOTPRINT





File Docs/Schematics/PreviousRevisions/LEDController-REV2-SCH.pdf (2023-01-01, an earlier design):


LED8-CURR-OUT/5.??
LED7-CURR-OUT/5.?? ACT-IND/3.??
PWM-OE/4.??

LED4-CURR-OUT/5.??
LED3-CURR-OUT/5.?? M-UP-IND/3.?? HOME-IND/3.??

HP-SW/6.?? M-DOWN/3.?? M-UP/3.?? ACT/3.?? MODE/3.??


For testing. The current rating of the SMD doide may not be enough.










MMBT2222A-TPSMOTM-B23T-2H2S22A-TPSMOTM-B23T-2H2S22A-TPMSMOBTT-2232-2H2SA-TPMSMOBTT-2232-2H2SA-TPMSMOBTT-2232-2H2SA-TPSOT-23-HS



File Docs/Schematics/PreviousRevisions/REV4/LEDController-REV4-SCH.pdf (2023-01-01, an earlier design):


M-DOWN-IND/3.??
M-UP/3.?? M-UP-IND/3.?? HOME-IND/3.?? M-DOWN/3.?? MODE-IND/3.??
MODE/3.??

LED-CLK/8.??
LED-SDI/8.?? HP-XLR-SW/6.??

LED-OE/8.??
LED-LE/8.??
LED7-CURR-OUT/5.?? ACT-IND/3.??


PWR1-SW/10.?? PWR2-SW/10.?? MAIN-RELAY/10.??




LED5-CURR-OUT/1.?? | 8 LED2-CURR-OUT/1.??

4 | 11
5 | 10 GND

LED7-CURR-OUT/1.?? | 8 LED4-CURR-OUT/1.??







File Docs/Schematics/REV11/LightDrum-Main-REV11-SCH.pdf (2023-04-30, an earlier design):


VDD-PG MENU-ACT_{INT}
STRIP-MON_{A}[1..8] STRIP-PG
STRIP-ESHDN

VDDA-PG
MENU-RIGHT_{INT} STRIP-PWR
STRIP-PG MENU-BACK_{INT}

VDD-PG
MENU-LEFT_{INT} STRIP-PWR
STRIP-PG

3.3v supply for the audio ADC and analog front end. A line level balanced audio input.
Main digital supply.

PWM-~{OE}_{PWM}
~{RESET}_{C} STRIP-PWR MENU-UP_{INT} STRIP-PG

MENU-BACK_{INT}
AUDIO-SRC-IND MENU-UP_{INT}
MENU-LEFT_{INT}
MENU-DOWN_{INT}
MENU-ACT_{INT}
MENU-RIGHT_{INT}
GRAPH-SDI_{S}
GRAPH-CLK_{S}
GRAPH-LE_{S}
GRAPH-~{OE}_{S}
DIAG-DEBUG_{PWM}
DIAG-STATUS_{PWM} STRIP-PWR

1 2 JP1 DMX-RT-JUMP V_{L}1 VCC 10 R


~{RESET}_{C} STRIP-PG MIDI-OUT_{S}

SD-CD_{S} STRIP-PWR MENU-DOWN_{INT}


-NOT POPULATED- 2
AUDIO-SRC-IND GRAPH-CLK_{S} ENC2-A MENU-LEFT_{INT}

I2C-SDA MIDI-OUT AUDIO-SRC-IND
~{RESET} MIDI-IN
ENC1-A GRAPH-CLK
MENU-LEFT SD-CD MENU-DOWN
SCR-RX
ENC1-SW


Output voltage: ~4.8V PRECISION AUDIO POWER SUPPLY

LX 4 GND
VREF+ PS-SW_ Switched power for LED strips.

LED STRIP POWER LOCKOUT

Main power rail from external 200_{W}power brick. POWER RAILS
+3.3V_{DC}Main digital supply. +12V


RGB STRIP POWER LOCKOUT

Uses new 12V 196W power supply. N-Ch MOSFET (Q1) is used to cut or supply power to all the LED strips.


5 SDOUT 6 BCLK 7 FSYNC 8 VDD

Low latency filters Linear phase filters TDM Mode
I^{2}SMode
System clock with frequency 512 þÿ×f_{S}- MD1 pin as MCLK
System clock with frequency 256 þÿ×f_{S}- MD1 pin as MCLK

DRE is disabled DRE is enabled with DRE_LVL = -36 dB and DRE_MAXGAIN = 24 dB


STRIP-PWR[1..8] Strip Current Monitors DMX- DMX+ FI2C-SDA_{S}


LED2-G-SIG RGB STRIP CONTROLLER A




This may not be the



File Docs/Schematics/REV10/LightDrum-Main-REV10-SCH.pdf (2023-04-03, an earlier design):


STRIP-PWR
VDDA-PG
MENU-RIGHT MENU-ACT MENU-BACK MENU-UP GRAPH-LE MENU-LEFT GRAPH-~{OE} XLR-ADC-CS HP-ADC-CS

DMX+ PWM-OE HP-VREF-IRQ
XLR-VREF-IRQ
XLR-ADC-CS
HP-ADC-CS

HP-ADC-IRQ AUDIO INPUTS

3.3V Digital Supply 12V
Switched 12V Supply for the LED strips

3.3V Low Noise Analog Supply

XLR-ADC-IRQ
XLR-ADC-CS HP-ADC-CS

~{PWM-OE} DMX- DMX+ RGB CONTROL

MIDI-IN MIDI-OUT TEST POINTS

MIDI-IN MIDI-OUT ~{RESET}

DIAG-STATUS DIAG-DEBUG

AUDIO-SRC-IND GRAPH-~{OE} GRAPH-SDI GRAPH-CLK MENU-UP MENU-ACT MENU-LEFT MENU-BACK MENU-DOWN MENU-RIGHT SCR-TX

DIAG-STATUS MENU-ACT MENU-UP DMX+

STRIP-PWR GRAPH-LE DIAG-STATUS

1 2 JP101 DMX-RT-JUMP VDD VDD


source. AUDIO ADCS
XLR INPUT
XLR- HP-SW-IN
VDDA R224 1K R221
GND

XLR-ADC-CS HP-ADC-CS

SPI-SCLK
SPI-COPI SPI-CIPO

The HP-SWITCH
sends a signal to the MC, setting the HP




Screwed up the address transfer.




LED3-R
LED4-R ~{OE} RGB Control 3 File: RGB_Control-3.kicad_sch LED7-R


PROG STM32 CONTROL STM32 IO
ENC1-A MENU-LEFT HP-SW
STRIP-PWR GRAPH-LE MENU-BACK MENU-ACT MENU-UP MENU-RIGHT STRIP8-CURR

~{RESET} SWDCLK MIDI-OUT SCR-TX MIDI-IN

STRIP3-CURR
STRIP7-CURR
PWM-OE
DIAG-STATUS DIAG-DEBUG

DMX-TX DMX-EN
DMX-RX

MENU-DOWN
ENC1-B GRAPH-~{OE} XLR-ADC-CS HP-ADC-CS
ENC1-SW

3 SWDCLK/TCK 4 SWO/TDO 6 NC/TDI 8 GNDDetect 9

4 SDA 5 SCL 6 WP 7 VCC


RGB STRIP POWER LOCKOUT

Uses new 12V 196W power supply. Both relays are required for incresing current capacity.


Output voltage: ~4.8V PRECISION ANALOG REGULATOR
1uF GND
VCC GND

DECOUPLING
CURRENT MONITORS STM32 POWER SUPPLY

LED STRIP POWER LOCKOUT


NOT POPULATED
MIDI-OUT GRAPH-CLK MENU-ACT MENU-RIGHT SCR-RX

~{RESET} SCR-RX MENU-ACT

AUDIO-SRC-IND GRAPH-LE

STRIP-PWR MENU-DOWN MENU-LEFT DIAG-DEBUG


XLR-REF HP-REF

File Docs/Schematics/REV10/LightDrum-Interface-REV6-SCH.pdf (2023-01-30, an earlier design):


SCR-TX GRAPH-~{OE} GRAPH-SDI

MATCHING CONN ON MAIN PCB NOT POPULATED MAIN CONNECTOR REFERENCE

JS5208 GND JS5208 COM 1 SN1 | RIGHT LEFT | 2 PUSH 3 UP 4 5 DOWN 6

SN1 | Vdrive

~{RESET} MIDI-OUT MIDI-IN GRAPH-SDI ENC1-A

1 NAVIGATION BACKLIGHT
ENC2-B MIDI-OUT GRAPH-CLK GRAPH-SDI Bar Graph

1 2 SW1 RESET-SW R3620 D-DBG1 RED GND
VCC
ENC2-A GRAPH-LE

I2C-SDA
SCR-TX
SCR-RX MENU-ACT

SCR-RX MENU-LEFT MENU-UP MENU-DOWN

ENC2-SW
SCR-TX MENU-RIGHT
I2C-SCLK

GRAPH-LE MENU-ACT MENU-UP MENU-BACK

DIAG-STATUS DIAG-DEBUG

ENC1-B DIAG-DEBUG MENU-DOWN

INDICATOR DRIVER | | | MIDI INPUT | 100nF D-BK4 RED | MIDI INPUT | MIDI OUTPUT

VCC VCC C3 | VDD | VCC | 100nFVCC

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

File: LightDrumInterface.kicad_sch Sheet: / Daxxn Industries


















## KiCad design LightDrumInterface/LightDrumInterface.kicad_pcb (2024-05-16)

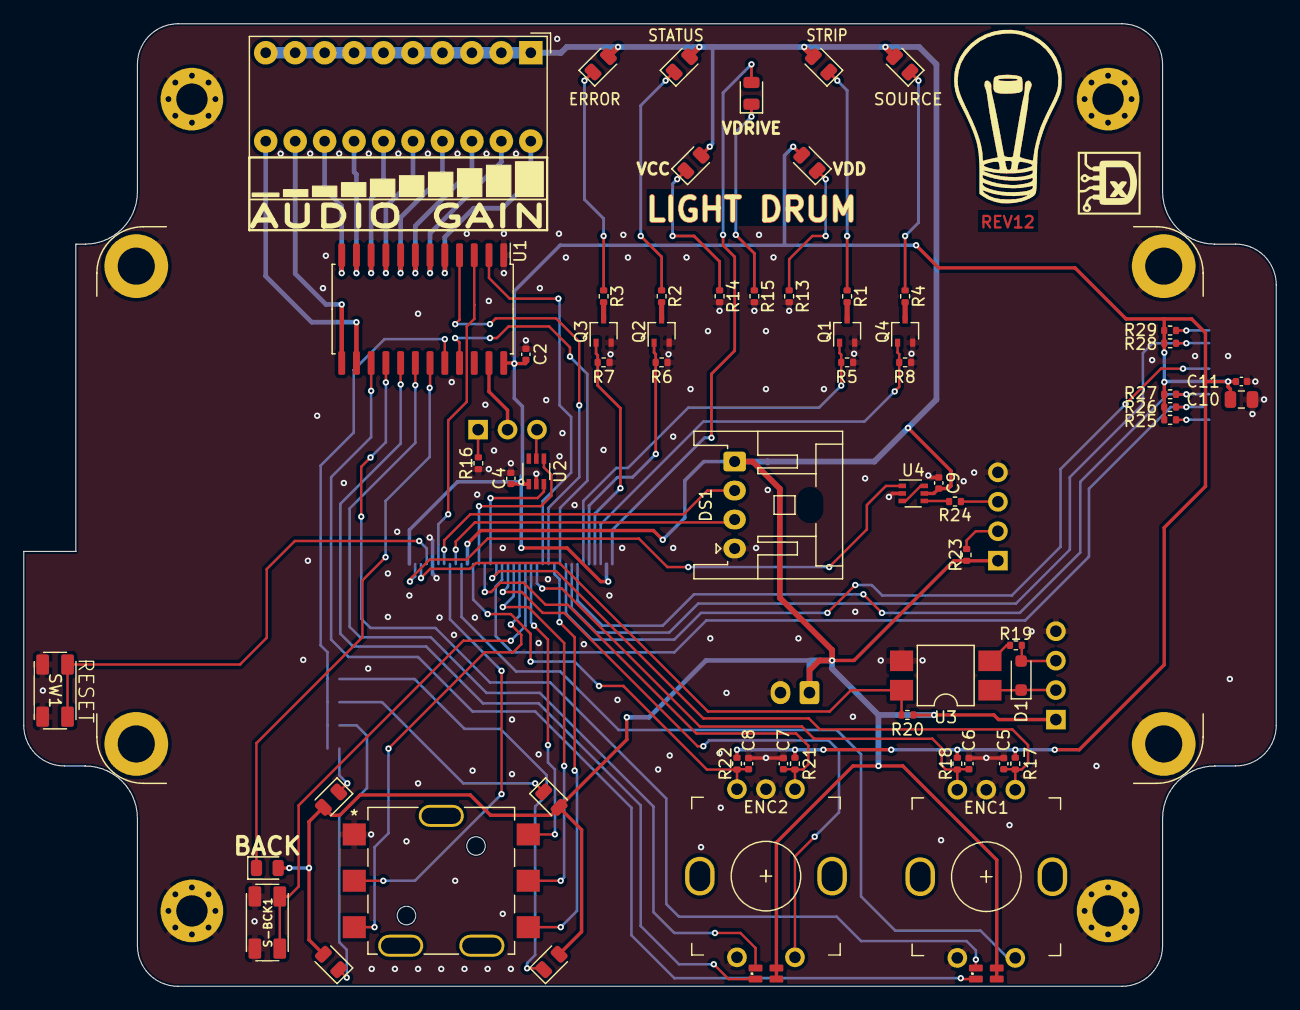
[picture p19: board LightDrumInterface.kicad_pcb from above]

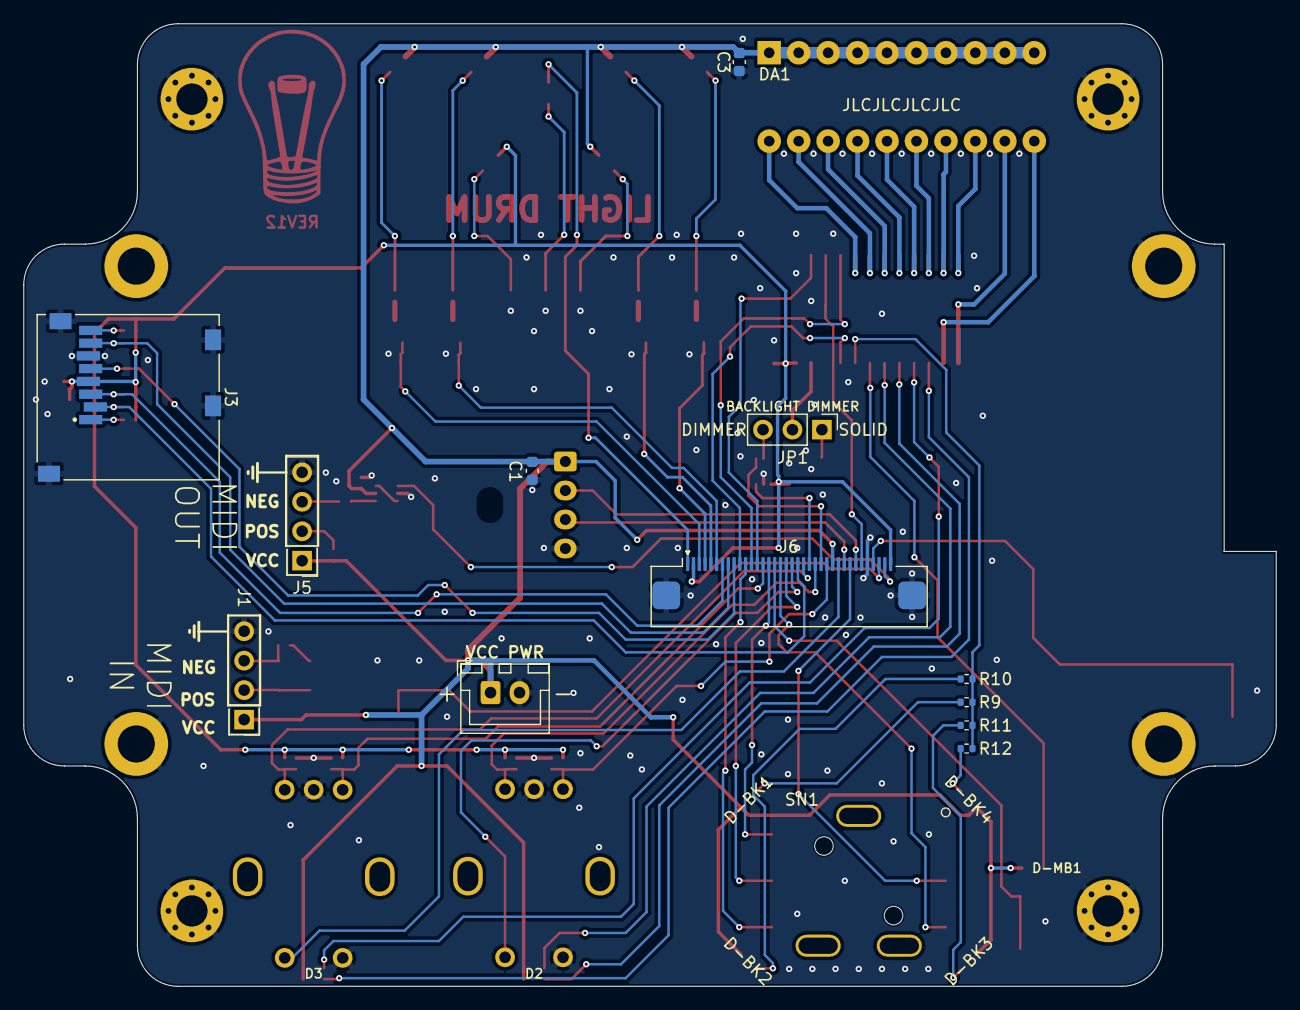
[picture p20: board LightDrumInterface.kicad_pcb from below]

Board: 2 copper layers, 108.0 x 83.0 mm, 81 parts (12 on the bottom side), 78 nets.

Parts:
C1, C3: 1uF; C_0603_1608Metric
C2, C4, C5, C6, C7, C8, C9, C11: 100nF; C_0402_1005Metric
C10: 4.7uF; C_0805_2012Metric
D1: 1N4448; D_SOD-323_HandSoldering
D2, D3: APHBM2012QBDSURKC; APHBM-2012
D-AUDIO-SEL1: GREEN; LED_0805_2012Metric
D-BK1, D-BK2, D-BK3, D-BK4: RED; LED_0805_2012Metric
D-DBG1: RED; LED_0805_2012Metric
D-MB1: RED; LED_0805_2012Metric
D-STA1: AMBER; LED_0805_2012Metric
D-STRIP-EN1: GREEN; LED_0805_2012Metric
D-VCC1: BLUE; LED_0805_2012Metric
D-VDD1: BLUE; LED_0805_2012Metric
D-VDRIVE1: BLUE; LED_0805_2012Metric
DA1: LTA-1000HR; HDSP-48xx
DS1: NX4024K032; NX4024K032-RA-S04B
ENC1: Encoder1; PEC11R
ENC2: Encoder2; PEC11R
ENCLOSURE1: LeMotech_Black_ENC-115x90
H1, H2, H3, H4: M2.5; MountingHole_2.7mm_M2.5_Pad_Via
J1: MIDI-IN; PinHeader_1x04_P2.54mm_Vertical
J3: Micro_SD_Card; MEM2061-01-188-00-A
J4: PWR-CONN; JST_XH_B2B-XH-A_Vertical
J5: MIDI-OUT; PinHeader_1x04_P2.54mm_Vertical
J6: 0541323662
JP1: BRT-JMP; PinHeader_1x03_P2.54mm_Vertical
Q1, Q2, Q3, Q4: NX6008NBKWX; SOT-323_SC-70
R1, R4: 100; R_0402_1005Metric
R2, R14, R16: 560; R_0402_1005Metric
R3: 620; R_0402_1005Metric
R5, R6, R7, R8, R17, R18, R20, R21, R22: 10K; R_0402_1005Metric
R9, R10, R11, R12: 300; R_0402_1005Metric
R13: 1.3K; R_0402_1005Metric
R15: 4.7K; R_0402_1005Metric
R19, R23, R24: 220; R_0402_1005Metric
R25, R26, R27, R28, R29: 47K; R_0402_1005Metric
S-BCK1: M-BACK; TL3365AF180QG
SN1: JS5208
SW1: RESET-SW; TL3365AF180QG
U1: STP16CP05; SOIC-24W_7.5x15.4mm_P1.27mm
U2: TPL0401B-10-Q1; Texas_R-PDSO-G6
U3: APC-817A1-SL; SMDIP-4_W7.62mm
U4: 74LVC2G14GW; SOT-363_SC-70-6

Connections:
/AUDIO-SRC-IND: J6.3, Q4.1 (G), R8.1
/DIAG-DEBUG: J6.4, Q3.1 (G), R7.1
/DIAG-STATUS: J6.5, Q2.1 (G), R6.1
/ENC1-A: C5.1, ENC1.A, J6.21, R17.1
/ENC1-B: C6.2, ENC1.B, J6.14, R18.2
/ENC1-SW: ENC1.S1, J6.27
/ENC2-A: C7.1, ENC2.A, J6.23, R21.1
/ENC2-B: C8.2, ENC2.B, J6.25, R22.2
/ENC2-SW: ENC2.S1, J6.19
/GRAPH-CLK: J6.31, U1.3 (CLK)
/GRAPH-LE: J6.12, U1.4 (LE/DM1)
/GRAPH-SDI: J6.13, U1.2 (SDI)
/GRAPH-~OE: J6.10, U1.21 (~OE/DM2)
/I2C-SCLK: J6.22, U2.3 (SCL)
/I2C-SDA: J6.24, U2.4 (SDA)
/MENU-ACT: J6.17, SN1.3 (PUSH)
/MENU-BACK: J6.16, S-BCK1.2 (B)
/MENU-DOWN: J6.11, SN1.6 (DOWN)
/MENU-LEFT: J6.29, SN1.2 (LEFT)
/MENU-RIGHT: J6.18, SN1.5 (RIGHT)
/MENU-UP: J6.15, SN1.4 (UP)
/MIDI-IN: J6.34, R20.1, U3.4
/MIDI-OUT: J6.35, U4.1 (1A)
/NAV-BACKLIGHT: R9.2, R10.2, R11.2, R12.2, U1.20 (~OUT15)
/R-EXT: JP1.2 (C), U1.23 (R-EXT)
/SCR-RX: DS1.3 (RX), J6.28
/SCR-TX: DS1.2 (TX), J6.30
/SD-CD: J3.2 (DAT3/CD), J6.20, R26.2
/SD-CLK: J3.5 (CLK), J6.9
/SD-CMD: J3.3 (CMD), J6.7, R27.2
/SD-D0: J3.7 (DAT0), J6.8, R28.2
/STRIP-PWR: J6.6, Q1.1 (G), R5.1
/~RESET: J6.33, SW1.2 (B)
GND: C1.2, C2.2, C3.2, C4.2, C5.2, C6.1, C7.2, C8.1, C9.2, C10.2, C11.2, DS1.4 (GND), ENC1.C, ENC1.S2, ENC2.C, ENC2.S2, H1.1, H2.1, H3.1, H4.1, J1.4, J3.6 (VSS), J3.9 (SHIELD), J4.2, J5.4, J6.32, J6.M (MNT), Q1.2 (S), Q2.2 (S), Q3.2 (S), Q4.2 (S), R5.2, R6.2, R7.2, R8.2, R13.2, R14.2, R15.2, R16.2, S-BCK1.1 (A), SN1.1 (COM), SW1.1 (A), U1.1 (GND), U2.2 (GND), U3.3, U4.2 (GND)
unnamed: D1.2 (A), J1.3, R19.1
unnamed: D1.1 (K), J1.2, U3.1
unnamed: D2.2 (B-K), U1.17 (~OUT12)
unnamed: D2.3 (R-K), U1.18 (~OUT13)
unnamed: D3.2 (B-K), U1.15 (~OUT10)
unnamed: D3.3 (R-K), U1.16 (~OUT11)
unnamed: D-AUDIO-SEL1.1 (K), R4.1
unnamed: D-BK1.1 (K), R9.1
unnamed: D-BK2.1 (K), R10.1
unnamed: D-BK3.1 (K), R11.1
unnamed: D-BK4.1 (K), R12.1
unnamed: D-DBG1.1 (K), R3.1
unnamed: D-MB1.1 (K), U1.19 (~OUT14)
unnamed: D-STA1.1 (K), R2.1
unnamed: D-STRIP-EN1.1 (K), R1.1
unnamed: D-VCC1.1 (K), R14.1
unnamed: D-VDD1.1 (K), R13.1
unnamed: D-VDRIVE1.1 (K), R15.1
unnamed: J3.8 (DAT1), R29.2
unnamed: J3.1 (DAT2), R25.2
unnamed: J5.2, R23.1
unnamed: J5.3, R24.1
unnamed: JP1.1 (A), R16.1
unnamed: JP1.3 (B), U2.5 (W)
unnamed: Q1.3 (D), R1.2
unnamed: Q2.3 (D), R2.2
unnamed: Q3.3 (D), R3.2
unnamed: Q4.3 (D), R4.2
unnamed: R19.2, U3.2
unnamed: DA1.20, U1.5 (~OUT0)
unnamed: DA1.19, U1.6 (~OUT1)
unnamed: DA1.18, U1.7 (~OUT2)
unnamed: DA1.17, U1.8 (~OUT3)
unnamed: DA1.16, U1.9 (~OUT4)
unnamed: DA1.15, U1.10 (~OUT5)
unnamed: DA1.14, U1.11 (~OUT6)
unnamed: DA1.13, U1.12 (~OUT7)
unnamed: DA1.12, U1.13 (~OUT8)
unnamed: DA1.11, U1.14 (~OUT9)
unnamed: U4.3 (2A), U4.6 (1Y)
unnamed: R24.2, U4.4 (2Y)
VCC: C1.1, C3.1, C9.1, D2.1 (B-A), D2.4 (R-A), D3.1 (B-A), D3.4 (R-A), D-AUDIO-SEL1.2 (A), D-BK1.2 (A), D-BK2.2 (A), D-BK3.2 (A), D-BK4.2 (A), D-DBG1.2 (A), D-MB1.2 (A), D-STA1.2 (A), D-STRIP-EN1.2 (A), D-VCC1.2 (A), DA1.1, DA1.2, DA1.3, DA1.4, DA1.5, DA1.6, DA1.7, DA1.8, DA1.9, DA1.10, DS1.1 (VCC), J1.1, J4.1, J5.1, J6.26, R20.2, R23.2, U4.5 (VCC)
VDD: C2.1, C4.1, C10.1, C11.1, D-VDD1.2 (A), J3.4 (VDD), J6.2, J6.36, R17.2, R18.1, R21.2, R22.1, R25.1, R26.1, R27.1, R28.1, R29.1, U1.24 (VDD), U2.1 (VDD)
Vdrive: D-VDRIVE1.2 (A), J6.1

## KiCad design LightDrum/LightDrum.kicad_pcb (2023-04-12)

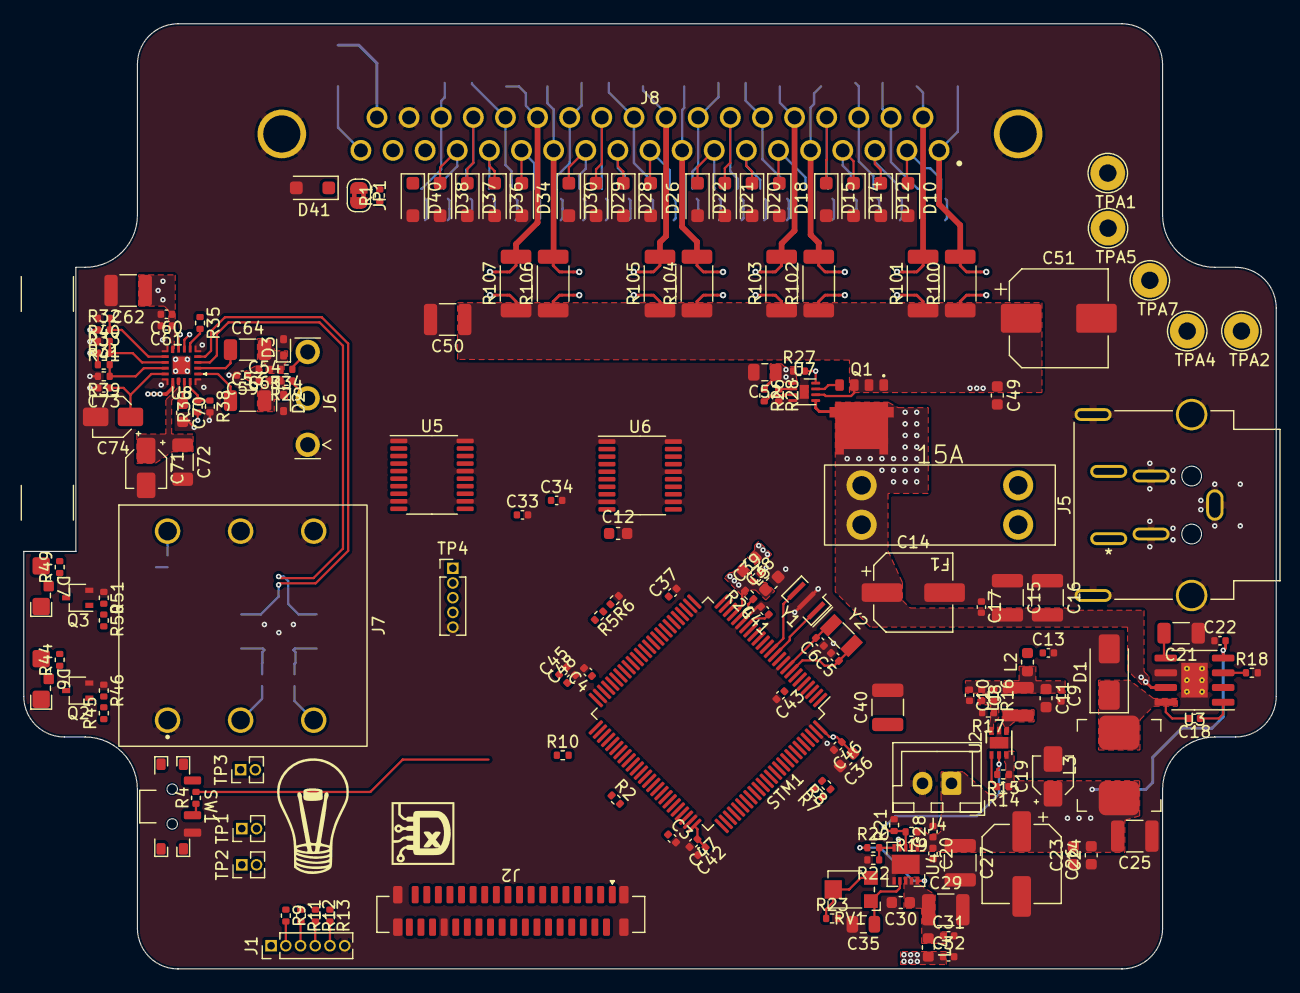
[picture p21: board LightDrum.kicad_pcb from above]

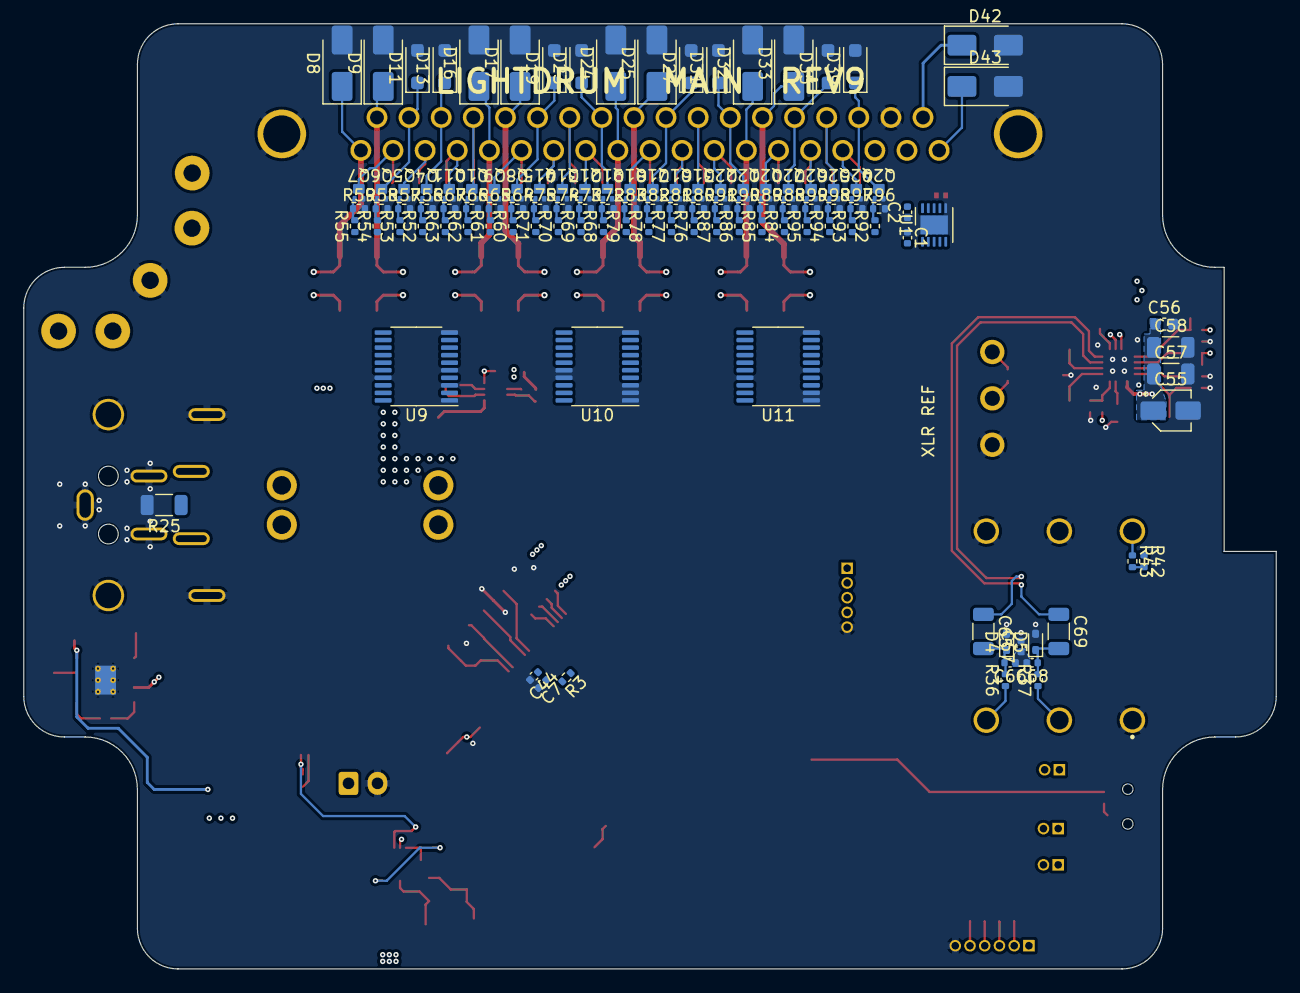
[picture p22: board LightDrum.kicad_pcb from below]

Board: 4 copper layers, 108.0 x 81.5 mm, 305 parts (115 on the bottom side), 209 nets.

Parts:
C1, C2, C7, C9, C10, C13, C17, C20, C22, C28, C31, C32, C33, C34, C37, C39, C41, C42, C43, C44, C45, C46, C47, C48, C60, C61, C73: 100nF; C_0402_1005Metric
C3, C4: 2.2uF; C_0402_1005Metric
C5, C6: 15pF; C_0402_1005Metric
C8: 22pF; C_0402_1005Metric
C11, C12, C23, C24, C30, C36, C38, C49, C56, C70: 1uF; C_0603_1608Metric
C14: 47uF; CP_Elec_6.3x7.7
C15, C16, C25, C27, C29, C40, C50, C62: 10uF; C_1210_3225Metric
C18: 10nF; C_0402_1005Metric
C19, C55, C71, C74: 10uF; CP_Elec_3x5.4
C21, C53, C64, C65, C69: 220nF; C_1206_3216Metric
C26: 100uF; CP_Elec_6.3x5.2
C35, C52: 4.7uF; C_0805_2012Metric
C51: 220uF; CP_Elec_8x10
C54, C63, C66, C68: 470pF; C_0402_1005Metric
C57, C58, C72: 100nF C0G; C_1206_3216Metric
C59, C67: 47pF; C_0402_1005Metric
D1: SK36AHE3; D_SMA
D2, D3, D4, D5: CEZ5V6; D_SOD-523
D6: HP IND - BLUE; LTST-S321TBKT
D7: XLR IND - BLUE; LTST-S321TBKT
D8, D9, D16, D17, D24, D25, D32, D33, D42, D43: SMAJ14CA; D_SMA
D10, D11, D12, D13, D14, D15, D18, D19, D20, D21, D22, D23, D26, D27, D28, D29, D30, D31, D34, D35, D36, D37, D38, D39, D40, D41: SMF4L13CA; D_SOD-123F
ENC0: LeMotech_Black_ENC-115x90
F1: 15A; 3557-10
J1: SWD CONN; PinHeader_1x06_P1.27mm_Vertical
J2: 0525593652
J4: PWR-CONN; JST_XH_B2B-XH-A_Vertical
J5: DIN-4-SH; KPJXHT-4S-S
J6: XLR3; CP30082-XLR
J7: SJ-63073E
J8: LED D-SUB; DSUB-37-182-037-113R531
JP1: DMX-RT-JUMP; SolderJumper-2_P1.3mm_Bridged2Bar_RoundedPad1.0x1.5mm
L1: 2.2uH; LQH3NPN
L2, L4, L5: 100nH; L_0603_1608Metric
L3: 22uH; PA4341
Q1: NTMFS5C430NLT1G; POWER-FET-5-DFN
Q2, Q3: NX6008NBKWX; SOT-323_SC-70
Q4, Q5, Q6, Q7, Q8, Q9, Q10, Q11, Q12, Q13, Q14, Q15, Q16, Q17, Q18, Q19, Q20, Q21, Q22, Q23, Q24, Q25, Q26, Q27: PMXB43UNEZ; DFN1010D-3
R1: 120; R_0402_1005Metric
R2, R10: 2.2K; R_0402_1005Metric
R3, R4, R5, R6, R26, R27, R28, R30, R31, R32, R33, R38, R39, R40, R41, R46, R51, R56, R57, R58, R59, R64, R65, R66, R67, R72, R73, R74, R75, R80, R81, R82, R83, R88, R89, R90, R91, R96, R97, R98, R99: 10K; R_0402_1005Metric
R7, R8: 4.7K; R_0402_1005Metric
R9, R11, R12, R13, R29, R34, R35, R36, R37: 22; R_0402_1005Metric
R14, R15, R17, R21, R42: 100K; R_0402_1005Metric
R16: 430K; R_0402_1005Metric
R18: 15K; R_0402_1005Metric
R19: 1.54M; R_0402_1005Metric
R20: 402K; R_0402_1005Metric
R22: 33K; R_0402_1005Metric
R23: 20K; R_0402_1005Metric
R24: 47; R_0402_1005Metric
R25: 10K; R_1206_3216Metric
R43, R45, R50, R52, R53, R54, R55, R60, R61, R62, R63, R68, R69, R70, R71, R76, R77, R78, R79, R84, R85, R86, R87, R92, R93, R94, R95: 100; R_0402_1005Metric
R44, R49: 1K; R_0402_1005Metric
R100, R101, R102, R103, R104, R105, R106, R107: 50m; R_2010_5025Metric
RV1: 4.7K; Bourns_TC33X
STM1: STM32F412VET3; LQFP-100_14x14mm_P0.5mm
SW1: BOOT0; PCM12SMTR
T1, T2, T3, T4, T5, T6, T7, T8, T9, T10, T11, T12, T13, T14, T15, T16: NET-TIE; NetTie-2_SMD_Pad0.25mm
TP1, TP2: I2C TP; PinHeader_1x02_P1.27mm_Vertical
TP3: MIDI TP; PinHeader_1x02_P1.27mm_Vertical
TP4: I2S TP; PinHeader_1x05_P1.27mm_Vertical
TPA1: VDRIVE TP; TestPoint_Loop_D2.54mm_Drill1.5mm_Beaded
TPA2: VCC TP; TestPoint_Loop_D2.54mm_Drill1.5mm_Beaded
TPA4: VDD TP; TestPoint_Loop_D2.54mm_Drill1.5mm_Beaded
TPA5: VDDA TP; TestPoint_Loop_D2.54mm_Drill1.5mm_Beaded
TPA7: GND TP; TestPoint_Loop_D2.54mm_Drill1.5mm_Beaded
U1: STR485; DFN-10-1EP_3x3mm_P0.5mm_EP1.65x2.38mm
U2: AP3401; DFN-6-1EP_2x2mm_P0.65mm_EP1x1.6mm
U3: LM22673-5V; SOIC-8-1EP_3.9x4.9mm_P1.27mm_EP2.29x3mm_ThermalVias
U4: TPS7A94; WSON-10-1EP_3x3mm
U5, U6: INA4181 A2; TSSOP-20_4.4x6.5mm_P0.65mm
U7: SLG55021; TDFN-8-1EP_2x2mm_P0.5mm_EP0.8x1.2mm
U8: PCM1821; TI-WQFN-RTE_(CUSTOM)-20-3x3mm-P0.5mm-EP1_1.4mm
U9, U10, U11: PCA9634_TSSOP20; TSSOP-20_4.4x6.5mm_P0.65mm
Y1: 16MHz; Resonator_SMD_Murata_CSTxExxV-3Pin_3.0x1.1mm
Y2: 32.768KHz; Crystal_SMD_3215-2Pin_3.2x1.5mm

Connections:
+12V: C14.1, C15.2, C16.2, C17.2, F1.2, Q1.5 (D), U3.7 (VIN), U7.5 (D)
/AUDIO INPUTS/JACK+: C65.2, C66.2, D4.1 (K), R36.2
/AUDIO INPUTS/JACK-: C68.1, C69.2, D5.1 (K), R37.2
/AUDIO INPUTS/JACK-IN+: C65.1, U8.3 (IN2+)
/AUDIO INPUTS/JACK-IN-: C69.1, U8.4 (IN2-)
/AUDIO INPUTS/JACK-SW: R42.2, R43.2
/AUDIO INPUTS/XLR+: C53.2, C54.2, D2.1 (K), R29.2
/AUDIO INPUTS/XLR-: C63.1, C64.2, D3.1 (K), R34.2
/AUDIO INPUTS/XLR-IN+: C53.1, U8.1 (IN1+)
/AUDIO INPUTS/XLR-IN-: C64.1, U8.2 (IN1-)
/AUDIO-SRC-IND_{PWM}: J2.3, STM1.4 (TIM9-CH1)
/DIAG-DEBUG_{PWM}: J2.4, STM1.65 (TIM3-CH3)
/DIAG-STATUS_{PWM}: J2.5, STM1.66 (TIM3-CH4)
/DMX+: D40.1 (K), J8.17, R1.2, U1.9 (B)
/DMX-: D41.1 (K), J8.18, JP1.1 (A), U1.8 (A)
/DMX-EN: U1.3 (DE), U1.4 (~RE)
/ENC1-B: J2.10, STM1.85 (PD4)
/ENC2-B: J2.25, STM1.51 (PB12)
/FI2C-SCLK_{S}: R10.2, STM1.54 (I2CFMP1-SCL), TP2.1, U9.18 (SCLK), U9.19 (SDA), U10.18 (SCLK), U11.18 (SCLK)
/FI2C-SDA_{S}: R2.2, STM1.64 (I2CFMP1-SDA), TP2.2, U10.19 (SDA), U11.19 (SDA)
/GRAPH-CLK_{S}: J2.29, STM1.43 (SPI4-SCK)
/GRAPH-LE_{S}: J2.14, STM1.60 (PD13)
/GRAPH-SDI_{S}: J2.31, STM1.5 (SPI4-COPI)
/GRAPH-~OE_{S}: J2.12, STM1.62 (PD15)
/HP-SEL-IND_{PWM}: R45.2, STM1.24 (TIM2-CH2)
/I2C-SCLK_{S}: J2.20, R7.2, STM1.92 (I2C1-SCL), TP1.1
/I2C-SDA_{S}: J2.23, R8.2, STM1.93 (I2C1-SDA), TP1.2
/I2S-CK_{S}: STM1.78 (I2S3-CK), TP4.2, U8.7 (BCLK)
/I2S-SD_{S}: R35.1, STM1.87 (I2S3-SD), TP4.3
/I2S-WS_{S}: STM1.77 (I2S3-WS), TP4.4, U8.8 (FSYNC)
/MICROCONTROLLER/BOOT0_{D}: R4.2, STM1.94 (BOOT0)
/MICROCONTROLLER/BOOT1_{D}: R5.1, R6.2, STM1.37 (BOOT1)
/MICROCONTROLLER/XTAL1: STM1.12 (OSC-IN), Y1.1
/MICROCONTROLLER/XTAL2: STM1.13 (OSC-OUT), Y1.3
/MIDI-IN_{S}: J2.32, STM1.26 (USART2-RX), TP3.1
/MIDI-OUT_{S}: J2.35, STM1.25 (USART2-TX), TP3.2
/POWER/PS-SW_: C18.2, D1.1 (K), L3.1, U3.8 (SW)
/POWER/VREF+: R24.1, STM1.21 (VREF+)
/PWM-~OE_{PWM}: STM1.63 (TIM3-CH1), U9.15 (~OE), U10.15 (~OE), U11.15 (~OE)
/RGB CONTROL/RGB Control 1/LED1-B: D14.1 (K), J8.4, Q11.3 (D)
/RGB CONTROL/RGB Control 1/LED1-B-SIG: R63.1, U9.6 (LED0)
/RGB CONTROL/RGB Control 1/LED1-G: D10.1 (K), J8.2, Q7.3 (D)
/RGB CONTROL/RGB Control 1/LED1-G-SIG: R55.1, U9.14 (LED7)
/RGB CONTROL/RGB Control 1/LED1-R: D12.1 (K), J8.3, Q5.3 (D)
/RGB CONTROL/RGB Control 1/LED1-R-SIG: R53.1, U9.12 (LED5)
/RGB CONTROL/RGB Control 1/LED2-G: D18.1 (K), J8.6, Q9.3 (D)
/RGB CONTROL/RGB Control 1/LED2-G-SIG: R61.1, U9.8 (LED2)
/RGB CONTROL/RGB Control 1/LED5-B: D15.1 (K), J8.23, Q10.3 (D)
/RGB CONTROL/RGB Control 1/LED5-B-SIG: R62.1, U9.7 (LED1)
/RGB CONTROL/RGB Control 1/LED5-G: D11.1 (K), J8.21, Q6.3 (D)
/RGB CONTROL/RGB Control 1/LED5-G-SIG: R54.1, U9.13 (LED6)
/RGB CONTROL/RGB Control 1/LED5-R: D13.1 (K), J8.22, Q4.3 (D)
/RGB CONTROL/RGB Control 1/LED5-R-SIG: R52.1, U9.11 (LED4)
/RGB CONTROL/RGB Control 1/LED6-G: D19.1 (K), J8.25, Q8.3 (D)
/RGB CONTROL/RGB Control 1/LED6-G-SIG: R60.1, U9.9 (LED3)
/RGB CONTROL/RGB Control 2/LED2-B: D22.1 (K), J8.8, Q13.3 (D)
/RGB CONTROL/RGB Control 2/LED2-B-SIG: R69.1, U10.12 (LED5)
/RGB CONTROL/RGB Control 2/LED2-R: D20.1 (K), J8.7, Q15.3 (D)
/RGB CONTROL/RGB Control 2/LED2-R-SIG: R71.1, U10.14 (LED7)
/RGB CONTROL/RGB Control 2/LED3-G: D26.1 (K), J8.10, Q19.3 (D)
/RGB CONTROL/RGB Control 2/LED3-G-SIG: R79.1, U10.6 (LED0)
/RGB CONTROL/RGB Control 2/LED3-R: D28.1 (K), J8.11, Q17.3 (D)
/RGB CONTROL/RGB Control 2/LED3-R-SIG: R77.1, U10.8 (LED2)
/RGB CONTROL/RGB Control 2/LED6-B: D23.1 (K), J8.27, Q12.3 (D)
/RGB CONTROL/RGB Control 2/LED6-B-SIG: R68.1, U10.11 (LED4)
/RGB CONTROL/RGB Control 2/LED6-R: D21.1 (K), J8.26, Q14.3 (D)
/RGB CONTROL/RGB Control 2/LED6-R-SIG: R70.1, U10.13 (LED6)
/RGB CONTROL/RGB Control 2/LED7-G: D27.1 (K), J8.29, Q18.3 (D)
/RGB CONTROL/RGB Control 2/LED7-G-SIG: R78.1, U10.7 (LED1)
/RGB CONTROL/RGB Control 2/LED7-R: D29.1 (K), J8.30, Q16.3 (D)
/RGB CONTROL/RGB Control 2/LED7-R-SIG: R76.1, U10.9 (LED3)
/RGB CONTROL/RGB Control 3/LED3-B: D30.1 (K), J8.12, Q23.3 (D)
/RGB CONTROL/RGB Control 3/LED3-B-SIG: R87.1, U11.14 (LED7)
/RGB CONTROL/RGB Control 3/LED4-B: D38.1 (K), J8.16, Q25.3 (D)
/RGB CONTROL/RGB Control 3/LED4-B-SIG: R93.1, U11.8 (LED2)
/RGB CONTROL/RGB Control 3/LED4-G: D34.1 (K), J8.14, Q21.3 (D)
/RGB CONTROL/RGB Control 3/LED4-G-SIG: R85.1, U11.12 (LED5)
/RGB CONTROL/RGB Control 3/LED4-R: D36.1 (K), J8.15, Q27.3 (D)
/RGB CONTROL/RGB Control 3/LED4-R-SIG: R95.1, U11.6 (LED0)
/RGB CONTROL/RGB Control 3/LED7-B: D31.1 (K), J8.31, Q22.3 (D)
/RGB CONTROL/RGB Control 3/LED7-B-SIG: R86.1, U11.13 (LED6)
/RGB CONTROL/RGB Control 3/LED8-B: D39.1 (K), J8.35, Q24.3 (D)
/RGB CONTROL/RGB Control 3/LED8-B-SIG: R92.1, U11.9 (LED3)
/RGB CONTROL/RGB Control 3/LED8-G: D35.1 (K), J8.33, Q20.3 (D)
/RGB CONTROL/RGB Control 3/LED8-G-SIG: R84.1, U11.11 (LED4)
/RGB CONTROL/RGB Control 3/LED8-R: D37.1 (K), J8.34, Q26.3 (D)
/RGB CONTROL/RGB Control 3/LED8-R-SIG: R94.1, U11.7 (LED1)
/RGB CONTROL/Strip Connector/STRIP-PWR1: D8.1 (K), J8.1, R100.2, T1.2
/RGB CONTROL/Strip Connector/STRIP-PWR2: D16.1 (K), J8.5, R102.2, T5.2
/RGB CONTROL/Strip Connector/STRIP-PWR3: D24.1 (K), J8.9, R104.2, T9.2
/RGB CONTROL/Strip Connector/STRIP-PWR4: D32.1 (K), J8.13, R106.2, T13.2
/RGB CONTROL/Strip Connector/STRIP-PWR5: D9.1 (K), J8.20, R101.2, T2.2
/RGB CONTROL/Strip Connector/STRIP-PWR6: D17.1 (K), J8.24, R103.2, T6.2
/RGB CONTROL/Strip Connector/STRIP-PWR7: D25.1 (K), J8.28, R105.2, T10.2
/RGB CONTROL/Strip Connector/STRIP-PWR8: D33.1 (K), J8.32, R107.2, T14.2
/RGB CONTROL/Strip Current Monitors/S1-CURR+: T3.2, U6.6 (IN+)
/RGB CONTROL/Strip Current Monitors/S1-CURR-: T1.1, U6.7 (IN-)
/RGB CONTROL/Strip Current Monitors/S2-CURR+: T7.2, U6.17 (IN+)
/RGB CONTROL/Strip Current Monitors/S2-CURR-: T5.1, U6.18 (IN-)
/RGB CONTROL/Strip Current Monitors/S3-CURR+: T11.2, U5.6 (IN+)
/RGB CONTROL/Strip Current Monitors/S3-CURR-: T9.1, U5.7 (IN-)
/RGB CONTROL/Strip Current Monitors/S4-CURR+: T15.2, U5.17 (IN+)
/RGB CONTROL/Strip Current Monitors/S4-CURR-: T13.1, U5.18 (IN-)
/RGB CONTROL/Strip Current Monitors/S5-CURR+: T4.2, U6.15 (IN+)
/RGB CONTROL/Strip Current Monitors/S5-CURR-: T2.1, U6.14 (IN-)
/RGB CONTROL/Strip Current Monitors/S6-CURR+: T8.2, U6.4 (IN+)
/RGB CONTROL/Strip Current Monitors/S6-CURR-: T6.1, U6.3 (IN-)
/RGB CONTROL/Strip Current Monitors/S7-CURR+: T12.2, U5.15 (IN+)
/RGB CONTROL/Strip Current Monitors/S7-CURR-: T10.1, U5.14 (IN-)
/RGB CONTROL/Strip Current Monitors/S8-CURR+: T16.2, U5.4 (IN+)
/RGB CONTROL/Strip Current Monitors/S8-CURR-: T14.1, U5.3 (IN-)
/SCR-RX_{S}: J2.19, STM1.68 (USART1-TX)
/SCR-TX_{S}: J2.21, STM1.69 (USART1-RX)
/SD-CD_{S}: J2.34, STM1.82 (PD1)
/SD-CLK_{S}: J2.9, STM1.80 (SDIO-CK)
/SD-CMD_{S}: J2.7, STM1.83 (SDIO-CMD)
/SD-D0_{S}: J2.8, STM1.90 (SDIO-D0)
/STRIP-ESHDN: R26.2, STM1.15 (PC0), U7.3 (~SHDN)
/STRIP-MON_{A}1: STM1.29 (ADC-4), U6.8 (OUT)
/STRIP-MON_{A}2: STM1.32 (ADC-7), U6.19 (OUT)
/STRIP-MON_{A}3: STM1.33 (ADC1-14), U5.8 (OUT)
/STRIP-MON_{A}4: STM1.36 (ADC-9), U5.19 (OUT)
/STRIP-MON_{A}5: STM1.30 (ADC-5), U6.13 (OUT)
/STRIP-MON_{A}6: STM1.31 (ADC-6), U6.2 (OUT)
/STRIP-MON_{A}7: STM1.34 (ADC1-15), U5.13 (OUT)
/STRIP-MON_{A}8: STM1.35 (ADC-8), U5.2 (OUT)
/STRIP-PG: R27.2, STM1.18 (PC3), U7.8 (PG)
/STRIP-PWR: J2.6, R28.1, STM1.81 (PD0), U7.2 (ON)
/VDD-PG: R15.2, R19.2, R21.1, STM1.16 (PC1), U2.2 (PG), U4.3 (EN_UV)
/VDDA-PG: STM1.17 (PC2), U4.4 (PG)
/XLR-SEL-IND_{PWM}: R50.2, STM1.23 (TIM2-CH1)
/~RESET_{C}: C7.1, J2.33, R3.2, R9.1, STM1.14 (~RST)
GND: C1.1, C2.1, C3.2, C4.2, C5.2, C6.1, C7.2, C9.2, C10.2, C11.2, C12.2, C13.2, C14.2, C15.1, C16.1, C17.1, C19.2, C20.2, C21.1, C22.1, C23.1, C24.1, C25.1, C26.2, C27.2, C28.2, C29.2, C30.2, C31.2, C32.2, C33.2, C34.2, C35.2, C36.2, C37.2, C38.2, C39.2, C40.2, C41.2, C42.2, C43.2, C44.2, C45.2, C46.2, C47.2, C48.2, C49.2, C50.2, C51.2, C52.2, C55.2, C56.2, C57.2, C58.2, C59.2, C60.2, C61.2, C62.2, C67.2, C70.2, C71.2, C72.2, C73.2, C74.2, D1.2 (A), D2.2 (A), D3.2 (A), D4.2 (A), D5.2 (A), D8.2 (A), D9.2 (A), D10.2 (A), D11.2 (A), D12.2 (A), D13.2 (A), D14.2 (A), D15.2 (A), D16.2 (A), D17.2 (A), D18.2 (A), D19.2 (A), D20.2 (A), D21.2 (A), D22.2 (A), D23.2 (A), D24.2 (A), D25.2 (A), D26.2 (A), D27.2 (A), D28.2 (A), D29.2 (A), D30.2 (A), D31.2 (A), D32.2 (A), D33.2 (A), D34.2 (A), D35.2 (A), D36.2 (A), D37.2 (A), D38.2 (A), D39.2 (A), D40.2 (A), D41.2 (A), D42.2 (A), D43.2 (A), J1.6, J2.30, J2.M (MNT), J4.2, J5.3, J5.4, J5.M, J6.1, J7.1 (S), J7.5 (TN), J7.6 (RN), J8.0 (PAD), J8.36, Q2.2 (S), Q3.2 (S), Q4.2 (S), Q5.2 (S), Q6.2 (S), Q7.2 (S), Q8.2 (S), Q9.2 (S), Q10.2 (S), Q11.2 (S), Q12.2 (S), Q13.2 (S), Q14.2 (S), Q15.2 (S), Q16.2 (S), Q17.2 (S), Q18.2 (S), Q19.2 (S), Q20.2 (S), Q21.2 (S), Q22.2 (S), Q23.2 (S), Q24.2 (S), Q25.2 (S), Q26.2 (S), Q27.2 (S), R6.1, R17.2, R18.2, R21.2, R22.2, R23.2, R25.2, R28.2, R38.2, R39.2, R40.2, R41.2, R46.1, R51.1, R56.2, R57.2, R58.2, R59.2, R64.2, R65.2, R66.2, R67.2, R72.2, R73.2, R74.2, R75.2, R80.2, R81.2, R82.2, R83.2, R88.2, R89.2, R90.2, R91.2, R96.2, R97.2, R98.2, R99.2, STM1.10 (VSS), STM1.20 (VSSA/VREF-), STM1.27 (VSS), STM1.49 (VSS), STM1.74 (VSS), STM1.99 (VSS), SW1.3 (C), TP4.5, TPA7.1, U1.6 (GND), U1.11 (GND), U2.5 (GND), U2.7 (GND), U3.6 (GND), U3.9 (GND), U4.6 (GND), U4.11 (GND), U5.1 (REF), U5.9 (REF), U5.12 (REF), U5.16, U5.20 (REF), U6.1 (REF), U6.9 (REF), U6.12 (REF), U6.16, U6.20 (REF), U7.4 (GND), U7.9 (GND), U8.5 (GND), U8.10 (GND), U8.15 (GND), U8.20 (GND), U8.21 (GND), U9.1 (A0), U9.3 (A2), U9.5 (A4), U9.10 (GND), U9.17 (A6), U10.1 (A0), U10.2 (A1), U10.3 (A2), U10.10 (GND), U10.16 (A5), U10.17 (A6), U11.1 (A0), U11.2 (A1), U11.5 (A4), U11.10 (GND), U11.17 (A6), Y1.2
unnamed: C8.1, C9.1, C10.1, C11.1, C12.1, L1.2, L2.1, R16.1
unnamed: C54.1, C59.1, C63.2
unnamed: C66.1, C67.1, C68.2
unnamed: D6.1 (K), R44.2
unnamed: D7.1 (K), R49.2
unnamed: F1.1, J5.1, J5.2, R25.1
unnamed: J1.2, R9.2
unnamed: J1.3, R11.2
unnamed: J1.4, R12.2
unnamed: J1.5, R13.2
unnamed: J6.2, R29.1
unnamed: J6.3, R34.1
unnamed: J7.3 (R), R37.1
unnamed: J7.4 (SN), R43.1
unnamed: J7.2 (T), R36.1
unnamed: JP1.2 (B), R1.1
unnamed: Q1.4 (G), U7.7 (G)
unnamed: Q2.3 (D), R44.1
unnamed: Q2.1 (G), R45.1, R46.2
unnamed: Q3.3 (D), R49.1
unnamed: Q3.1 (G), R50.1, R51.2
unnamed: Q4.1 (G), R52.2, R56.1
unnamed: Q5.1 (G), R53.2, R57.1
unnamed: Q6.1 (G), R54.2, R58.1
unnamed: Q7.1 (G), R55.2, R59.1
unnamed: Q8.1 (G), R60.2, R64.1
unnamed: Q9.1 (G), R61.2, R65.1
unnamed: Q10.1 (G), R62.2, R66.1
unnamed: Q11.1 (G), R63.2, R67.1
unnamed: Q12.1 (G), R68.2, R72.1
unnamed: Q13.1 (G), R69.2, R73.1
unnamed: Q14.1 (G), R70.2, R74.1
unnamed: Q15.1 (G), R71.2, R75.1
unnamed: Q16.1 (G), R76.2, R80.1
unnamed: Q17.1 (G), R77.2, R81.1
unnamed: Q18.1 (G), R78.2, R82.1
unnamed: Q19.1 (G), R79.2, R83.1
unnamed: Q20.1 (G), R84.2, R88.1
unnamed: Q21.1 (G), R85.2, R89.1
unnamed: Q22.1 (G), R86.2, R90.1
unnamed: Q23.1 (G), R87.2, R91.1
unnamed: Q24.1 (G), R92.2, R96.1
unnamed: Q25.1 (G), R93.2, R97.1
unnamed: Q26.1 (G), R94.2, R98.1
unnamed: Q27.1 (G), R95.2, R99.1
unnamed: R23.1, RV1.2, RV1.3
unnamed: C4.1, STM1.48 (VCAP1)
unnamed: C3.1, STM1.73 (VCAP2)
unnamed: C5.1, STM1.8 (OSC32-IN), Y2.1
unnamed: C6.2, STM1.9 (OSC32-OUT), Y2.2
unnamed: R4.1, SW1.2 (B)
unnamed: R14.2, U2.1 (EN)
unnamed: C8.2, R16.2, R17.1, U2.6 (FB)
unnamed: L1.1, U2.4 (LX)
unnamed: C18.1, U3.1 (BOOT)
unnamed: R18.1, U3.3 (IADJ)
unnamed: C21.2, U3.5 (SS)
unnamed: R20.2, R22.1, U4.5 (FB_PG)
unnamed: C35.1, RV1.1, U4.7 (NR/SS)
unnamed: C29.1, C30.1, C31.1, L4.1, R20.1, U4.8 (SNS), U4.9 (OUT), U4.10 (OUT)
unnamed: C71.1, C72.1, U8.17 (AREG)
unnamed: C73.1, C74.1, U8.14 (DREG)
unnamed: R30.2, R38.1, U8.19 (FMT0)
unnamed: R33.2, R41.1, U8.12 (MD0)
unnamed: R32.2, R40.1, U8.11 (MD1)
unnamed: R31.2, R39.1, U8.13 (MSZ)
unnamed: R35.2, U8.6 (SDOUT)
unnamed: C70.1, U8.18 (VREF)
SWDCLK_{D}: R11.1, STM1.76 (SWCLK)
SWDIO_{D}: R12.1, STM1.72 (SWDIO)
SWO_{D}: R13.1, STM1.89 (SWO)
VAA: C32.1, C55.1, C56.1, C57.1, C58.1, L4.2, U8.16 (VDDA)
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

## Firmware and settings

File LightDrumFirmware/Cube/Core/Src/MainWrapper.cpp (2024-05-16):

/*
 * MainWrapper.cpp
 *
 * This sucks. The code config generator doesnt export in *.cpp files.
 * The only way to get *.cpp code to run is to wrap the main functions.
 *
 *  Created on: Feb 5, 2023
 *      Author: Daxxn
 */

#include <math.h>
#include "main.h"
#include "StripCurrent.h"
#include "Nextion.h"
#include "ShiftRegs.h"
#include "Utils.h"
#include "PCA9634.h"
#include "StripControl.h"
#include "Screen/Button.h"
#include "Screen/PageButton.h"
#include "Screen/Page.h"
#include "Screen/ProgressBar.h"
#include "ScreenControl.h"
#include "RotaryEncoder.h"

#define AUDIO_BUFFER_SIZE 128
#define AUDIO_HALF_BUFFER_SIZE 64
#define TEST_OFFSET -32000

ADC_HandleTypeDef *currentADCHandle;
DMA_HandleTypeDef *currentADC_DMAHandle;

FMPI2C_HandleTypeDef *stripI2cHandle;
DMA_HandleTypeDef *dmaTXStripHandle;
I2C_HandleTypeDef *i2cHandle;

I2S_HandleTypeDef *audioHandle;
DMA_HandleTypeDef *dmaRXAudioHandle;

SPI_HandleTypeDef *graphHandle;

TIM_HandleTypeDef *pwm1Handle;
TIM_HandleTypeDef *pwm2Handle;
TIM_HandleTypeDef *pwm3Handle;
TIM_HandleTypeDef *pwm6Handle;
TIM_HandleTypeDef *adcTimHandle;

UART_HandleTypeDef *screenHandle;
UART_HandleTypeDef *midiHandle;
UART_HandleTypeDef *dmxHandle;

RTC_HandleTypeDef *rtcHandle;
SD_HandleTypeDef *sdHandle;

ShiftRegs shiftReg;
Nextion next = Nextion();

StripCurrent stripCurr;
StripControl stripCtrl;

PCA9634 ledA;
PCA9634 ledB;
PCA9634 ledC;

uint8_t ledCount = 0;

uint8_t count = 0;
uint8_t page = 0;

PCA9634Settings settings;

/* LED Test Counts -----------------------------------------------------------*/
const uint8_t greenOffset = 85;
const uint8_t blueOffset = 170;

uint32_t audioBuffer[AUDIO_BUFFER_SIZE];

bool indicator = false;

GPIO_PinState menuLeftPrev = GPIO_PIN_RESET;

GPIO_PinState relayState = GPIO_PIN_RESET;
uint32_t adcReading = 0;

RotaryEncoder encoder1;
RotaryEncoder encoder2;

/* Screen Components ---------------------------------------------------------*/
ScreenControl screenCtrl;

void ScreenChangeCallback(uint8_t pageID)
{
	screenCtrl.ChangePage(pageID);
}

// Global
PageButton homeBtn = PageButton(&next, 1, "pb1", 0, 0, 1, ScreenChangeCallback);
PageButton settingsBtn = PageButton(&next, 2, "pb5", 1, 0, 5, ScreenChangeCallback);

PageButton subMenuPageBtns[] = {
		homeBtn,
		settingsBtn
};

// MainMenu
PageButton mainPageBtn   = PageButton(&next, 7, "pb1", 0, 0, 2, ScreenChangeCallback);
PageButton chnPageBtn    = PageButton(&next, 1, "pb2", 0, 1, 3, ScreenChangeCallback);
PageButton chCfgPageBtn  = PageButton(&next, 6, "pb3", 0, 2, 4, ScreenChangeCallback);
PageButton audPageBtn    = PageButton(&next, 4, "pb5", 0, 3, 6, ScreenChangeCallback);
PageButton patPageBtn    = PageButton(&next, 5, "pb7", 1, 1, 8, ScreenChangeCallback);
PageButton colPageBtn    = PageButton(&next, 8, "pb6", 1, 2, 7, ScreenChangeCallback);
PageButton settPageBtn   = PageButton(&next, 2, "pb4", 1, 3, 5, ScreenChangeCallback);

PageButton mainBtns[] = {
		mainPageBtn,
		chnPageBtn,
		chCfgPageBtn,
		audPageBtn,
		patPageBtn,
		colPageBtn,
		settPageBtn
};

Page homePage = Page(&next, 1, NULL, 0, mainBtns, 7);

// Run

Button runBtn = Button(&next, 2, "b0", 0, 1);

Button runBtns[] = {
		runBtn
};

PageButton runHomeBtn = PageButton(&next, 2, "pb1", 0, 0, 1, ScreenChangeCallback);
PageButton runSettingsBtn = PageButton(&next, 3, "pb5", 1, 0, 5, ScreenChangeCallback);

PageButton runPageBtns[] = {
		runHomeBtn,
		runSettingsBtn
};

Page runPage = Page(&next, 2, runBtns, 1, runPageBtns, 2);

//Channel Vis
Button srcCh1Btn = Button(&next, 3, "b0", 0, 1);
Button srcCh2Btn = Button(&next, 21, "b1", 1, 1);
Button srcCh3Btn = Button(&next, 22, "b2", 2, 1);
Button srcCh4Btn = Button(&next, 23, "b3", 3, 1);
Button srcCh5Btn = Button(&next, 24, "b4", 4, 1);
Button srcCh6Btn = Button(&next, 25, "b5", 5, 1);
Button srcCh7Btn = Button(&next, 26, "b6", 6, 1);
Button srcCh8Btn = Button(&next, 27, "b7", 7, 1);

ProgressBar ch1Bar = ProgressBar(&next, 1, "j0");
ProgressBar ch2Bar = ProgressBar(&next, 4, "j1");
ProgressBar ch3Bar = ProgressBar(&next, 6, "j2");
ProgressBar ch4Bar = ProgressBar(&next, 8, "j3");
ProgressBar ch5Bar = ProgressBar(&next, 10, "j4");
ProgressBar ch6Bar = ProgressBar(&next, 12, "j5");
ProgressBar ch7Bar = ProgressBar(&next, 14, "j6");
ProgressBar ch8Bar = ProgressBar(&next, 16, "j7");

PageButton chVisHomeBtn = PageButton(&next, 18, "pb1", 0, 0, 1, ScreenChangeCallback);
PageButton chVisSettingsBtn = PageButton(&next, 19, "pb5", 1, 0, 5, ScreenChangeCallback);

PageButton chVisPageBtns[] = {
		chVisHomeBtn,
		chVisSettingsBtn
};

Button chVisBtns[] = {
		srcCh1Btn,
		srcCh2Btn,
		srcCh3Btn,
		srcCh4Btn,
		srcCh5Btn,
		srcCh6Btn,
		srcCh7Btn,
		srcCh8Btn
};

ProgressBar progBars[] = {
		ch1Bar,
		ch2Bar,
		ch3Bar,
		ch4Bar,
		ch5Bar,
		ch6Bar,
		ch7Bar,
		ch8Bar,
};

Page channelVisPage = Page(&next, 3, chVisBtns, 8, chVisPageBtns, 2, progBars, 8);

// Channel Config
Button ch1Btn = Button(&next, 13, "b0", 0, 2);
Button ch2Btn = Button(&next, 13, "b1", 1, 2);
Button ch3Btn = Button(&next, 13, "b2", 2, 2);
Button ch4Btn = Button(&next, 13, "b3", 3, 2);
Button ch5Btn = Button(&next, 13, "b4", 4, 2);
Button ch6Btn = Button(&next, 13, "b5", 5, 2);
Button ch7Btn = Button(&next, 13, "b6", 6, 2);
Button ch8Btn = Button(&next, 13, "b7", 7, 2);

PageButton chCfgHomeBtn = PageButton(&next, 3, "pb1", 0, 0, 1, ScreenChangeCallback);
PageButton chCfgSettingsBtn = PageButton(&next, 4, "pb5", 1, 0, 5, ScreenChangeCallback);

PageButton chCfgPageBtns[] = {
		chCfgHomeBtn,
		chCfgSettingsBtn
};

Button chCfgBtns[] = {
		ch1Btn,
		ch2Btn,
		ch3Btn,
		ch4Btn,
		ch5Btn,
		ch6Btn,
		ch7Btn,
		ch8Btn,
};

Page channelConfigPage = Page(&next, 4, chCfgBtns, 8, chCfgPageBtns, 2);

//Settings
Button saveBtn = Button(&next, 0, "b0", 0, 2);

Button settBtns[] = {
		saveBtn
};

PageButton settPageBtns[] = {
		homeBtn
};

Page settingsPage = Page(&next, 5, settBtns, 1, settPageBtns, 1);

// Audio
Button audSrcXlrBtn = Button(&next, 12, "b7", 2, 1);
Button audSrcJackBtn = Button(&next, 13, "b0", 3, 1);

PageButton audHomeBtn = PageButton(&next, 15, "pb1", 0, 0, 1, ScreenChangeCallback);
PageButton audSettingsBtn = PageButton(&next, 16, "pb5", 1, 0, 5, ScreenChangeCallback);

PageButton audPageBtns[] = {
		audHomeBtn,
		audSettingsBtn
};

Button audBtns[] = {
		audSrcXlrBtn,
		audSrcJackBtn
};

Page audioPage = Page(&next, 6, audBtns, 2, audPageBtns, 2);

// Colors
Button colChSelBtn = Button(&next, 0, "b0", 0, 2);
Button colorBtns[] = {
		colChSelBtn
};

PageButton colHomeBtn = PageButton(&next, 5, "pb1", 0, 0, 1, ScreenChangeCallback);
PageButton colSettingsBtn = PageButton(&next, 6, "pb5", 1, 0, 5, ScreenChangeCallback);

PageButton colPageBtns[] = {
		colHomeBtn,
		colSettingsBtn
};

Page colorPage = Page(&next, 7, colorBtns, 0, colPageBtns, 2);

// Pattern

//Button patternBtns[] = {};

PageButton patHomeBtn = PageButton(&next, 4, "pb1", 0, 0, 1, ScreenChangeCallback);
PageButton patSettingsBtn = PageButton(&next, 5, "pb5", 1, 0, 5, ScreenChangeCallback);

PageButton patPageBtns[] = {
		patHomeBtn,
		patSettingsBtn
};

Page patternPage = Page(&next, 7, NULL, 0, patPageBtns, 2);

// Screen Control
Page pages[] = {
		homePage,
		runPage,
		channelVisPage,
		channelConfigPage,
		settingsPage,
		audioPage,
		colorPage
};

#define NAV_BACKLIGHT  0
#define MENU_BACK_IND  1
#define MENU_DOWN_IND  2
#define MENU_UP_IND    3
#define MENU_LEFT_IND  4
#define MENU_RIGHT_IND 5

const int delay = 50;
const int i = 127;
//void Blink()
//{
//	HAL_GPIO_WritePin(EXT_LED_GPIO_Port, EXT_LED_Pin, GPIO_PIN_SET);
//	HAL_Delay(200);
//	HAL_GPIO_WritePin(EXT_LED_GPIO_Port, EXT_LED_Pin, GPIO_PIN_RESET);
//}


void EaseInDebug()
{
	for (int i = 0; i < 255; ++i) {
//		TIM3->CCR3 = i * 256;
		__HAL_TIM_SET_COMPARE(pwm3Handle, TIM_CHANNEL_3, i * 511);
		HAL_Delay(20);
	}
}

void EaseInStatus()
{
	for (int i = 0; i < 255; ++i) {
//		TIM3->CCR2 = i * 256;
		__HAL_TIM_SET_COMPARE(pwm3Handle, TIM_CHANNEL_2, i * 511);
		HAL_Delay(20);
	}
}

void ReadCurrent()
{
	HAL_ADC_Start(currentADCHandle);
	if (HAL_ADC_PollForConversion(currentADCHandle, 500) == HAL_OK)
	{
		adcReading = HAL_ADC_GetValue(currentADCHandle);
//		uint8_t perc = (uint8_t)((adcReading / UINT8_MAX) * 100);
//		screen.SetProgressBar(0, perc);
	}

}

void AudioLevelsAverage()
{
//	double sum = 0;
//	double average = 0;
//	for (int i = 0; i < AUDIO_BUFFER_SIZE; ++i) {
//		sum += audioBuffer[i];
//	}
//	average = sum / 64;
}

void ReadAudioTest()
{
//	if (HAL_I2S_Receive(audioHandle, audioBuffer, AUDIO_BUFFER_SIZE, 200) == HAL_OK)
//	{
//		AudioLevelsAverage();
//	}
}

float rms = 0;
float sum = 0;
int rmsI = 0;
void RMSTest()
{
	sum = 0;
	for (rmsI = 0; rmsI < AUDIO_HALF_BUFFER_SIZE; rmsI += 2) {
		sum += pow(audioBuffer[rmsI], 2);
	}
	rms = sqrt(1.0 / (float)AUDIO_HALF_BUFFER_SIZE * sum) + TEST_OFFSET;

	__HAL_TIM_SET_COMPARE(pwm3Handle, TIM_CHANNEL_4, (uint32_t)rms);
}

void AudioFullCallback()
{
	RMSTest();
//	AudioLevelsAverage();
//	double max = 0;
//	for (int i = 0; i < AUDIO_HALF_BUFFER_SIZE; ++i) {
//		if (max < audioBuffer[i])
//		{
//			max += audioBuffer[i];
//		}
//	}
//	uint32_t avg = max / AUDIO_BUFFER_SIZE;
//	__HAL_TIM_SET_COMPARE(pwm3Handle, TIM_CHANNEL_4, avg);
}

void AudioHalfFullCallback()
{

}

void CurrentConvFullCallback()
{
	stripCurr.Calc();
}

void PageChangeCallbackHandle(uint8_t pageNumber)
{
	screenCtrl.ChangePageEvent(pageNumber);
}

void TouchEventCallbackHandle(uint8_t pageID, uint8_t compID, uint8_t event)
{
	screenCtrl.TouchEvent(pageID, compID, event);
}

void ScreenReceiveCallback()
{
	next.Receive();
}

void StripCurrentAlertCallback(StripCurrentStatus status)
{

}

/**
  * @brief C++ Initialization Function
  * @retval None
  */
HAL_StatusTypeDef Init(
		ADC_HandleTypeDef    *in_hadc1,
		DMA_HandleTypeDef    *in_hdma_adc1,

		FMPI2C_HandleTypeDef *in_hfmpi2c1,
		DMA_HandleTypeDef    *in_hdma_fmpi2c1_tx,

		I2C_HandleTypeDef    *in_hi2c1,

		I2S_HandleTypeDef    *in_hi2s5,
		DMA_HandleTypeDef    *hdma_spi5_rx,

		SPI_HandleTypeDef    *in_hspi4,

		TIM_HandleTypeDef    *in_htim1,
		TIM_HandleTypeDef    *in_htim3,
		TIM_HandleTypeDef    *in_htim8,

		UART_HandleTypeDef   *in_huart1,
		UART_HandleTypeDef   *in_huart2,
		UART_HandleTypeDef   *in_huart3,

		RTC_HandleTypeDef    *in_hrtc,
		SD_HandleTypeDef     *in_hsd
	)
{
	HAL_TIM_PWM_Start(in_htim3, TIM_CHANNEL_4);
	__HAL_TIM_SET_COMPARE(in_htim3, TIM_CHANNEL_4, UINT16_HALF);

	Pin graphLE = Pin(GRAPH_LE_GPIO_Port, GRAPH_LE_Pin);
	Pin graphOE = Pin(GRAPH_OE_GPIO_Port, GRAPH_OE_Pin);
	Pin pwmOE = Pin(PWM_OE_GPIO_Port, PWM_OE_Pin, ACTIVE_LOW);

	Pin enc1Sw = Pin(ENC1_SW_GPIO_Port, ENC1_SW_Pin, ACTIVE_LOW);
	Pin enc2Sw = Pin(ENC2_SW_GPIO_Port, ENC2_SW_Pin, ACTIVE_LOW);

	currentADCHandle = in_hadc1;
	currentADC_DMAHandle = in_hdma_adc1;

	stripI2cHandle = in_hfmpi2c1;
	dmaTXStripHandle = in_hdma_fmpi2c1_tx;

	i2cHandle = in_hi2c1;

	audioHandle = in_hi2s5;
	dmaRXAudioHandle = hdma_spi5_rx;

	rtcHandle = in_hrtc;
	sdHandle = in_hsd;
	graphHandle = in_hspi4;
	pwm1Handle = in_htim1;
	pwm3Handle = in_htim3;
	adcTimHandle = in_htim8;
	screenHandle = in_huart1;
	midiHandle = in_huart2;
	dmxHandle = in_huart3;


	encoder1 = RotaryEncoder(ENC1_A_GPIO_Port, ENC1_A_Pin, ENC1_B_GPIO_Port, ENC1_B_Pin, enc1Sw);
	encoder2 = RotaryEncoder(ENC2_A_GPIO_Port, ENC2_A_Pin, ENC2_B_GPIO_Port, ENC2_B_Pin, enc2Sw);

	encoder1.Init();
	encoder2.Init();

	shiftReg = ShiftRegs(graphHandle, graphOE, graphLE);
	stripCurr = StripCurrent(currentADCHandle, adcTimHandle, StripCurrentAlertCallback);
	stripCtrl = StripControl(&stripCurr);
	ledA = PCA9634(0x2A, stripI2cHandle, pwmOE);
	ledB = PCA9634(0x2A, stripI2cHandle, pwmOE);
	ledC = PCA9634(0x2A, stripI2cHandle, pwmOE);

	HAL_TIM_PWM_Start(pwm1Handle, TIM_CHANNEL_1);
	HAL_TIM_PWM_Start(pwm1Handle, TIM_CHANNEL_3);
	HAL_TIM_PWM_Start(pwm3Handle, TIM_CHANNEL_1);


//	HAL_GPIO_WritePin(GRAPH_LE_GPIO_Port, GRAPH_LE_Pin, GPIO_PIN_RESET);
//	HAL_GPIO_WritePin(GRAPH_OE_GPIO_Port, GRAPH_OE_Pin, GPIO_PIN_SET);

	settings = PCA9634Settings();
	settings.Driver = PCA9634_OUTPUT_DRIVER::TOTEM_POLE;
	settings.Invert = PCA9634_OUTPUT_LOGIC::INVERTED;
	ledA.ChangeSettings(settings);

	shiftReg.Init();

	if (stripCurr.Init() != HAL_OK)
	{
		return HAL_ERROR;
	}

	stripCtrl.Init();

	NextionCallbacks callbacks = NextionCallbacks();
	callbacks.PageChange = PageChangeCallbackHandle;
	callbacks.TouchEvent = TouchEventCallbackHandle;

	next.Startup(screenHandle, callbacks);
	screenCtrl.Init(&next, pages);
	screenCtrl.HomePage();

//	stripCtrl.Power(GPIO_PIN_SET);

//	HAL_I2S_Receive_DMA(audioHandle, (uint16_t*)audioBuffer, AUDIO_BUFFER_SIZE);

	__HAL_TIM_SET_COMPARE(pwm3Handle, TIM_CHANNEL_4, 0);
	return HAL_OK;
}

void InitTest()
{
//	shiftReg.IndicatorTest();
}

/**
  * @brief C++ Main Loop Function
  * @retval None
  */
void Main()
{
	indicator = !indicator;
	ledA.SetAll(indicator);
	__HAL_TIM_SET_COMPARE(pwm1Handle, TIM_CHANNEL_1, indicator ? UINT16_MAX / 2 : 0);
	__HAL_TIM_SET_COMPARE(pwm1Handle, TIM_CHANNEL_3, !indicator ? UINT16_MAX : 0);

	ledA.SetChannel(0, (uint8_t)(sin(count) * 127 + 127));
	ledA.SetChannel(1, (uint8_t)(cos(count) * 127 + 127));
	ledA.SetChannel(2, (uint8_t)(sin(count) * 127 + 64));

	ledA.Update();

	HAL_Delay(250);

//	stripCtrl.Check();
//
//	if (screenCtrl.CheckPage(1))
//	{
//		screenCtrl.ChangeText("t1", indicator ? AUDIO_SRC_BTN_XLR : AUDIO_SRC_BTN_JACK, 4);
//	}
//	else
//	{
//		screenCtrl.ChangeText("b0", indicator ? AUDIO_SRC_BTN_XLR : AUDIO_SRC_BTN_JACK, 4);
//	}
//
//	stripCtrl.Power(indicator ? GPIO_PIN_SET : GPIO_PIN_RESET);
//	HAL_Delay(500);
//	stripCtrl.Check();
//	ReadCurrent();
//	ReadAudioTest();
//	PCA9634Settings settings = ledA.ReadSettings();


//		OLD Testing
//	__HAL_TIM_SET_COMPARE(pwm3Handle, TIM_CHANNEL_2, 10000);
//
//	HAL_Delay(50);
//	screen.SetProgressBar(0, count);
//	__HAL_TIM_SET_COMPARE(pwm3Handle, TIM_CHANNEL_2, 20000);
//	screen.SetNumber(0, count);
//	__HAL_TIM_SET_COMPARE(pwm3Handle, TIM_CHANNEL_2, 30000);
//	HAL_Delay(50);
////	screen.SetPage(1);
//	__HAL_TIM_SET_COMPARE(pwm3Handle, TIM_CHANNEL_2, 40000);
////	for (size_t i = 0; i < 50; ++i)
////	{
////		uint8_t val = (uint8_t)round(sin(i) * 40 + 127);
////		screen.UpdateGraph(1, 0, val);
////		screen.SetNumber(0, val);
////	}
//	HAL_Delay(100);
//	__HAL_TIM_SET_COMPARE(pwm3Handle, TIM_CHANNEL_2, 50000);
////	HAL_Delay(250);
////	screen.HomePage();
//	__HAL_TIM_SET_COMPARE(pwm3Handle, TIM_CHANNEL_2, 60000);
//	count++;
//	if (count > 100)
//	{
//		count = 0;
//	}

//	static GPIO_PinState menuLeft = HAL_GPIO_ReadPin(MENU_LEFT_GPIO_Port, MENU_LEFT_Pin);
//	if (menuLeft != menuLeftPrev)
//	{
//		if (menuLeft == GPIO_PIN_SET)
//		{
//			shiftReg.SetValue(ON, MENU_LEFT_IND);
//		}
//		else
//		{
//			shiftReg.SetValue(OFF, MENU_LEFT_IND);
//		}
//	}
//	menuLeftPrev = menuLeft;

//		Screen Nav Testing

//
//	ReadCurrent();
//	shiftReg.Update();

//	next.CheckForTouchEvents();
}

void MenuUpInterruptCallback()
{
//	shiftReg.ToggleValue(MENU_UP_IND);
	screenCtrl.NavigateVert(-1);
}
void MenuDownInterruptCallback()
{
//	shiftReg.ToggleValue(MENU_DOWN_IND);
	screenCtrl.NavigateVert(1);
}
void MenuLeftInterruptCallback()
{
	screenCtrl.NavigateHorz(-1);
}
void MenuRightInterruptCallback()
{
//	shiftReg.ToggleValue(MENU_RIGHT_IND);
	screenCtrl.NavigateHorz(1);
}
void MenuActInterruptCallback()
{
	shiftReg.ToggleValue(8);
	screenCtrl.Act();
}
void MenuBackInterruptCallback()
{
	screenCtrl.HomePage();
}
void Enc1SwInterruptCallback()
{
	shiftReg.ToggleValue(6);
}
void Enc2SwInterruptCallback()
{
	shiftReg.ToggleValue(7);
}
void Enc1TurnInterruptCallback()
{
	encoder1.Decode();
	// Need to move to an "Encoder" class.
//	static GPIO_PinState enc1b = HAL_GPIO_ReadPin(ENC1_B_GPIO_Port, ENC1_B_Pin);
//	if (enc1b == GPIO_PIN_SET)
//	{
//
//	}
}
void Enc2TurnInterruptCallback()
{
	encoder2.Decode();
	// Need to move to an "Encoder" class.
//	static GPIO_PinState enc2b = HAL_GPIO_ReadPin(ENC2_B_GPIO_Port, ENC2_B_Pin);
}

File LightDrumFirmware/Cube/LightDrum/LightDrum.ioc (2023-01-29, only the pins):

Mcu.UserName=STM32F412VETx
PA0.GPIO_Label=XLR-SEL-IND
PA0.Signal=S_TIM2_CH1_ETR
PA1.GPIO_Label=HP-SEL-IND
PA1.Signal=S_TIM2_CH2
PA10.GPIO_Label=SCREEN-RX
PA10.Signal=USART1_RX
PA13.Signal=SYS_JTMS-SWDIO
PA14.Signal=SYS_JTCK-SWCLK
PA2.GPIO_Label=MIDI-TX
PA2.Signal=USART2_TX
PA3.GPIO_Label=MIDI-RX
PA3.Signal=USART2_RX
PA4.GPIO_Label=STRIP1-CURR
PA4.Signal=ADCx_IN4
PA5.GPIO_Label=STRIP5-CURR
PA5.Signal=ADCx_IN5
PA6.GPIO_Label=STRIP6-CURR
PA6.Signal=ADCx_IN6
PA7.GPIO_Label=STRIP2-CURR
PA7.Signal=ADCx_IN7
PA9.GPIO_Label=SCREEN-TX
PA9.Signal=USART1_TX
PB0.GPIO_Label=STRIP8-CURR
PB0.Signal=ADCx_IN8
PB1.GPIO_Label=STRIP4-CURR
PB1.Signal=ADCx_IN9
PB10.GPIO_Label=GRAPH-SCLK
PB10.Signal=SPI2_SCK
PB15.GPIO_Label=GRAPH-SDA
PB15.Signal=SPI2_MOSI
PB3.Signal=SYS_JTDO-SWO
PB6.Signal=I2C1_SCL
PB7.Signal=I2C1_SDA
PC10.Signal=GPIO_Output
PC11.Signal=GPIO_Output
PC12.Signal=GPIO_Input
PC4.GPIO_Label=STRIP3-CURR
PC4.Signal=ADCx_IN14
PC5.GPIO_Label=STRIP7-CURR
PC5.Signal=ADCx_IN15
PC6.GPIO_Label=PWM-OE
PC6.Signal=S_TIM3_CH1
PC7.GPIO_Label=DIAG-STATUS
PC7.Signal=S_TIM3_CH2
PC8.GPIO_Label=DIAG-DEBUG
PC8.Signal=S_TIM3_CH3
PC9.GPIO_Label=STRIP-PWR
PC9.Signal=S_TIM3_CH4
PD10.GPIO_Label=MENU-ACT
PD10.Signal=GPIO_Input
PD11.GPIO_Label=MENU-BACK
PD11.Signal=GPIO_Input
PD12.GPIO_Label=MENU-UP
PD12.Signal=GPIO_Input
PD13.GPIO_Label=GRAPH-LE
PD13.Signal=GPIO_Output
PD14.GPIO_Label=MENU-LEFT
PD14.Signal=GPIO_Input
PD15.GPIO_Label=GRAPH-OE
PD15.Signal=GPIO_Output
PD3.GPIO_Label=MENU-DOWN
PD3.Signal=GPIO_Input
PD4.GPIO_Label=ENC1-B
PD4.Signal=GPIO_Input
PD5.GPIO_Label=ENC1-SW
PD5.Signal=GPIO_Input
PD8.GPIO_Label=ENC2-SW
PD8.Signal=GPIO_Input
PD9.GPIO_Label=MENU-RIGHT
PD9.Signal=GPIO_Input
PE0.GPIO_Label=HP-VREF-IRQ
PE0.Signal=GPIO_Input
PE1.GPIO_Label=XLR-VREF-IRQ
PE1.Signal=GPIO_Input
PE10.GPIO_Label=HP-ADC-CS
PE10.Signal=GPIO_Output
PE12.Signal=SPI5_SCK
PE13.Signal=SPI5_MISO
PE14.Signal=SPI5_MOSI
PE3.GPIO_Label=VDDA-PGOOD
PE3.Signal=GPIO_Input
PE5.GPIO_Label=AUDIO-SRC-IND
PE5.Signal=S_TIM9_CH1
PE9.GPIO_Label=XLR-ADC-CS
PE9.Signal=GPIO_Output

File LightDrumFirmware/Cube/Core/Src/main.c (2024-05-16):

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
/* Includes ------------------------------------------------------------------*/
#include "main.h"
#include "fatfs.h"

/* USER CODE BEGIN Includes */
#include "MainWrapper.h"
/* USER CODE END Includes */

/* USER CODE BEGIN PD */
//#define USE_HAL_UART_REGISTER_CALLBACKS 1
/* USER CODE END PD */

ADC_HandleTypeDef hadc1;
DMA_HandleTypeDef hdma_adc1;

CRC_HandleTypeDef hcrc;

FMPI2C_HandleTypeDef hfmpi2c1;
DMA_HandleTypeDef hdma_fmpi2c1_tx;

I2C_HandleTypeDef hi2c1;

I2S_HandleTypeDef hi2s5;
DMA_HandleTypeDef hdma_spi5_rx;

RTC_HandleTypeDef hrtc;

SD_HandleTypeDef hsd;

SPI_HandleTypeDef hspi4;

TIM_HandleTypeDef htim1;
TIM_HandleTypeDef htim3;
TIM_HandleTypeDef htim6;
TIM_HandleTypeDef htim8;

UART_HandleTypeDef huart1;
UART_HandleTypeDef huart2;
UART_HandleTypeDef huart3;

/* USER CODE BEGIN PV */
uint32_t prevTick = 0;
uint32_t currentTick = UINT32_MAX;
uint8_t checkTick = 0;
/* USER CODE END PV */

void SystemClock_Config(void);
static void MX_GPIO_Init(void);
static void MX_DMA_Init(void);
static void MX_ADC1_Init(void);
static void MX_I2C1_Init(void);
static void MX_TIM3_Init(void);
static void MX_USART1_UART_Init(void);
static void MX_USART2_UART_Init(void);
static void MX_TIM6_Init(void);
static void MX_RTC_Init(void);
static void MX_SPI4_Init(void);
static void MX_FMPI2C1_Init(void);
static void MX_USART3_UART_Init(void);
static void MX_TIM1_Init(void);
static void MX_I2S5_Init(void);
static void MX_SDIO_SD_Init(void);
static void MX_TIM8_Init(void);
static void MX_CRC_Init(void);
/* USER CODE BEGIN 0 */
void HAL_IncTick(void)
{
  uwTick += uwTickFreq;
  if (uwTick == 0)
  {
	  prevTick = 0;
  }
}

void HAL_GPIO_EXTI_Callback(uint16_t GPIO_Pin)
{
	currentTick = HAL_GetTick();
	checkTick = prevTick + MENU_DEBOUNCE_WAIT < currentTick;
	prevTick = currentTick;
	switch (GPIO_Pin) {
		case ENC1_A_Pin:
			Enc1TurnInterruptCallback();
			break;
		case ENC2_A_Pin:
			Enc2TurnInterruptCallback();
			break;
		case MENU_UP_Pin:
			if (checkTick)
			{
				MenuUpInterruptCallback();
			}
			break;
		case MENU_DOWN_Pin:
			if (checkTick)
			{
				MenuDownInterruptCallback();
			}
			break;
		case MENU_LEFT_Pin:
			if (checkTick)
			{
				MenuLeftInterruptCallback();
			}
			break;
		case MENU_RIGHT_Pin:
			if (checkTick)
			{
				MenuRightInterruptCallback();
			}
			break;
		case MENU_ACT_Pin:
			if (checkTick)
			{
				MenuActInterruptCallback();
			}
			break;
		case MENU_BACK_Pin:
			if (checkTick)
			{
				MenuBackInterruptCallback();
			}
		default:
			break;
	}
}

void HAL_I2SEx_TxRxCpltCallback(I2S_HandleTypeDef *hi2s)
{
	AudioFullCallback();
}

//void HAL_I2SEx_TxRxHalfCpltCallback(I2S_HandleTypeDef *hi2s)
//{
//	AudioHalfFullCallback();
//}

void HAL_I2S_RxCpltCallback(I2S_HandleTypeDef *hi2s)
{
	AudioFullCallback();
}

void HAL_ADC_ConvCpltCallback(ADC_HandleTypeDef* hadc)
{
	CurrentConvFullCallback();
}

//void HAL_UARTEx_RxEventCallback(UART_HandleTypeDef *huart, uint16_t Size)
//{
//	ScreenReceiveCallback();
//}
/* USER CODE END 0 */

/**
  * @brief  The application entry point.
  * @retval int
  */
int main(void)
{
  /* MCU Configuration--------------------------------------------------------*/

  /* Reset of all peripherals, Initializes the Flash interface and the Systick. */
  HAL_Init();

  /* Configure the system clock */
  SystemClock_Config();

  /* Initialize all configured peripherals */
  MX_GPIO_Init();
  MX_DMA_Init();
  MX_ADC1_Init();
  MX_I2C1_Init();
  MX_TIM3_Init();
  MX_USART1_UART_Init();
  MX_USART2_UART_Init();
  MX_TIM6_Init();
  MX_RTC_Init();
  MX_SPI4_Init();
  MX_FMPI2C1_Init();
  MX_USART3_UART_Init();
  MX_TIM1_Init();
  MX_I2S5_Init();
  MX_SDIO_SD_Init();
  MX_FATFS_Init();
  MX_TIM8_Init();
  MX_CRC_Init();
  /* USER CODE BEGIN 2 */


//  HAL_GPIO_WritePin(DIAG_DEBUG_GPIO_Port, DIAG_DEBUG_Pin, GPIO_PIN_RESET);
  if (Init(
		  &hadc1,
		  &hdma_adc1,

		  &hfmpi2c1,
		  &hdma_fmpi2c1_tx,

		  &hi2c1,

		  &hi2s5,
		  &hdma_spi5_rx,

		  &hspi4,

		  &htim1,
		  &htim3,
		  &htim8,

		  &huart1,
		  &huart2,
		  &huart3,

		  &hrtc,
		  &hsd
  ) != HAL_OK)
  {
	  Error_Handler();
  }

  // For Init tests
  InitTest();
  /* USER CODE END 2 */

  /* Infinite loop */
  /* USER CODE BEGIN WHILE */
  while (1)
  {
	  Main();
    /* USER CODE END WHILE */

    /* USER CODE BEGIN 3 */
  }
  /* USER CODE END 3 */
}

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


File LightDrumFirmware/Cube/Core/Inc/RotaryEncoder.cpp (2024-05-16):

/*
 * RotaryEncoder.cpp
 *
 *  Created on: May 28, 2023
 *      Author: Daxxn
 */

#include <RotaryEncoder.h>

RotaryEncoder::RotaryEncoder(GPIO_TypeDef *portA, uint16_t pinA, GPIO_TypeDef *portB, uint16_t pinB, Pin switchPin)
{
	this->portA = portA;
	this->portB = portB;
	this->pinA = pinA;
	this->pinB = pinB;
	this->switchPin = switchPin;
}

RotaryEncoder::~RotaryEncoder()
{
}

HAL_StatusTypeDef RotaryEncoder::Init()
{
	prevStateA = HAL_GPIO_ReadPin(portA, pinA);
	prevStateB = HAL_GPIO_ReadPin(portB, pinB);
	return HAL_OK;
}

void RotaryEncoder::Decode()
{
	this->currStateA = HAL_GPIO_ReadPin(this->portA, this->pinA);
	this->currStateB = HAL_GPIO_ReadPin(this->portB, this->pinB);

	if (this->currStateA == 1)
	{
		if (this->currStateA != this->prevStateA)
		{
			if (this->currStateB == 0)
			{
				this->position++;
				this->direction = CW;
			}
			else
			{
				this->position--;
				this->direction = CCW;
			}
		}
	}

	this->prevStateA = this->currStateA;
	this->prevStateB = this->currStateB;
}

uint16_t RotaryEncoder::GetPosition()
{
	return this->position;
}

Direction RotaryEncoder::GetDirection()
{
	return this->direction;
}

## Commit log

2023-01-01 Add docs
    [ActualFilterValues.ods, LEDController-REV1.csv, LEDController-REV2.csv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]
2023-01-01 Add the rest of the docs
    [LEDController-REV3.csv, LEDController-REV4.csv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]
2023-01-01 Replace interface harnesses with FPC cable
    [ADC_Sheet.kicad_sch, ActiveFilters_1-4.kicad_sch, ActiveFilters_5-8.kicad_sch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]
2023-01-01 Add extra vcc pin to FPC conn
    [Interface_Connectors.kicad_sch, LightDrum.kicad_sch]
2023-01-02 Add docs and gerbers for REV7
    [ADC_Sheet.kicad_sch, ActiveFilters_1-4.kicad_sch, ActiveFilters_5-8.kicad_sch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]
2023-01-02 Remove un-zipped gerber files for REV5
    [LightDrum-B_Cu.gbl, LightDrum-B_Mask.gbs, LightDrum-B_Paste.gbp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]
2023-01-02 Add logo to interface PCB
    [Light-Drum-Interface_REV3.FCStd, LightDrumInterface.kicad_pcb, LightDrumREV7.FCStd]
2023-01-08 Replace screen (WIP)
    [Interface_Connectors.kicad_sch, LightDrum.kicad_sch, LightDrumInterface.kicad_sch]
2023-01-08 Replaced display and FPC cable
    [Interface_Connectors.kicad_sch, Light-Drum-Interface_REV3.FCStd, LightDrum.kicad_sch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]
2023-01-14 First pass over schematic (WIP)
    [ADC_Sheet.kicad_sch, ActiveFilters.kicad_sch, ActiveFilters_1-4.kicad_sch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]
2023-01-14 Clean up and remove old files
    [ADC_Sheet.kicad_sch, Audio-Inputs.kicad_sch, AudioFilters_Sheet.kicad_sch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]
2023-01-15 General component placement
    [Audio-Inputs.kicad_sch, Battery-Charger.kicad_sch, Interface_Connectors.kicad_sch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]
2023-01-15 Replace with smaller case (WIP)
    [Battery-Charger.kicad_sch, Interface_Connectors.kicad_sch, LightDrum.kicad_pcb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]
2023-01-16 Simplify analog power supply and add some routing
    [Audio-Inputs.kicad_sch, Interface_Connectors.kicad_sch, LED_Power_Control.kicad_sch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]
2023-01-21 Remove RTC and battery
    [LightDrum.kicad_sch, LightDrumInterface.kicad_sch]
2023-01-21 Swap mcu again... (WIP)
    [Interface_Connectors.kicad_sch, LightDrum.kicad_sch, Power.kicad_sch]
2023-01-22 Replace barrel jacks with proper DIN4 conn and more
    [Audio-Inputs.kicad_sch, Interface_Connectors.kicad_sch, LED_Power_Control.kicad_sch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]
2023-01-22 Replace old MOSFETs with a more compact package
    [Audio-Inputs.kicad_sch, LED_Power_Control.kicad_sch, LightDrum.kicad_pcb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]
2023-01-23 Lock REV8 Layout and send to PCB MNF
    [Audio-Inputs.kicad_sch, LED_Power_Control.kicad_sch, LightDrum REV8 Power Budget.ods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]
2023-01-28 Replace old MCU W/ STM32F412
    [Audio-Inputs.kicad_sch, LightDrum.kicad_sch, Power.kicad_sch]
2023-01-29 Replace MCU finished. REV9
    [Audio-Inputs.kicad_sch, Interface_Connectors.kicad_sch, LED_Power_Control.kicad_sch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]
2023-01-29 Fix DRC issues - Main Board - REV9
    [LightDrum.kicad_sch]
2023-01-29 interface layout completed - REV6
    [Audio-Inputs.kicad_sch, Interface_Connectors.kicad_sch, LightDrum.kicad_sch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]
2023-01-30 Main and Interface PCBs locked - REV9
    [ActualFilterValues.ods, Audio-Inputs.kicad_sch, Interface_Connectors.kicad_sch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]
2023-02-05 Add main page to sch and xlr audio input diff-amp
    [Audio-Inputs.kicad_sch, LightDrum.kicad_sch, Micro.kicad_sch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]
2023-02-06 Change flags in sch
    [Micro.kicad_sch]
2023-02-12 Start REV 10 - Fix small issues
    [Audio-Inputs.kicad_sch, LED_Power_Control.kicad_sch, LightDrum-REV9.csv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]
2023-02-13 Add ind shift reg driver and fix LED MOSFET pin mixup
    [Micro.kicad_sch, Power.kicad_sch]
2023-02-13 Add button code and configure IRQs
    [DisplayColors.csv, Micro.kicad_sch]
2023-02-13 Update display colors file
    [DisplayColors.csv]
2023-02-13 Fix display colors save file
    [DisplayColors.xlsx]
2023-03-10 Update save files to KiCad 7
    [Audio-Inputs.kicad_sch, Interface_Connectors.kicad_sch, LED_Power_Control.kicad_sch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]
2023-03-10 Fix BOM generator options
    [LightDrumInterface.kicad_pcb]
2023-04-03 Add RTC
    [Micro.kicad_sch]
2023-04-03 Fix drill reference
    [ClearCaseDrillReference.kicad_pcb, ClearCaseDrillReference.kicad_sch]
2023-04-03 Replace relays and SWD conn
    [ClearCaseDrillReference.kicad_pcb, LED_Power_Control.kicad_sch, LightDrum.kicad_sch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]
2023-04-09 Preliminary schematic lock - Starting PCB layout
    [Audio-Inputs.kicad_sch, Interface_Connectors.kicad_sch, LED_Power_Control.kicad_sch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]
2023-04-10 Component placement complete
    [Audio-Inputs.kicad_sch, Interface_Connectors.kicad_sch, LED_Power_Control.kicad_sch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]
2023-04-12 Continuing layout
    [Audio-Inputs.kicad_sch, LightDrum.kicad_pcb]
2023-04-13 First draft layout almost complete
    [Interface_Connectors.kicad_sch, LightDrum.kicad_sch, Micro.kicad_sch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]
2023-04-15 PCB Lock REV11
    [Interface_Connectors.kicad_sch, Light-Drum-Interface_REV7.FCStd, LightDrum.kicad_sch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]
2023-04-17 Minor fixes and cleanup - REV11
    [Audio-Inputs.kicad_sch, Micro.kicad_sch, Power.kicad_sch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]
2023-04-30 Fix backwards Connector - Initial Testing
    [Audio-Inputs.kicad_sch, LightDrumInterface.kicad_pcb, LightDrumInterface.kicad_sch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]
2023-05-08 Replace DSub with much better ECU conn
    [Audio-Inputs.kicad_sch, Interface_Connectors.kicad_sch, LED_Power_Control.kicad_sch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]
2023-05-08 Rename old LED strip pinout file
2023-05-08 Organize old files and generate interface gerbers
    [Audio-Inputs.kicad_sch, Interface_Connectors.kicad_sch, LightDrum.kicad_sch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]
2023-05-08 Fix MCU pinout in IDE
    [LightDrum.ioc, main.c, main.h]
2023-05-09 Fix schematic layout
    [Audio-Inputs.kicad_sch, Interface_Connectors.kicad_sch, LED_Power_Control.kicad_sch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]
2023-05-09 Add code for PCA9634 and gen gerbers
2023-05-21 (WIP) REV12 Testing and firmware dev
    [Audio-Inputs.kicad_sch, DisplayColors.xlsx, Interface_Connectors.kicad_sch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]
2023-05-28 add screen control and more display layout
    [DisplayColors.csv, DisplayColors.xlsx, LightDrumInterface.kicad_pcb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]
2023-05-29 fix screen ctrl bugs and add I2S data transfer
    [DisplayColors.xlsx, Strip_Connector.kicad_sch]
2024-05-16 old version save
    [Audio-Inputs.kicad_sch, Interface_Connectors.kicad_sch, LED_Power_Control.kicad_sch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]
2024-05-16 REV13 - Revert to KiCAD 7
    [Audio-Inputs.kicad_sch, Interface_Connectors.kicad_sch, LED_Power_Control.kicad_sch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]
2024-05-16 REV13 - Update to KiCAD 8
    [Audio-Inputs.kicad_sch, Interface_Connectors.kicad_sch, LED_Power_Control.kicad_sch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]

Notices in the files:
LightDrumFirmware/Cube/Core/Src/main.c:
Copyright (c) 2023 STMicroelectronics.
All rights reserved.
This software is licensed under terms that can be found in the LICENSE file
